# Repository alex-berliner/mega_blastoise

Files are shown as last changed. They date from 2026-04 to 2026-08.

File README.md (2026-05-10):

# mega_blastoise

**[▶ Play live](https://alex-berliner.github.io/mega_blastoise/)** — browser-based Gen 1 random battle simulator

Workspace layout: `mega_blastoise_core` (no_std + battle data), `mega_blastoise_fw` (RP2040), `mega_blastoise_test` (PC).

Architecture overview: see [architecture/README.md](./architecture/README.md).

## Documentation

- [DESIGN.md](./DESIGN.md) — project overview, gameplay, hardware summary, and status
- [ELECTRONICS.md](./ELECTRONICS.md) — GPIO map, wiring, power budget, physical layout
- [TECHNICAL.md](./TECHNICAL.md) — software internals, crate layout, interfaces, data flow
- [specs.md](./specs.md) — full specification and architecture reference
- [architecture/](./architecture/README.md) — deep-dive architecture docs (7 pages)

## Docker / Podman

Run the interactive battle without installing Rust or any native deps:

```bash
# Build once
podman build -t mega-blastoise-test .   # or: docker build ...

# Play
podman run -i --rm mega-blastoise-test
```

`-i` is required — the binary reads moves from stdin.

## Run modes (`mega-blastoise-test`)

The host binary is **interactive only**: stdin battle with the same **typed `BoardEvent` → `BoardEffects`** path as firmware (queue, prompts, combat log).

| Mode | Command | What it does |
|---|---|---|
| **Interactive** (default) | `cargo run -p mega-blastoise-test`<br>`cargo run -p mega-blastoise-test --release` | Full battle over stdin (pick moves / switches when prompted). |
| **Automated tests** | `cargo test -p mega-blastoise-test` | Runs Rust tests (board-event parsing, scripted effect pipeline, demo battle init). Pass/fail exit status. |

Firmware (`mega-blastoise-fw`) has no CLI modes; flash and run as usual (see below).

## Compile

From this directory (`mega_blastoise/mega_blastoise/`, where the workspace `Cargo.toml` lives):

**PC test (host):**

```bash
cargo build -p mega-blastoise-test
cargo run -p mega-blastoise-test
```

Add `--release` to `cargo run` for a faster binary. See **Run modes** for `cargo test`.

**Pico / RP2040 firmware:** install the Rust target once:

```bash
rustup target add thumbv6m-none-eabi
```

Then either pass the target explicitly (recommended when building from the **workspace root** — Cargo does not apply `mega_blastoise_fw/.cargo/config.toml`’s default target for `-p` builds):

```bash
cargo build -p mega-blastoise-fw --target thumbv6m-none-eabi
cargo build -p mega-blastoise-fw --target thumbv6m-none-eabi --release
```

**Firmware size stats** (prints section totals after link — install `rustup component add llvm-tools-preview` for `llvm-size`, or use `arm-none-eabi-size` from the GNU Arm toolchain):

```bash
./scripts/fw-build.sh                    # debug + llvm-size -t / -A
PROFILE=release ./scripts/fw-build.sh    # release build + stats
./scripts/fw-build.sh --release          # same (cargo passes --release)
```

Debug binaries include large `.debug_*` sections, so `llvm-size` totals look huge; prefer **`./scripts/fw-build.sh --release`** when checking flash/RAM against the Pico.

Or `cd` into the firmware crate so its `.cargo/config.toml` sets `thumbv6m-none-eabi` automatically:

```bash
cd mega_blastoise_fw
cargo build
cargo build --release
```

Flash/run with `probe-rs` as configured in `mega_blastoise_fw/.cargo/config.toml`.

**Install `probe-rs`:** download and run the latest installer from the [probe-rs releases page](https://github.com/probe-rs/probe-rs/releases), then reload your shell:

```bash
curl --proto '=https' --tlsv1.2 -LsSf https://github.com/probe-rs/probe-rs/releases/latest/download/probe-rs-tools-installer.sh | sh
source ~/.bashrc   # or ~/.zshrc
```

Then flash with a debug probe connected (e.g. Picoprobe, CMSIS-DAP):

```bash
cd mega_blastoise_fw
cargo run --release
```

### PN532 readers (firmware)

Two **PN532** modules on separate I²C buses (`I2C0` + `I2C1`), default address **0x24** each:

| Bus | SCL (GP) | SDA (GP) |
|-----|---|---|
| I2C0 (reader 0) | GP17 | GP16 |
| I2C1 (reader 1) | GP19 | GP18 |

Startup spawns two embassy tasks that periodically exchange **GetFirmwareVersion** and discard the reply — bring-up traffic only until NFC handling lands.

### Breadboard power (PN532 + Pico)

PN532 boards draw noticeable current when the RF field is active; pulling both from the Pico’s **3V3** pin alone can brown out the Pico regulator or cause flaky I²C.

**Plan for the breadboard stage:**

1. **External brick** — Use a small DC supply (e.g. barrel jack wall wart into a **buck module** or **LM2596-style** board) that exposes stable **5&nbsp;V** and/or **3.3&nbsp;V** rails at enough current for **both** readers plus headroom (hundreds of mA total is a comfortable target for NFC bring-up).

2. **Power the readers from that rail**, not from Pico **3V3**:
   - Many PN532 breakouts accept **5&nbsp;V** on **VIN** and regulate down on-board; follow your module’s silkscreen.
   - If the breakout is **3.3&nbsp;V only**, power it from the external **3.3&nbsp;V** output of the same supply family (not from the Pico pin).

3. **Single ground reference** — Tie **GND** from the barrel/supply module, **Pico GND**, and **both reader GNDs** on one common ground net (breadboard negative rail). I²C only works if grounds are shared.

4. **Pico supply during development** — Easiest: power the Pico over **USB** for flashing/debug while the **external supply feeds only the NFC modules** (still with common GND). Alternatively, feed **5&nbsp;V** into **VSYS** through an appropriate Schottky diode arrangement per Pico docs if you want fully standalone power (more breadboard care).

5. **I²C levels** — RP2040 GPIO is **3.3&nbsp;V** logic. PN532 I²C on common breakouts is 3.3&nbsp;V tolerant; if you ever used a 5&nbsp;V‑only I²C module you would need level shifting (most PN532 boards are 3.3&nbsp;V I²C).

Keep high‑current paths short on the breadboard and avoid routing reader supply current through the Pico pins.

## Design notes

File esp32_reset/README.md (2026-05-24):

# esp32_reset

A tiny hardware recovery line. When an RP2040 in the rig wedges so hard that
nothing software-side can reach it, this ESP32 yanks its `RUN` pin low for
~100 ms to force a clean power-on reset.

Targets: the player **Pico** and the **debug probe** (a Pico running
debugprobe). Triggered by a magic byte over USB.

Standalone crate — **not** in the root workspace (different toolchain +
target). Build it from inside this directory.

## Hardware

DOIT ESP32 DevKit V1 (original ESP32 / WROOM-32, Xtensa). The trigger
arrives over the onboard CP2102 USB↔UART bridge on UART0 — the original
ESP32 has no native USB.

```text
  ESP32 GPIO25 ───────────────► Pico   RUN  (Pico pin 30)
  ESP32 GPIO26 ───────────────► Probe  RUN  (probe Pico pin 30)
  ESP32 GND    ───────────────► common GND   (REQUIRED)
```

- Lines are **open-drain**: ESP32 only ever pulls `RUN` low or floats it
  (Hi-Z). It never drives high. If the ESP32 is unplugged, crashed, or in
  its bootloader, every line is Hi-Z and each RP2040's internal ~50 kΩ
  `RUN` pull-up keeps it running. The fail-safe is structural — no MOSFET,
  no external pull-up, no firmware needed for the safe state.
- A 220 Ω–1 kΩ series resistor per line is an optional nice-to-have for
  protection; not required.
- GPIO25/26 chosen because they're Hi-Z input at power-on, not strapping
  pins, and don't glitch at boot — the ESP32's own power-up can't trip a
  reset.
- **Common ground is mandatory.** Without it, none of this works.

> Bridging instead of separate pins also works (one line to both `RUN`s,
> resets together) — but two pins gives independent reset and avoids one
> powered target weakly back-feeding an unpowered one's `RUN`.

## Protocol

Magic bytes on UART0 @ 115200 (the same port you flash/monitor):

| byte | action |
|---|---|
| `p`  | reset the Pico |
| `d`  | reset the debug probe |
| `b`  | reset both |

Any other byte is ignored, so stray console noise is harmless. Each
accepted command echoes a one-line ack (`RST pico` / `RST probe` /
`RST both`).

## Build & flash

One-time Xtensa toolchain setup (the original ESP32 isn't supported by
upstream Rust):

```sh
cargo install espup espflash
espup install
source ~/export-esp.sh        # add to your shell rc; needed every build shell
```

Then, from this directory:

```sh
cargo run --release           # builds, flashes, opens the monitor
```

`cargo run` uses `espflash flash --monitor` (see `.cargo/config.toml`).
Plain build only: `cargo build --release`.

> esp-hal's API moves fast between releases. Versions are pinned in
> `Cargo.toml` against esp-hal 0.23.x; if a future `espup` toolchain pulls
> incompatible crates, bump the pins together and adjust the few HAL calls
> in `src/main.rs` (init / GPIO / UART).

## Triggering from the host

```sh
./reset.sh pico            # or: probe | both
PORT=/dev/ttyUSB1 ./reset.sh both
```

Or by hand: `printf 'p' > /dev/ttyUSB0` (after `stty -F /dev/ttyUSB0
115200 raw`).

Note: opening the port may toggle DTR/RTS and reset the *ESP32* itself
(not the targets) — harmless, it just re-prints the ready banner.
`reset.sh` uses raw mode to minimize this.

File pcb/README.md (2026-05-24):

# pcb/ — code-defined PCB design

Source-of-truth for the mega_blastoise board wiring as an atopile
project. Mirrors what's described in `../ELECTRONICS.md` but in a form
that a tool can render into a KiCad schematic, BOM, and netlist.

This is the "PCB version" of the design. The current build path is
stripboard + hand wiring (see memory `feedback_stripboard_preference`);
this directory exists so the connectivity is captured as code and so a
fabbed board is a `ato build` away if/when that path makes sense.

## Tool choice

[atopile](https://atopile.io) — purpose-built, code-first DSL for
hardware, designed around the same parametric / source-as-truth
philosophy as `cad/`. Outputs a KiCad 7+ project.

Alternatives considered:

- **SKiDL** (Python library): more mature but writes netlists, not
  full KiCad projects. Pick this if you want to drive layout in
  Python from existing KiCad libraries.
- **KiCad Python API**: scripts existing KiCad — best for layout
  automation, not for from-scratch design.

## Layout

```
pcb/
├── README.md              (this file)
├── ato.yaml               (atopile project config)
└── elec/src/
    └── mega_blastoise.ato (top-level design)
```

## Build

```bash
# one-time
pip install atopile
cd pcb
ato install               # pull standard part library

# every time
ato build                 # emits KiCad project to build/default/
```

Open `build/default/<project>.kicad_pro` in KiCad to inspect the
schematic and lay out the board.

## What's modelled

- Raspberry Pi Pico (treated as a daughterboard, all 26 usable GPIO
  exposed)
- 2x SSD1306 OLED breakouts on independent I2C buses (GP16/17 and
  GP18/19), each with a 100 nF decoupling cap
- 14x tactile buttons arranged as a 4x4 matrix on GP6..GP13
- WS2812B NeoPixel strip header on GP20 with a 330R series resistor on
  data and a 470 uF bulk cap across V5/GND at the strip entry
- Piezo buzzer on GP21
- Power stage: JST-PH LiPo connector + TP4056 charge module + MT3608
  boost (preset to 5 V) + SPDT slide switch -> V5 rail
- Reset button across RUN -> GND (see memory
  `project_reset_button`)
- Error LED stub on GP22 (see memory `project_error_led`) — needs an
  `LED` part imported before `ato build` will succeed

## Known gaps before fabbing

The `.ato` file uses local `component` stubs for the bigger
parts (Pico, OLEDs, TP4056, MT3608, slide switch, JST, headers,
buttons, buzzer). Each one declares only pins and a footprint
hint. Before `ato build` will produce a fabricable board you'll
need to either:

1. swap each stub for a registry-backed `component` (`ato install`
   then `from ... import ...`), or
2. fill in the `footprint` / `mpn` fields and add KiCad symbols
   under `elec/footprints/`.

The connectivity is fully expressed; the work above is part-library
plumbing, not design work.

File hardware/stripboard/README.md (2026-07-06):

# Button matrix - stripboard layout

Permanent stripboard (Veroboard) version of the 4x4 button matrix, replacing the
flaky breadboard build. 14x 6 mm tactile switches, soldered.

Oriented for Alex's board: **strips run vertically, one continuous rail per
letter column (A..X across the top, holes 1..55 down the side).** The layout drops
onto the top of that board, full width (letters A..X), using roughly the first
22 holes.

## Files
- **`mega_blastoise_matrix.diy`** - the matrix layout, for **DIYLC** (DIY Layout
  Creator). Authoritative source for the board: every switch, track cut, jumper.
- **`mega_blastoise_matrix_full.diy`** - the **full system**: the matrix plus
  switch bodies, the Raspberry Pi Pico (40-pin DIL stand-in), both SSD1306 OLEDs,
  both WS2812B strips, the buzzer, all the signal + power wiring, and a parts list.
- **`*_preview.png`** - quick renders of each.
- **`gen_matrix_diy.py`** / **`gen_matrix_full_diy.py`** - regenerate the `.diy`s
  (edit geometry here, not the XML). The full one imports the matrix one.
- **`preview_strip.py`** / **`preview_full.py`** - regenerate the preview PNGs.
- **`verify_matrix.py`** - netlist check of the matrix.

## Opening it
DIYLC is a single jar (needs Java). From the DIYLC folder:
```
java -jar diylc.jar hardware/stripboard/mega_blastoise_matrix.diy
```
(or launch DIYLC and File -> Open). Print at 100 % scale to lay the board on top.

## How the matrix maps to copper
Strips run **vertically** (down the columns), so each vertical letter-strip is one
continuous rail. The matrix uses two kinds of strip:

- **Bus strips** (a whole row net, never cut): one letter each.
  - **GP5** (P1 moves) = strip **V** | **GP7** (P1 party) = strip **P**
  - **GP8** (P2 moves) = strip **J** | **GP9** (P2 party) = strip **D**
- **Node strips** (letters **A, G, M, S**): each carries the column-legs of one
  row net and is **cut between rows** so every column gets an isolated node. The
  four columns are then tied together by **horizontal jumper wires** (the col
  nets **GP10..GP13**), one jumper row per matrix column.

Each switch straddles a bus strip and the node strip 3 letters to its left
(A<->D, G<->J, M<->P, S<->V): both legs of the row terminal land on the bus
strip, both legs of the col terminal on the node strip.

Pico physical-pin numbers below are the RP2040 board's actual header pins (all
on the left column; the Pico puts a GND at every 5th pin, e.g. pins 8 and 13,
which is why the numbering skips).

| Matrix row | Bus strip | | Matrix col | Net | run as |
|---|---|---|---|---|---|
| P1 moves (M1-M4) | **GP5** (pin 7) | | col 0 | **GP10** (pin 14) | jumper row |
| P1 party (S1-S3) | **GP7** (pin 10) | | col 1 | **GP11** (pin 15) | jumper row |
| P2 moves (M1-M4) | **GP8** (pin 11) | | col 2 | **GP12** (pin 16) | jumper row |
| P2 party (S1-S3) | **GP9** (pin 12) | | col 3 | **GP13** (pin 17) | jumper row |

col 3 exists only on the move rows (party rows have 3 buttons).

## Build order
1. **Cut the board** to size (24 wide x ~24 tall is plenty; letters A..X).
2. **Make the track cuts** - every red X in the `.diy`. They sit on the node
   strips (A, G, M, S), between adjacent column groups, isolating each column
   node. Spot cutter or a 3 mm drill twirled by hand; verify each with a meter.
3. **Solder the column jumpers first** (blue horizontals). They run *under* the
   switch bodies, so they go down before the switches. Insulated wire on the
   component side; solder only where they cross a node strip (A/G/M/S), kept
   raised/insulated over the bus strips in between.
4. **Solder the 14 switches.** Solder **all four legs**: the two on the bus-strip
   side become the row terminal, the two on the node-strip side become the col
   terminal (the marked green/blue pair just shows one leg of each). Because both
   legs of a terminal share a strip, this is more robust than the breadboard
   "bend two diagonal legs" trick.
5. **Solder the 8 header wires** (ribbon) to the orange pads -> Pico. Rows exit on
   the bus strips (**GP5/7/8/9**, top of the board); columns exit on the node
   strips at the left (**GP10-GP13**).
6. **Continuity test**: pressing a button connects its row net to its column net
   and *nothing else*.

## Switch footprint
6 mm tactile switches have a ~4.5 x 6.5 mm leg pattern = a **0.2" x 0.3" (3 x 4
hole)** rectangle on the 0.1" grid. This layout matches that: the two legs of one
terminal sit **0.2" (2 holes)** apart along a strip, and the two terminals sit
**0.3" (3 holes / 3 letters)** apart across strips. If your switches measure
differently, edit `VSPAN` / `HSPAN` at the top of `gen_matrix_diy.py` and re-run;
everything else (cuts, jumpers, nets) is footprint-independent.

## Verification
`gen_matrix_diy.py` was checked with a netlist model (strips + cuts + jumpers +
every leg -> union-find nets): all 14 switches connect exactly their row GPIO to
their col GPIO, 8 nets total, no stray shorts.

## Single-board build (whole console on one 24x55 board) - rev 3

> **Building it? Follow [BUILD.md](BUILD.md)** - step-by-step instructions
> (cut list, wire list, solder order, continuity tests) generated from the
> verified model by `gen_build_doc.py`. Regenerate it whenever the layout
> changes.

Column lettering matches the grid **printed on the physical board**: viewed
from the component side (copper down) the printed letters read **X left ->
A right**; they read A..X left-to-right only with the copper side facing you.
All diagrams and docs use the component-side view.
`gen_single_board.py` puts **everything on one stripboard**, arranged for two
players **facing each other** across the board. Outputs
`mega_blastoise_single_board.diy` (+ `_preview.png`). Board top to bottom:

- **P2 module (rotated 180deg)**: party row S3 S2 S1, moves M4 M3, screen
  (header at its bottom edge), moves M2 M1. From P2's seat it reads exactly
  like P1's module. No firmware flip needed: the physical rotation and P2's
  opposite viewing angle cancel out.
- **P1 module**: moves M1 M2, screen (header at its top edge), moves M3 M4,
  party row S1 S2 S3.
- The 4 move buttons of each player sit at the **four corners of their screen**,
  matching where the moves render on the OLED; the 3 party buttons share a row.
- **LED strip connectors on the left edge (col X)**: P2's at the top (rows
  2/5/8), P1's at the bottom (rows 41/44/47), each DIN/5V/GND - out of the
  play area; the WS2812B strips are off-board.
- **holes 47-54**: the **Pico, on the TOP side, USB pointing LEFT** (pin 1 =
  GP0 bottom-left; VBUS n/c), isolation cut lines at holes 46 and 50.
- **hole 53**: **MB102 5V input** - "-" on the left (B), "+" on the right (A).
- **rails**: GND = col W, 3V3 = col B, 5V = col A. MB102 feeds the 5V rail for
  the LED strips; the Pico runs from USB; grounds are shared. (No buzzer.)

All ~41 jumper wires are meant to be routed on the **underside** so the top
stays clean. The `verify()` in the script proves the netlist by union-find
(strips + cuts + jumpers + every pad) and also checks that no hole takes two
wire ends - it must report PASS before the `.diy` is written.

## Firmware
Matches the shipped firmware pin map (`main.rs`): rows GP5/7/8/9, cols GP10-13.
No firmware change needed - drop-in replacement for the breadboard matrix.

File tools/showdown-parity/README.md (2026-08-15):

# Showdown parity

Differential tests: the core engines (`gen1_battle`, `gen3_battle`) against
the real Pokémon Showdown simulator.

    cd tools/showdown-parity && npm install     # arm (one-time, needs network)
    cargo test -p mega-blastoise-test --test showdown_parity

Unarmed checkouts skip the suite loudly and stay green.

Randomness is scripted on both sides, not disabled: each scenario fixes
hit/miss, crit, and the exact damage roll, the harness forces the sim down
that branch (accuracy at the old-gen `randomChance` seam, the roll at
`randomizer`/`random(217,256)`, crits via `willCrit`), and the Rust side takes
the same script through its `*_scripted` seams. Misses spending PP, crit
stage/screen rules, and both roll extremes are all first-class comparisons.

Found on its first runs: two transposed cells in type-chart.json (shipped in
Gen 1 as Bug->Rock x0.5 and Fighting->Dragon x2), Shedinja's 1 HP rule,
the Gen 3 damage roll applying last rather than before STAB, the +2 landing
after burn/screen halving, and one wrong patch added from memory during the
fixing (gen 1 Bug->Ghost is resisted, not super effective).

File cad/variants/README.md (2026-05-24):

# CAD variants

Each `*.scad` here is a complete, standalone enclosure design. Work happens
in these files. **`cad/board.scad` is just a copy of whichever variant is
currently being shown** — the "now showing" / display slot. Don't hand-edit
`board.scad`; edit the variant, then it gets copied up.

Workflow: edit `variants/<name>.scad` → validate via the METHODOLOGY
render+assert loop → `cp variants/<name>.scad ../board.scad` to make it the
active view.

## Variants

| File | Display | Notes |
|---|---|---|
| `dual-oled-128x64.scad` | 2× 128×64 mono SSD1306 (I²C), one per player | Web-mirrored layout: OLED + 4 corner move btns + 3-switch row + 1 HP LED + 3 party LEDs per player; centred buzzer. ~71×133×13.5 mm. The committed baseline. |
| `single-st7789.scad` | 1× ST7789 240×240 colour TFT (SPI), shared central | Per-player button block (4 move + 3 switch) + LEDs flanking the screen; buzzer beside display. Colour → sprites. Shared screen = upright for one player only (suits a Stadium-style shared battle view). ~68×121×13.5 mm. |
| `single-st7789-nfc.scad` | ST7789 (as above) + NFC coin select | Drops the 3 switch buttons; per player an octagonal recess (≈24.8 mm, 0.9 mm floor so NFC reads through) + thumb notch for a flat NFC "Pokémon coin". 4 move btns stay. Assumes a per-player PN532-class reader (ghosted; NFC is electronics-out-of-scope today). ~68×149×13.5 mm. |

| `nintendo-style.scad` | ST7789 + amiibo-style NFC | The Yokoi/Iwata take: NFC antenna behind the screen (no slot, nothing to lose; buttons kept so base game needs no accessory), screws hidden on the bottom (clean play face), rounded chamfered shell, raised molded-key bezels, speaker grille, sized for hand-feel. ~70×123×14 mm. |

Currently active in `../board.scad`: **nintendo-style**.

All variants share the METHODOLOGY render+assert loop and the
`part`/`cut`/`check`/`show_ghosts` selectors. STLs are gitignored
(regenerate from whichever variant).

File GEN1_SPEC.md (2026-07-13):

# Gen 1 Battle Engine Spec (`gen1_battle`)

Cartridge-accurate RBY mechanics. Goal: drop-in replacement for the `battler` crate in `mega_blastoise_core`/`_fw` consumption, with ~800 B of RAM per 6v6 battle and zero per-turn heap churn.

Authoritative sources cited inline:
- **pret/pokered** — RBY disassembly. Definitive. https://github.com/pret/pokered
- **Pokémon Showdown gen1 mod** — `data/mods/gen1/{scripts,moves,conditions,typechart}.ts`;
  the community's cartridge-verified reference implementation. The engine's
  battle semantics are ported from it (2026-07: full glitch pass — sticky
  modified stats, toxic counter, last-damage register, per-action residuals).
- **Bulbapedia** — Gen I damage / status / move mechanics pages
- **Smogon Gen 1 OU / RBY mechanics writeups**

When this doc and pret/pokered disagree, pret wins. Move data (power/type/
accuracy/pp/effect) is generated from pret's `data/moves/moves.asm`
(vendored as `data/rby_moves.json`); species stats and Gen 1 typing from
Showdown's gen1 pokedex (`data/rby_species.json`).

---

## 1. Memory layout targets

### Per-Pokemon runtime state (`Mon`) — target ≤ 64 B

| Field | Size | Notes |
|---|---|---|
| `species: u8` | 1 | 151 species fit in 1 byte (0 = empty slot) |
| `level: u8` | 1 | 1–100 |
| `hp_cur: u16` | 2 | |
| `hp_max: u16` | 2 | |
| `status: u8` | 1 | `0bABCD_EEEE` where E = sleep counter (0–7), A=PSN, B=BRN, C=FRZ, D=PAR; BadPSN = PSN-bit set + bit in `volatile`. See §6. |
| `moves: [MoveSlot; 4]` | 12 | each `(id: u8, pp: u8, max_pp: u8)` = 3 B |
| `stats: [u16; 5]` | 10 | HP/Atk/Def/Spc/Speed (Gen 1 — no Sp.Atk/Sp.Def split) |
| `ivs: [u8; 4]` | 4 | Atk/Def/Spc/Speed IVs (4-bit each, packed); HP IV derived from LSBs |
| `stat_stages: [i8; 4]` | 4 | Atk/Def/Spc/Speed modifier stages (−6..+6). HP not modifiable. |
| `volatile: u32` | 4 | Bitflags: Confused, ConfusedTurns(3b), Flinched, LeechSeeded, Substituted, SubstituteHp(8b), MustRecharge, Biding, BideDmg(16b — overlap ok via separate field), Disabled, DisabledMoveSlot(2b), DisabledTurns(3b), WrappedBy(self-side / locked-into-Wrap), MultiTurnMoveId(8b), MultiTurnTurnsLeft(3b), ReflectActive, LightScreenActive, FocusEnergyActive, MistActive, BadPoisonCounter(4b) |
| `last_move_used: u8` | 1 | move id (0 = none); used by Mirror Move |
| `last_move_targeted_by_normal_or_fighting: u16` | 2 | Counter source damage. 0 if not eligible. |
| Padding/alignment | ~5 | |

→ ~52 B packed, ~64 B with alignment. Two teams × 6 = **768 B** for both rosters. Add `Battle` (active idx, turn counter, RNG, weather=none, choice buffers, narration ring) ≈ 200 B. **Total battle RAM ≤ 1 KB.**

### Static data tables (in flash)

| Table | Entries | Per-entry | Size |
|---|---|---|---|
| `SPECIES: &[SpeciesData; 151]` | 151 | 32 B (id, name_idx, base_stats×5, types×2, catch_rate, base_exp, growth_rate, learnset_ptr) | ~5 KB |
| `MOVES: &[MoveData; 165]` | 165 | 24 B (id, name_idx, type, category, power, accuracy, pp, target, effect_kind, effect_param×2) | ~4 KB |
| `TYPE_CHART: [[u8; 15]; 15]` | 225 | 1 B (0=immune, 5=½, 10=1×, 20=2×) | 225 B |
| `NAME_STRINGS: &[&'static str]` | ~316 | pointer | ~2.5 KB |
| `LEARNSETS: &'static […]` | learn entries | (level, move_id) packed | ~2 KB |

→ **~13 KB of flash**, zero heap.

---

## 2. Damage formula (Gen 1, cartridge-accurate)

Source: pret/pokered `engine/battle/core.asm` (`DamageCalc`), Bulbapedia "Damage" Gen I section.

```
1. If move power == 0:           damage = 0; skip
2. If self-targeted boost-only:  damage = 0; skip
3. atk, def = MODIFIED stats (see §3); use Special for Special category, else Phys.
   - if crit: level *= 2, and atk/def = the UNMODIFIED final stats
     (crits ignore stat stages, par/brn drops, AND screens — the level
     doubling is how Gen 1 implements the crit multiplier)
4. Reflect doubles Def for Physical hits against you; Light Screen doubles Spc
   (non-crit only), BEFORE the ≥256 check below.
5. If atk ≥ 256 or def ≥ 256: atk = max(1, (atk/4) % 256); def = (def/4) % 256.
   The %256 rollover is the cartridge 8-bit truncation (it's why Reflect can
   INCREASE damage taken). def == 0 would crash a real cartridge (division by
   zero freeze); we clamp to 1 like Showdown.
6. Explosion/Self-Destruct: def = max(1, def / 2).
7. damage = ((2*level/5 + 2) * power * atk / def / 50), capped at 997, then +2
8. STAB: damage += damage / 2
9. type_effectiveness per defender type slot, in order (×20/10 or ×5/10)
   - if damage becomes 0 → the move MISSES (Gen 1 "0 damage glitch")
10. if damage > 1: damage = damage * rand(217..=255) / 255
```

### Notable Gen 1 quirks (all implemented)
- **Crits double the level term** (not the final damage) and ignore stat
  stages, sticky par/brn drops, and screens on BOTH sides.
- **Stat ≥ 256 rollover**: both stats /4 with 8-bit truncation. At level 100
  this fires in most matchups and materially changes damage.
- **Random factor**: uniform 217..=255, applied only when damage > 1.
- **Damage 0 = miss**, not min-1 (possible when a 2-3 base result meets a
  4× resist).
- Type immunity is checked BEFORE the accuracy roll; status moves ignore the
  chart entirely (Thunder Wave paralyzes Ground-types), and fixed-damage /
  trapping moves carry an ignore-immunity flag (Sonic Boom hits Gengar,
  Wrap traps Ghosts for 0 damage).

---

## 3. Stat modifier formula

Source: pret `core.asm` (`ApplyBadgeStatBoosts` is irrelevant in link play; `CalculateModifyStats`).

```
Stages: -6..+6
Multiplier table (numerator/denominator):
  -6: 25/100,  -5: 28/100, -4: 33/100, -3: 40/100, -2: 50/100, -1: 66/100,
   0: 100/100,
  +1: 150/100, +2: 200/100, +3: 250/100, +4: 300/100, +5: 350/100, +6: 400/100

effective = (base_stat * num) / den
Clamp: 1..=999 (Gen 1 cap is 999, not 1023)
```

### Gen 1 quirks — "stat modification errors" (all implemented)
Each mon carries **modified stats** alongside its immutable final stats:
- **Status drops apply once, in place**: paralysis quarters the modified
  Speed, burn halves the modified Attack — at infliction, at switch-in, and
  on every re-stack (below). They are NOT recomputed per damage calc.
- **Any stage change recalculates that modified stat from scratch**, ERASING
  the par/brn drop (a paralyzed mon using Agility loses the Speed penalty
  entirely). Curing the status does NOT restore the stat either.
- **Re-stack bug**: whenever a stat-affecting move lands, the non-acting
  side's par/brn drop is applied AGAIN onto its modified stat (compounding
  /4 Speed, /2 Attack) — so the opponent boosting against your paralyzed mon
  keeps shrinking its Speed.
- **Boost at 999 / drop at 1**: the stage rises then drops one, the stat
  stays pinned, and the move counts as failed (no re-stack).
- Boost moves already at ±6 fail outright.

---

## 4. Crit chance and accuracy

### Crit
Source: pret `core.asm` `CriticalHitTest`.

```
crit_chance_byte = base_speed / 2         ; UNMODIFIED base speed
if move is High-Crit (Crabhammer, Karate Chop, Razor Leaf, Slash):
    crit_chance_byte *= 8
    clamp to 255
if Focus Energy active:
    crit_chance_byte = crit_chance_byte / 4   ; BUG: should be *4
    clamp to 255

random_byte = rand
crit if random_byte < crit_chance_byte
```

- Use base species speed, never modified.
- Focus Energy is reversed (REDUCES crit rate). **Implement as-is** for cartridge accuracy.

### Accuracy
Source: pret `core.asm` `MoveHitTest`.

```
1. If move always hits (Swift, Bide-store): hit, skip
2. accuracy = move.accuracy            ; e.g. 100 -> 255 (* 255 / 100, truncated)
3. accuracy = accuracy * acc_stage_mult / 100
4. accuracy = accuracy * (100 / evade_stage_mult) / 100
5. random_byte = rand
   if random_byte >= accuracy: MISS
```

- **1/256 miss bug**: even at "100% accuracy" the truncation `100 * 255 / 100 = 255` means random_byte must be `< 255`, so a roll of `255` misses. → ~1/256 miss probability for any non-Swift move.
- **OHKO moves**: extra rule before the accuracy roll: if user_speed < target_speed, the OHKO move **always misses** ("It doesn't affect [foe]"). Otherwise it uses 30% accuracy. Source: pret `OHKOMoveEffect`.

---

## 5. Turn structure

Source: pret `core.asm` `MainBattleLoop`.

```
Per turn:
1. Get player choice + AI/opponent choice
2. Choice validation (locked moves override; empty PP pool forces Struggle)
3. Selections register (Counter reads the opponent's SELECTED move)
4. Determine order:
   switches first
   else: priority bracket (Quick Attack +1, Counter -1)
   else: higher MODIFIED Speed
   else: random (50/50)
5. For each side in order:
   a. Faint check — if the actor fainted earlier this turn, skip
   b. PreMove status checks (cartridge order):
      - Haze-cured slp/frz this turn: lose the action
      - Frozen: skip. Never consumes the recharge flag (Hyper Beam + Freeze
        leaves the user stuck recharging).
      - Sleeping: decrement; at 0 wake but STILL lose the turn.
        Sleep/freeze clear the mon's last-move (Mirror Move fails).
      - Partially trapped: skip
      - Flinched: skip; clear flinch
      - Recharge: skip; clear recharge
      - Disabled: tick down; if the chosen slot is the disabled one, fail
        (drops a charge lock, keeps invulnerability)
      - Confused (BEFORE paralysis): tick down; 50% self-hit with 40-power
        typeless attack off MODIFIED stats — counterable, misdirected onto
        the FOE's Substitute if the confused mon has one, cancels
        Bide/charge/trap/Thrash locks INCLUDING invulnerability
      - Paralyzed: 63/256 fully paralyzed — cancels the same locks but
        LEAVES Fly/Dig invulnerability stuck (invulnerability glitch)
   c. Use move (PP: locked continuations free; two-turn moves pay on release)
   d. RESIDUALS for the acting side (Gen 1: after each action, NOT at EOT):
      - brn/psn: 1/16 × toxic counter (if one is live; not incremented)
      - tox: counter += 1, then 1/16 × counter
      - Leech Seed: shares AND increments the toxic counter; the seeder's
        heal is not capped by the victim's remaining HP
      All residual damage feeds the last-damage register (Counter can
      counter a poison tick).
   e. If EITHER active fainted, the turn ends — the other action is lost
6. End-of-turn cleanup: flinch clears; a partial-trap victim is freed once
   the trapper's lock is gone
7. Faint resolution: forced switch; switch-in reapplies the par/brn stat
   drop and immediately ticks flat 1/16 psn/brn damage
8. Win check
```

### Gen 1 quirks (all implemented)
- **Last-damage register** (`Field::last_damage`): global, persists across
  turns, reset only by moves outside the cartridge skip-list. Counter deals
  2× it; Bide adds it every Bide turn (stale re-adds included).
- **Quick Attack +1 / Counter -1** priority brackets; ties are 50/50.
- PP underflow glitches: not implemented (see §13).

---

## 6. Status effects

| Status | Encoding | Effect | Cure |
|---|---|---|---|
| PSN | `Status::Poison` | 1/16 max HP after own action (× live toxic counter) | Rest / Haze (foe's) |
| BRN | `Status::Burn` | 1/16 after own action (× counter); halves modified Atk (sticky — see §3) | Rest / Haze |
| FRZ | `Status::Freeze` | Cannot act. **Cannot thaw on own.** Thawed only by a Fire move with a burn chance (Ember/Flamethrower/Fire Blast/Fire Punch — NOT Fire Spin), or Haze | Fire hit / Haze / Rest overwrite |
| SLP | `Status::Sleep(1..=7)` | Counter -- each PreMove; hitting 0 wakes but that turn is LOST | Counter expiration / Haze |
| PAR | `Status::Paralysis` | 63/256 fail to act; quarters modified Speed (sticky) | Rest / Haze |
| BAD_PSN | `Status::BadPoison` + `toxic_counter` volatile | counter += 1 then counter × 1/16 after own action. **The counter is a separate volatile: it survives Rest** (and then multiplies plain psn/brn damage without incrementing), Leech Seed shares AND increments it, and it dies on switch (tox downgrades to psn). | Rest keeps the counter; switch/Haze clear it |

**Mutually exclusive**: only one major status at a time. Sleep moves used on
a RECHARGING target bypass accuracy and overwrite any existing status.
**Volatile** statuses (confusion, leech seed, sub, etc.) stack with major.

### Sleep mechanics
- Counter rolls 1..=7. Each PreMove, decrement; at 0 the mon wakes and still
  loses that turn (total lost turns = the rolled counter).
- Rest sets counter to 2 (two lost turns), overwrites ANY status including
  Freeze, and does NOT restore par/brn stat drops or reset the toxic counter.
- Recovery bug: Recover/Softboiled/Rest FAIL when max−cur HP is exactly 255
  or 511 (unless cur ≡ 0 mod 256).

### Freeze
- 100% lockout; thaw only via burn-chance Fire moves or Haze. A frozen mon
  never consumes a pending Hyper Beam recharge flag (permanent-recharge bug),
  and Haze-thawing a mon that hasn't acted costs it that turn.

---

## 7. `MoveEffectKind` enum (~30 variants)

This is the lookup table for what a move does on hit. Each move has a single `effect_kind`; weird moves get special-cased (§8).

```rust
#[repr(u8)]
pub enum MoveEffectKind {
    /// Plain damaging move with no rider.
    Damage,
    /// Damage + chance to inflict status. param0=status, param1=chance/256.
    DamageAndMaybeStatus,
    /// Damage + chance to flinch. param0=chance/256.
    DamageAndMaybeFlinch,
    /// Damage + stage change on target. param0=stat, param1=delta i8, param2=chance/256.
    DamageAndMaybeBoostTarget,
    /// Damage + stage change on self. (Swords Dance-on-hit kind of moves; n/a in Gen 1 ... but used by Hi Jump Kick etc.)
    DamageAndMaybeBoostSelf,
    /// Stage change on self only. param0=stat, param1=delta.
    BoostSelf,
    /// Stage change on target only. param0=stat, param1=delta.
    BoostTarget,
    /// Inflict status on target (always). param0=status.
    StatusOnly,
    /// Multi-hit damaging (2-5 hits, weighted 3/8 each for 2-3, 1/8 for 4-5).
    MultiHit2to5,
    /// Multi-hit fixed (Double Kick: 2; Twineedle: 2 + poison chance).
    MultiHitFixed,
    /// Drain HP (% of damage dealt heals user). param0=numerator, param1=denominator. (½ for Mega Drain, Giga Drain not in Gen 1.)
    DrainHp,
    /// Recoil 1/4 of damage dealt.
    Recoil1of4,
    /// Take Down recoil = 1/4; Double-Edge = 1/4 in Gen 1 (not 1/3).
    /// Crash damage on miss: Hi Jump Kick / Jump Kick. 1 HP self damage in Gen 1 (NOT 1/8 like later gens).
    CrashOnMiss,
    /// OHKO move (Fissure, Horn Drill, Guillotine).
    Ohko,
    /// Force target to switch (Whirlwind, Roar — Gen 1: ALWAYS FAILS in trainer battles; only works in wild).
    ForceSwitchTarget,
    /// Fixed damage equal to user's level (Night Shade, Seismic Toss).
    LevelDamage,
    /// Fixed damage of param0 HP (Sonic Boom = 20, Dragon Rage = 40).
    FlatDamage,
    /// Variable fixed damage 1..=1.5*level (Psywave). Actually random byte in 0..=1.5*level.
    Psywave,
    /// Set target HP to 50% (Super Fang).
    HalfHp,
    /// Heal self by 1/2 max HP (Recover, Soft-Boiled, Rest also uses).
    HealHalf,
    /// Rest: full heal + sleep counter set 2.
    Rest,
    /// Two-turn (charge then attack): Solar Beam, Sky Attack, Razor Wind, Skull Bash, Fly, Dig.
    /// param0=invulnerable_phase (0/1).
    TwoTurn,
    /// Bide: store damage 2-3 turns, return 2x.
    Bide,
    /// Hyper Beam (recharge required UNLESS KO).
    HyperBeam,
    /// Counter (mirror back 2x last Normal/Fighting damage targeting self).
    Counter,
    /// Mirror Move (use opponent's last move).
    MirrorMove,
    /// Mimic (replace random move slot with target's last move; PP=5).
    Mimic,
    /// Transform (copy target's species/stats/moves/types/stages; HP unchanged).
    Transform,
    /// Substitute (1/4 HP + 1 sub).
    Substitute,
    /// Disable (random target move, 1-6 turns).
    Disable,
    /// Wrap-like (lock target for 2-5 turns; trapped can't switch; small damage per turn).
    Wrap,
    /// Leech Seed (volatile, drains 1/16 EOT).
    LeechSeed,
    /// Light Screen (Spc damage doublers for 5+ turns).
    LightScreen,
    /// Reflect (Phys defense doublers for 5+ turns).
    Reflect,
    /// Mist (immune to stat reductions while active).
    Mist,
    /// Focus Energy (modifies crit rate, BUGGED in Gen 1 to lower).
    FocusEnergy,
    /// Conversion (copy target's type onto self).
    Conversion,
    /// Haze (clears all stat stages on both sides + status of opponent? — Gen 1 hazes status of opponent too).
    Haze,
    /// Metronome (random move 1..=164, excluding Metronome and Struggle).
    Metronome,
    /// Pay Day (deal damage; if it hits, sprinkle coins — implement as no-op narration).
    PayDay,
    /// Splash / Self-status no-op.
    NoOp,
    /// Explosion / Self-Destruct (high-power phys, halves target Def, KOs user; in Gen 1 halves *defense*, not damage).
    SelfDestruct,
}
```

This list is exhaustive for Gen 1; any move maps to exactly one variant, with the `param` slots in `MoveData` filling in chance/stat/delta etc.

---

## 8. Special-case moves

These get hand-written functions because their behavior is too unique for a single enum variant:

| Move | Behavior |
|---|---|
| **Counter** | Stores last hit damage taken from a Normal/Fighting damaging move *this turn*. Deals 2× back. Selects via `effect_kind = Counter`; logic in `apply_counter()`. |
| **Mirror Move** | Looks at target's `last_move_used`. If valid, recurses move execution with that move (no PP cost). If target has no last move, "Mirror Move failed!". |
| **Mimic** | Picks one of target's known moves at random; replaces user's Mimic slot with it (PP=5). Lasts until switch. |
| **Transform** | Copies species byte, types, stats (incl. stages), and moves (each with PP=5) from target. Volatile flag set; cleared on switch. |
| **Substitute** | Costs 1/4 max HP; sub has 1/4 max HP + 1. Fails if user has ≤ 1/4 HP. While active, all damage applies to sub HP; sub breaks when HP would go ≤ 0. **Bug: an attack dealing exact-HP damage breaks the sub** because sub_hp -= dmg goes 0, not -1. Confusion self-hit ignores sub. |
| **Disable** | Picks one of target's moves with PP > 0, disables it for 1..=8 turns. Fails if target has no moves with PP. Cleared on switch. |
| **Bide** | Turn 1: announce "started storing energy". Turn 2: continue. Turn 3 (or random 2/3): unleash 2× stored damage. Stores damage TAKEN, not dealt. Move always succeeds in unleash phase (no accuracy roll). |
| **Hyper Beam** | After dealing damage, if target NOT fainted, user gains `MustRecharge` and next turn is wasted on "must recharge". **If target fainted, no recharge.** |
| **Metronome** | Roll 1..=165, skip Metronome (and Struggle). Execute that move with no PP deduction. |
| **Conversion** | Copy target's primary + secondary type onto user (or just primary if single-typed). |
| **Haze** | Reset all stat stages on both sides to 0; clear opponent's non-volatile status; clear own confusion. (Gen 1 — see Bulbapedia.) |
| **Rest** | Restore full HP, set SLP counter to 2, cure other major statuses. Cannot be used at full HP. |
| **Wrap / Bind / Fire Spin / Clamp** | Lock target for 2..=5 turns; user can attack only with this move; target cannot move. Tiny damage (1/16 max) each turn. If user switches, target frees. |

---

## 9. Random battle teambuilder

Source: this is *not* cartridge — Smogon randbats use their own distributions. We'll do simplest plausible:

```
For each side, 6 species (sample without replacement from SPECIES, exclude legendaries optionally).
For each mon:
    level = 100
    IVs = max (15/15/15/15) for simplicity
    moves = 4 moves chosen from species learnset (level 1..=level)
             filter: prefer damaging, then status, then utility — or simpler: random 4
    HP recalc per Gen 1 formula
```

The `draw_two_randbat_teams(seed, n)` API in `mega_blastoise_core/src/randbat.rs` is the existing entry point. We'll port it to use `gen1_battle`'s tables.

---

## 10. API mimicry surface

The new crate exposes types/methods to satisfy these existing callsites:

### Types
```rust
pub struct Battle<'a> { /* opaque */ }
pub struct CoreBattleOptions { pub seed: Option<u64>, ... }
pub struct CoreBattleEngineOptions { ... }
pub struct PlayerData { pub id: String, pub name: String, ... }
pub struct TeamData { pub members: Vec<MonData>, ... }
pub struct MonData { pub species: ..., pub level: u8, pub moves: Vec<MoveSlot>, ... }
pub struct MonBattleData { pub active: bool, pub summary: MonSummary, pub moves: Vec<MoveSlot>, ... }
pub struct PlayerBattleData { pub mons: Vec<MonBattleData>, ... }
pub enum Request { Turn { ... }, Switch { ... }, TeamPreview { ... } }
pub enum Type { Normal, Fire, Water, ... }  // identical variants to battler::Type
pub enum Stat { Hp, Atk, Def, Spc, Speed }  // Gen 1 — no SpAtk/SpDef
```

### Methods
```rust
impl<'a> Battle<'a> {
    pub fn new(opts: CoreBattleOptions, data: &dyn DataStore, engine: CoreBattleEngineOptions) -> Result<Self>;
    pub fn update_team(&mut self, player_id: &str, team: TeamData) -> Result<()>;
    pub fn start(&mut self) -> Result<()>;
    pub fn active_requests(&self) -> impl Iterator<Item = (&str, &Request)>;
    pub fn set_player_choice(&mut self, player_id: &str, choice: &str) -> Result<()>;
    pub fn new_log_entries(&mut self) -> impl Iterator<Item = &str>;
    pub fn ended(&self) -> bool;
    pub fn player_data(&self, player_id: &str) -> Result<PlayerBattleData>;
    pub fn active_mon_move_pp(&self, player_id: &str) -> Option<Vec<(u8, u8)>>;
    pub fn drain_action_timings(&mut self) -> impl Iterator<Item = (&str, u32)>;
}
```

Choice string format (kept identical to battler so the AI / USB cmd parser doesn't change):
- `"move 1"`, `"move 2"`, ...
- `"switch 3"` (switch to team slot 3)
- `"team 1 2 3 4 5 6"` (team preview — Gen 1 doesn't actually use this in randbats but kept for compat)

---

## 11. RNG

Single `u64` LCG/xorshift state stored in `Battle`. All randomness routed through one `Battle::rand_byte() -> u8` / `Battle::rand_range(n) -> u8`. Seeded from `CoreBattleOptions::seed`.

This is the only place randomness happens; **no `rand` crate, no thread-local**. Same seed → same battle, reproducibly.

---

## 12. Narration / log

A small ring buffer of `Event`s (enum, fixed size each):

```rust
pub enum Event {
    MoveUsed { user: SideMonIdx, move_id: u8 },
    Damage   { target: SideMonIdx, dealt: u16 },
    Miss     { user: SideMonIdx },
    Crit     { user: SideMonIdx },
    SuperEffective,
    NotVeryEffective,
    Immune,
    StatusInflicted { target: SideMonIdx, status: Status },
    StatChanged { target: SideMonIdx, stat: Stat, delta: i8 },
    SwitchIn { side: u8, slot: u8 },
    Faint    { side: u8, slot: u8 },
    Win      { side: u8 },
    // ... ~20 total
}
```

`new_log_entries()` formats these into strings *on demand* at the API boundary (only when called). The strings allocate then, but they're consumed and dropped by the caller (`battle_runner::enrich_and_dispatch`) per turn — no accumulation. Ring buffer size: 128 events (4 KB at most).

---

## 13. Known gaps / TODOs (deliberately not implemented)

- **PP underflow glitches** (0-PP forced moves rolling to 63 PP, Struggle
  bypassing, Transform PP errors): cartridge memory corruption, out of scope.
- **Division-by-zero freeze**: we clamp defense to 1 instead of hanging.
- **Psywave levels 0/1/171 softlock**: range floored at 1 instead.
- **Link-battle desyncs** (Mirror Move / Psywave / Counter desyncs): single
  engine, nothing to desync — Counter uses Showdown's Desync Clause reading.
- **Badge boosts**: link battles don't have them.

### Format rules (Gen 1 randbats ruleset — implemented, always on)
- **Sleep Clause Mod**: an enemy sleep move fails while the target's side
  already has a mon sleeping from an enemy move (`Mon::rest_sleep` marks the
  exempt Rest case). When it blocks the sleep-vs-recharge bug, the recharge
  flag is NOT cleared (matches Showdown).
- **Freeze Clause Mod**: a freeze secondary fizzles while the target's side
  already has a frozen mon.
- **Endless Battle Clause**: hard cap at 1000 turns. Showdown ties; this API
  has no tie, so the side with the higher remaining-HP fraction wins (battle
  RNG coin flip on an exact tie). Deliberate deviation, documented here.
- Species/OHKO/Evasion clauses are TEAM-validation rules — the vendored
  Showdown randbat sets already satisfy them, so the engine doesn't check.
- AI move choice: not the engine's concern; `RandomAi` already exists outside the engine.

Implemented glitch coverage (see `tests/quirks.rs`): 1/256 miss, 0-damage
miss, Focus Energy bug, base-Speed crit with doubled-level crit formula,
stat ≥256 rollover, sticky modified stats + re-stack, toxic counter
(Rest/Leech Seed interactions), recovery-fail 255/511, fire-thaw,
Hyper Beam (KO / sub-break / freeze / sleep-overwrite interactions),
secondary-status shared-type immunity, invulnerability glitch, Swift
through Fly/Dig, Substitute suite (exact-quarter faint, confusion
misdirection, Explosion sub-break survival), Bide stale-register
accumulation, Thrash/Rage locks with the compounding accuracy bug,
partial-trap lock semantics, Counter via the last-damage register,
per-action residuals, faint-ends-turn.

---

## 14. Testing strategy

Three layers:
1. **Unit tests for damage formula**: assert known cartridge results, e.g. "L100 Tauros body slamming L100 Snorlax does X HP per damage roll".
2. **Move-effect fixture tests**: one per `MoveEffectKind` variant covering basic case + edge cases (immune type, crit, low HP, etc.).
3. **End-to-end deterministic battles**: seed + scripted choices → expected final HP / win. Sourced from real Smogon RBY randbat replays if available.

Run on host (`cargo test -p gen1_battle`) — no firmware roundtrip needed for engine tests.

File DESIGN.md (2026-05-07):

# Mega Blastoise — Project Overview

A self-contained two-player Pokémon Generation 1 battle game that runs entirely on a Raspberry Pi Pico. No phone, no PC, no internet. Two players sit across a portable board, pick a team, and battle in 3v3 matches with full Gen 1 mechanics — type effectiveness, status effects, damage rolls, critical hits — all driven by an open-source battle engine.

The first version is designed for **demoing at conventions** (Open Sauce 2026). That shapes most of the design choices: fast setup, no fragile parts, intuitive enough that two strangers can sit down and play their first match within 15 seconds of approaching the board.

---

## Why This Exists

The goal is a physical artifact that feels like a purpose-built game device — not an emulator, not a phone app. The board should be something you can hand to anyone and play without setup. All game logic runs on a $4 microcontroller.

Gen 1 Pokémon is the right scope: well-understood rules, no abilities or items to implement, small enough to fit entirely in flash memory, and nostalgic enough that people immediately get it. The presentation reference is **Pokémon Stadium** — dramatic per-hit feedback, HP bars draining LED-by-LED, attack flashes, victory fanfares.

---

## What Playing It Looks Like

A complete game session, end to end:

**1. Idle.** When no one's playing, the board is in attract mode. The buzzer chimes a quick battle jingle every 30 seconds, all 24 LEDs pulse softly, and the OLED displays alternate between "PLAY" and "ME". Hard to ignore.

**2. Sit down.** Two players sit on opposite sides of the board. The first player to press any button kicks off a **mystery draft**: each player's three Pokémon are revealed one at a time on their personal OLED display, with sprite art, name, and a fanfare beep per reveal. ~15 seconds of theatre.

**3. Battle starts.** "Trainers ready!" — both OLEDs swap to your active Pokémon's portrait, HP bars light up to full green, the buzzer plays a ready-up chord. Move buttons pulse under your fingers.

**4. Pick a move.** Your OLED shows your active Pokémon and a numbered list of its four moves. Press a button to commit. **Hold a button** to inspect the move first — name, type, power, accuracy, secondary effects. Both players pick simultaneously; whoever's faster acts first.

**5. Moves resolve.** The attacker's LED strip flashes the move's type color. The defender's HP bar drains LED-by-LED with a single buzzer hit. Numbers update. Snappy — about 4 seconds per turn.

**6. Status effects** show up as a small sprite tag on the OLED, a colored status LED, and — to teach what each status actually does — a brief tint of the affected player's HP bar in the status's color.

**7. A Pokémon faints.** Their party-slot LED fades to black. A short "down" tone plays. The OLED shows a grayed-out sprite, then prompts you to pick a replacement from your remaining team. Meanwhile your opponent's OLED shows your remaining Pokémon's HP and types — a tactical timeout that gives both players a moment to think.

**8. The battle ends.** When the last Pokémon falls, both OLEDs show a short stat recap (damage dealt, crits landed, turns elapsed) before the winner's side erupts in a victory fanfare and the loser's side dims.

**9. Replay.** "Press any button to play again." Ten seconds of inactivity returns the board to attract mode for the next pair of strangers.

---

## Hardware at a Glance

| What | Why |
|---|-----|
| Raspberry Pi Pico (RP2040) | Runs everything — $4, capable enough, great LED hardware |
| WS2812B NeoPixel strip (×24) | HP bars, party status, attack flashes, faint animations |
| 2× 128×64 monochrome OLED | One per player — sprites, move lists, tooltips, MVP recap |
| Tactile buttons (×14) | 4 move + 3 party buttons per player |
| Piezo buzzer | Audio cues — every action has a sound |
| LiPo battery + boost converter | Untethered, runs all day on a charge |

For physical layout, wiring, and GPIO assignment, see [ELECTRONICS.md](./ELECTRONICS.md).

---

## What's Working / What's Left

| Area | Status |
|---|---|
| Battle engine — full Gen 1 rules | Working |
| Play over USB serial (laptop) | Working |
| Button matrix input | Not started |
| OLED sprite + UI rendering | Not started |
| LED HP bars and animations | Not started |
| Buzzer audio cues | Not started |
| Preset team rosters + mystery draft | Not started |
| Battery + power management | Not started |
| Physical board / enclosure | Not started |

The game is fully playable today over a USB cable: flash the firmware, open a serial terminal, and play a complete battle by typing move choices. Everything physical is still ahead.

---

## Out of Scope (for now)

Earlier design iterations explored larger 6v6 teams, NFC card scanning for team selection, physical Pokémon standees with embedded chips, and per-Pokémon move cards. Those are interesting and may resurface in a v2 home edition, but they're poor fits for a convention demo. Quick games, no loose pieces, zero learning curve — that's the v1 brief.

Also out of scope: AI opponent (the demo is two-player only), full 151-Pokémon roster, sound chip / proper audio, wireless multiplayer.

---

## More Detail

- **Electronics design** — [ELECTRONICS.md](./ELECTRONICS.md)
- **Software internals** — [TECHNICAL.md](./TECHNICAL.md)
- **Full spec** — [specs.md](./specs.md)
- **Architecture deep-dive** — [architecture/](./architecture/README.md)

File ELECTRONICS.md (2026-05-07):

# Mega Blastoise — Electronics Design

For project overview and gameplay, see [DESIGN.md](./DESIGN.md).

Working document for physical board wiring, power, GPIO assignment, and physical layout. Scope is a convention-portable demo: 3v3 battles, preset teams, no removable physical pieces.

---

## Component List

| Part | Qty | Purpose | Interface |
|---|-----|---|---|
| Raspberry Pi Pico (RP2040) | 1 | Main MCU | — |
| WS2812B NeoPixel strip | 24 LEDs | HP bars, party status, status effect, animations | PIO (one wire) |
| 128×64 monochrome OLED (SSD1306) | 2 | Per-player display: sprites, moves, tooltips | I²C |
| 12 mm tactile button | 14 | 4 move + 3 party per player | Button matrix |
| Piezo buzzer | 1 | Audio cues | PWM |
| LiPo battery (2000 mAh) | 1 | Power | — |
| TP4056 charging module | 1 | USB-C charging | — |
| MT3608 boost converter | 1 | LiPo → 5 V | — |
| Slide switch (SPDT) | 1 | Power on/off | — |

Approximate parts cost: **~$40** (excluding enclosure and connectors).

---

## GPIO Map

The RP2040 Pico has 27 usable GPIOs. With NFC and 7-segment displays cut, the new map is comfortable — 7 spare pins after everything is wired.

```
GP0   spare
GP1   spare
GP2   spare
GP3   spare
GP4   spare
GP5   spare
GP6   Button matrix ROW 0  (P1 moves)
GP7   Button matrix ROW 1  (P1 party)
GP8   Button matrix ROW 2  (P2 moves)
GP9   Button matrix ROW 3  (P2 party)
GP10  Button matrix COL 0
GP11  Button matrix COL 1
GP12  Button matrix COL 2
GP13  Button matrix COL 3
GP14  spare
GP15  spare
GP16  I2C0 SDA  →  P1 OLED (SSD1306, addr 0x3C)
GP17  I2C0 SCL  →  P1 OLED
GP18  I2C1 SDA  →  P2 OLED (SSD1306, addr 0x3C)
GP19  I2C1 SCL  →  P2 OLED
GP20  NeoPixels (PIO one-wire)
GP21  Buzzer (PWM)
GP22  spare
GP23  (SMPS mode — avoid)
GP24  (VBUS sense — avoid)
GP25  (onboard LED — usable for boot diagnostics)
GP26  spare / ADC0
GP27  spare / ADC1
GP28  spare / ADC2
GP29  spare / ADC3 / VSYS sense
```

The two OLEDs are on separate I²C buses (each at default address 0x3C) to avoid having to swap one to 0x3D and to let either display update without blocking the other.

---

## Button Matrix

4 rows × 4 columns = 16 positions; 14 used.

| Row | Player | Function | Active cols |
|-----|---|---|---|
| 0 | P1 | Move buttons 1–4 | cols 0–3 |
| 1 | P1 | Party slots 1–3 | cols 0–2 |
| 2 | P2 | Move buttons 1–4 | cols 0–3 |
| 3 | P2 | Party slots 1–3 | cols 0–2 |

Cols 3 in party rows (1 and 3) are unused matrix positions.

### Wiring

- **Row pins (GP6–9):** outputs, one LOW at a time during scan; others HIGH or high-Z.
- **Col pins (GP10–13):** inputs with internal pull-ups.
- Detection: drive row LOW → read columns → LOW column = button pressed at that (row, col).
- Scan all 4 rows in sequence at ~1 ms — fast enough that no press is missed.
- **Hold-to-inspect:** firmware distinguishes short press (~50 ms) from hold (~200 ms+) on move buttons during the move-pick state.

### Physical placement

Each player has a pair of button rows on their side of the board:

```
[ P1 party: 3 buttons ]
[ P1 moves: 4 buttons ]
       [board center]
[ P2 moves: 4 buttons ]
[ P2 party: 3 buttons ]
```

Button labels are silkscreened on the board face — "1 / 2 / 3 / 4" for moves, "1 / 2 / 3" for party slots.

---

## LED Strip

24 WS2812B LEDs total, single chain driven by GP20 via PIO. Daisy-chained continuously across the board — physical layout can split into two visual segments while remaining one logical strip.

```
[ P1: LEDs 0–11 ]    ←——————→    [ P2: LEDs 12–23 ]
```

### Per-player assignment (12 LEDs each)

| LEDs | Count | Function |
|---|---|---|
| 0–7 | 8 | HP bar — active Pokémon's health |
| 8–10 | 3 | Party status — one LED per team slot |
| 11 | 1 | Status effect indicator |

**HP bar:** 8 LEDs = 12.5% per LED. Color shifts green → yellow → red as HP drops. Drains LED-by-LED on damage with a buzzer hit.

**Party slots (3 each):** dim green = alive on bench; bright white = currently active; off = fainted. Pulses white during forced-switch prompts.

**Status effect:** yellow = paralyzed, orange-red = burned, cyan = frozen, purple = poisoned, slow green pulse = asleep. Off = no status. When a status lands, the HP bar briefly tints the same color as the status LED to teach players what the status does.

---

## OLED Displays (per player)

Two 128×64 monochrome SSD1306 OLEDs, one per player station. I²C interface, 4 wires each (VCC, GND, SDA, SCL). Drive at 400 kHz fast mode — fast enough for sprite swaps and tooltip updates.

### What each OLED shows

| State | Display content |
|---|---|
| Attract | Alternates "PLAY" / "ME", chased by the buzzer chime |
| Mystery draft | Each Pokémon revealed one at a time: large sprite + name |
| Battle ready | Active Pokémon portrait centered |
| Move pick | Active Pokémon sprite (small) + numbered move list (4 lines) |
| Hold-to-inspect | Tooltip: move name, type, power, accuracy, secondary effect |
| Status applied | Sprite + small "PAR" / "BRN" / "PSN" / etc. tag in corner |
| Faint | Grayed sprite + "FAINTED" |
| Pick replacement | Two small sprites + HP for remaining Pokémon |
| Tactical timeout (opponent) | Your remaining team's sprites + HP |
| Win / lose | Stat recap (damage, crits, turns) → "WINNER!" / "GG!" |

Sprite assets are pre-rendered 1-bit bitmaps baked into flash. Roster of ~20 Pokémon × 1 sprite each = ~20 KB of sprite data, well within the 2 MB flash budget.

### Why per-player, not center-shared

A single shared display means one player reads it upside-down and team-private info (your moves, your tooltips) is exposed to your opponent. Two cheap OLEDs solve both problems and add convention drama: each player has their own little screen telling them what to do.

---

## Buzzer

Single piezo buzzer driven by PWM on GP21. Polyphonic-feeling melodies achieved via fast frequency switching (no DAC needed). Used for:

- Attract-mode chime (every 30 s when idle)
- Pokémon-reveal beep during draft
- Ready-up chord at battle start
- Move hit sounds
- Super-effective "ding-ding" double-beep
- Critical hit sting
- Status-applied zap
- Faint descending three-note tone
- Win victory jingle (4 notes)

Mounted on the underside or behind a small grille. Volume: tactile-button-loud — clear in a quiet room, audible but not piercing in a convention hall.

---

## Power

### Battery design (untethered)

LiPo + boost converter so the board runs without a tether for a full convention day:

```
LiPo 2000 mAh
  ├─ TP4056 charge controller   (USB-C input on board edge for charging)
  └─ MT3608 boost → 5 V         (regulated up from LiPo voltage)
       └─ slide switch (on/off)
            ├─ Pico VSYS
            └─ NeoPixel VCC

Pico 3V3 out → OLED VCC (×2), button pull-ups (internal)

GND: all components share one common ground rail
```

The boost is non-negotiable — WS2812B minimum VDD is 3.5 V, and a discharging LiPo drops to 3.0 V at empty. Without the boost, the LEDs misbehave well before the battery is actually flat.

### Current budget (approximate)

| Consumer | Peak current |
|---|---|
| Pico (RP2040 + 3V3 reg) | ~100 mA |
| NeoPixels (24 × ~20 mA moderate brightness) | ~480 mA |
| OLEDs (×2) | ~40 mA |
| Buzzer (PWM, brief) | ~30 mA |
| **Total peak** | **~650 mA @ 5 V** |

At average gameplay brightness, draw is closer to ~300 mA. From a 2000 mAh LiPo at ~85% boost efficiency: **~5 hours of active gameplay**, more in attract mode.

### Charging

USB-C port on the board edge wired to the TP4056. Plug in overnight, ready for the next day. The slide switch isolates the load while charging — boost circuits draw quiescent current even when the Pico is "off."

---

## Physical Layout & Dimensions

Portrait orientation, players on opposite short edges facing each other.

```
┌─────────────────────────────────────────┐  ← top edge
│  [ P2 OLED (128×64) ]                   │
│  [ P2 party: 3 buttons ]                │
│  [ P2 moves:  4 buttons ]               │
│                                          │
│  ┌──── P2 LEDs: 8 HP + 3 party + status ─┐│
│  │ █ █ █ █ █ █ █ █  ●  ●  ●   ● status  ││
│  └────────────────────────────────────────┘│
│                                            │
│  ┌──── P1 LEDs: 8 HP + 3 party + status ─┐│
│  │ █ █ █ █ █ █ █ █  ●  ●  ●   ● status  ││
│  └────────────────────────────────────────┘│
│                                            │
│  [ P1 moves:  4 buttons ]                  │
│  [ P1 party: 3 buttons ]                   │
│  [ P1 OLED (128×64) ]                      │
└────────────────────────────────────────────┘  ← bottom edge

(Buzzer mounted under the board, grille on one side. Pico + battery + power circuit
 mounted on underside in a recessed cavity.)
```

### Dimensions

LED strip density: **144 LEDs/m** keeps each player's 12-LED segment to ~85 mm — a compact strip that fits comfortably across the board.

| Dimension | Calculation | Value |
|---|---|---|
| Width | LED strip (~85 mm) + side margins | **~150 mm** |
| Height (top to bottom) | OLED (15 mm) + buttons (~40 mm) + LED row (12 mm) + center gap (10 mm) + LED row (12 mm) + buttons (~40 mm) + OLED (15 mm) + margins (20 mm) | **~165 mm** |

**Final board size: roughly 150 mm × 165 mm.** Smaller than a paperback book — easily portable, fits in a tote bag with room to spare. Light enough to hand-carry around the convention.

Pico, battery, charge module, boost, and switch all mount on the underside in a 5–8 mm recess. Total board thickness: ~12 mm including buttons protruding from the top face.

---

## Open Questions

1. **OLED orientation** — landscape (128 wide, 64 tall) or portrait? Landscape gives more room for the move list (4 lines fit naturally). Confirm sprite proportions.
2. **Enclosure** — single piece of laser-cut acrylic (cheapest, fastest), 3D-printed shell (more rugged), or hand-finished wood (prettiest)? Needs to survive a day of convention handling.
3. **Charging UX** — solid LED while charging, blinking when full? Use the Pico's onboard LED (GP25) for this.
4. **Attract-mode buzzer** — how often is too often? 30 s feels right but might annoy your booth neighbors. Add a volume potentiometer? Or rely on the slide switch.
5. **NeoPixel data resistor** — 330 Ω series resistor on GP20 line, recommended.
6. **Decoupling caps** — 470 µF across NeoPixel 5 V at strip entry, 100 nF on each OLED VCC. Worth designing in from the start.

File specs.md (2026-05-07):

# Mega Blastoise — Project Specification

## Purpose

Mega Blastoise is a self-contained two-player physical board game that runs Pokémon Generation 1 combat. Two players face off across a physical board equipped with NeoPixel LED strips, an e-ink display, and button clusters. No phone, PC, or network is required — the game runs entirely on a Raspberry Pi Pico (RP2040).

The battle rules are fully handled by the `battler` open-source battle engine. The firmware and host test crate wrap that engine with a hardware presentation layer (LEDs, display, input) and a structured event pipeline.

---

## Repository Layout

```
mega_blastoise/
  battler/                  # upstream battler engine (git checkout)
  mega_blastoise/           # Rust workspace
    mega_blastoise_core/    # no_std shared library: engine integration, event bus
    mega_blastoise_fw/      # RP2040 firmware binary
    mega_blastoise_test/    # PC host binary + integration tests
    patches/                # patched once_cell for no_std compatibility
```

---

## Hardware

| Component | Part | Interface | Notes |
|---|---|---|---|
| MCU | Raspberry Pi Pico (RP2040) | — | 264 KB SRAM, 2 MB flash |
| LEDs | WS2812B NeoPixel strip (~30 LEDs) | PIO (GPIO) | Driven by RP2040 PIO state machine |
| Display | Waveshare 2.9" e-ink | SPI | Not yet integrated |
| Move buttons | 4× tactile per player | GPIO (GP6–9, P2 TBD) | Pull-up, active-low, debounced in firmware |
| Switch buttons | 6× tactile per player | GPIO (GP10–15, P2 TBD) | Party slot 1–6 |
| NFC readers | 2× PN532 | I²C | I2C0: GP16/17, I2C1: GP18/19, addr 0x24 |
| Debug probe | Picoprobe / CMSIS-DAP | SWD | probe-rs flashing and RTT logging |
| USB serial | Built-in RP2040 USB | USB CDC-ACM | Development CLI; picocom at /dev/ttyACM1 |

### Power Notes

PN532 modules draw significant current when the RF field is active. Power them from an external 3.3 V or 5 V supply, **not** from the Pico's 3V3 pin. Share a common GND with the Pico. I²C signal levels are 3.3 V on both the RP2040 and most PN532 breakouts — no level shifting needed.

---

## Software Architecture

### Crate Dependency Graph

```
battler  (upstream engine, no_std core)
    ↑
mega_blastoise_core   (no_std, shared by fw and test)
    ↑                ↑
mega_blastoise_fw   mega_blastoise_test
(RP2040 binary)     (PC binary + tests)
```

### `mega_blastoise_core`

Platform-independent library compiled for both `thumbv6m-none-eabi` and the host. Contains:

- **`battle_runner`** — `run_battle()` entry point; drives the `battler` engine to completion
- **`battle_input`** — `InputBus`, `InputSource` trait, choice string helpers
- **`battle_effects`** — `BoardEffects` trait, `BoardEventQueue`, log parsing
- **`board_event`** — typed `BoardEvent` enum, `ParsedBattleLogLine`, `parse_log_line()`
- **`data_store`** — `FlashDataStore` implementing `battler_data::DataStore` from baked-in const tables
- **`demo_teams`** — hardcoded demo rosters for p1 (Red) and p2 (Blue)

### `mega_blastoise_fw`

`no_std` Embassy async binary for RP2040. Modules:

- **`main`** — embassy entry point; instantiates all subsystems and calls `run_battle()`
- **`subsystems/usb`** — USB CDC-ACM init; spawns `usb_device_task`; returns `UsbBattleInput`
- **`subsystems/nfc`** — I²C + PN532 init; spawns `pn532_task_i2c0/1`
- **`usb_input`** — `UsbBattleInput`: USB CDC battle CLI with local echo, backspace, move/switch prompts
- **`pico_battle_input`** — `PicoBattleInput`: physical GPIO button matrix (stub, not yet active)
- **`board_effects`** — `BattleEffects`: forwards `BoardEvent` to RTT log and optionally to `InputBus.log`
- **`pn532`** — PN532 I²C driver (`GetFirmwareVersion` ping loop; NFC card read not yet implemented)
- **`usb_cdc_line`** — CDC line helpers: `write_crlf`, `log_usb_rx_line_str_to_rtt`
- **`mem_profile`** — heap snapshot utility (gated on `mem-profile` feature)

Cargo features:

| Feature | Default | Effect |
|---|---|---|
| `usb` | ✓ | Compile USB subsystem and `UsbBattleInput` |
| `nfc` | ✓ | Compile NFC subsystem and PN532 tasks |
| `mem-profile` | ✓ | Emit `heap_snapshot()` calls at boot and after major allocs |

### `mega_blastoise_test`

Standard Rust binary for PC development and CI. Modules:

- **`harness`** — `run_interactive()`: sets up a battle and runs it over stdin
- **`stdin_input`** — `StdinBattleInput`: synchronous stdin move/switch prompts
- **`board_game_effects`** — `BoardGameEffects`: `println!`-based `BoardEffects` sink for host
- **`main`** — calls `run_interactive()`
- **`tests/`** — integration tests: board event parsing, scripted effect pipeline, demo battle smoke test

---

## Core Interfaces

### `InputBus`

Defined in `mega_blastoise_core::battle_input`. The single shared-memory bus between the battle runner and all input sources.

```
InputBus {
    choices: Channel<NoopRawMutex, String, 4>,   // input → runner
    prompt:  Signal<NoopRawMutex, ActivePrompt>,  // runner → input sources
    log:     Channel<NoopRawMutex, String, 8>,    // effects → USB output sink
}
```

- `prompt` is a `Signal` (last-write-wins): the runner writes the current `ActivePrompt` before blocking on `choices`.
- `choices` is an async MPSC channel: input sources send a choice string (e.g. `"move 0"`, `"switch 2"`); the runner receives one per request.
- `log` carries human-readable battle event descriptions from `BattleEffects` to `UsbBattleInput` for display over the CDC serial line.

### `ActivePrompt`

```rust
pub struct ActivePrompt {
    pub player_id: String,   // "p1" or "p2"
    pub request: Request,    // battler::Request (Turn | Switch | TeamPreview | LearnMove)
}
```

Broadcast by the runner before blocking. Input sources read this to know what to display and what format of choice to submit.

### `InputSource` trait

```rust
pub trait InputSource {
    async fn run(&mut self, bus: &InputBus);
}
```

Implemented by `UsbBattleInput`, `PicoBattleInput`, `StdinBattleInput`, and the no-op `NoInput`. `run_battle()` joins the battle loop with `input.run(bus)` so both progress cooperatively via embassy's cooperative scheduler.

### `BoardEffects` trait

```rust
pub trait BoardEffects {
    fn on_event(&mut self, event: BoardEvent);
}
```

Implemented by `BattleEffects` (firmware) and `BoardGameEffects` (host test). Called synchronously by `BoardEventQueue::dispatch_all()` inside `battle_loop` for each typed event.

### `BoardEvent` enum

Typed events produced by parsing engine log lines and injected prompts. Variants:

| Variant | Trigger | Intended hardware action |
|---|---|---|
| `BattleStart` | Engine `battlestart` log | LED startup animation, full HP display |
| `Turn { n }` | Engine `turn` log | Turn marker blink |
| `Move { name }` | Engine `move`/`animatemove` log | Move flash on attacker's LED strip |
| `Damage { mon, health }` | Engine `damage` log | Hit sound, HP bar update |
| `Heal { mon, health }` | Engine `heal` log | Heal sound, HP bar update |
| `Faint { mon }` | Engine `faint` log | KO animation, extinguish that Pokémon's LEDs |
| `SwitchIn { name, species, player_id }` | Engine `switch`/`drag`/`appear` | Switch animation, light new slot |
| `SwitchOut` | Engine `switchout` | Dim outgoing Pokémon's lights |
| `Split { side }` | Engine `split` | Internal log routing marker (not a gameplay cue) |
| `Win { side }` | Engine `win` | Win animation on winning side |
| `Tie` | Engine `tie` | Neutral end animation |
| `Prompt { player_id, kind }` | Before blocking on input | Light that player's input controls |

### `BoardEventQueue`

FIFO queue for `BoardEvent` values. Handles the battler `split` → private row → public row pattern by skipping the private row after each `split`. Filled by `push_log_lines()` and drained to a `BoardEffects` sink by `dispatch_all()`.

### Choice String Protocol

All choice strings are plain ASCII passed through `InputBus.choices`:

| Situation | String format | Example |
|---|---|---|
| Use move in slot N (0-based) | `move N` | `move 0` |
| Switch to party index N (0-based) | `switch N` | `switch 2` |
| Multiple slots (doubles / multi-switch) | Joined with `;` | `move 0;move 2` |
| Pass (no moves available) | `pass` | `pass` |
| Team preview (random) | `random` | `random` |

Helpers in `mega_blastoise_core::battle_input`: `format_move_choice(slot)`, `format_switch_choice(team_index)`, `join_choice_parts(&[String])`.

### `FlashDataStore`

Implements `battler_data::DataStore` using const tables baked into flash at build time by `build.rs`. The build script reads JSON data files from the `battler` data directory and emits Rust `static` arrays of `(&str, &str)` pairs (id → JSON). Lookup is linear scan; the `battler` Dex layer caches results after first access.

---

## Data Flow

### Battle Turn (firmware)

```
UsbBattleInput::run()
  ├─ select(bus.prompt.wait(), bus.log.receive())
  │   ├─ log line arrives → writeln over USB CDC
  │   └─ prompt arrives → handle()
  │         ├─ display battle state (allies, bench, moves) over USB CDC
  │         ├─ read_line() [local echo, backspace, CRLF]
  │         └─ validate input → format_move_choice() / format_switch_choice()
  └─ bus.choices.send(choice_string)

battle_loop()  [runs concurrently via embassy join]
  ├─ battle.active_requests().next()
  ├─ queue.push_event(board_prompt_event()) → dispatch_all(effects)
  ├─ bus.prompt.signal(ActivePrompt { player_id, request })
  ├─ bus.choices.receive().await   ← blocks here until input sends
  └─ battle.set_player_choice(player_id, choice_string)
       └─ process_new_log_lines() → BoardEventQueue → BattleEffects
             ├─ defmt::info! (RTT)
             └─ bus.log.try_send(description)  ← picked up by UsbBattleInput
```

### Engine Log Processing

```
battle.new_log_entries()  →  process_new_log_lines()
  └─ BoardEventQueue::push_log_lines()
       ├─ ParsedBattleLogLine::parse(line)  [title|key:value|…]
       ├─ split handling: skip private row after split
       └─ parse_log_line() → Some(BoardEvent) or None
  └─ dispatch_all(sink)
       └─ BoardEffects::on_event(event)
```

---

## Concurrency Model

The firmware runs under `embassy-executor` with a single-threaded cooperative async model.

- **`battle_loop`** and **`input.run(bus)`** execute as joined futures — neither is a separate embassy task; they interleave on the single executor thread via `await` yield points.
- **`usb_device_task`** is a true embassy task, spawned separately, and handles USB protocol frames independently.
- **`pn532_task_i2c0/1`** are embassy tasks, one per I²C bus, polling NFC readers in the background.
- All shared state crosses future boundaries only through embassy-sync primitives (`Channel`, `Signal`) with `NoopRawMutex` (safe for single-core).

---

## Build System

### Toolchain

- Rust nightly (`rust-toolchain.toml` in workspace)
- Target `thumbv6m-none-eabi` for firmware
- `probe-rs` for flashing and RTT attach

### Build Commands

```bash
# PC test binary
cargo build -p mega-blastoise-test
cargo run -p mega-blastoise-test
cargo test -p mega-blastoise-test

# Firmware
cargo build -p mega-blastoise-fw --target thumbv6m-none-eabi --release
cd mega_blastoise_fw && cargo run --release   # flash via probe-rs

# Firmware without USB or NFC
cargo build -p mega-blastoise-fw --target thumbv6m-none-eabi \
  --no-default-features
```

### `build.rs` (core)

At compile time, `mega_blastoise_core/build.rs` reads the battler data directory and emits `battle_data.rs` into `$OUT_DIR`, included by `data_store.rs`. This bakes Pokémon species, moves, abilities, conditions, type chart, and aliases into flash as static string pairs.

---

## Game Scope (v1)

### In Scope

- ~20 Gen 1 Pokémon with type-coverage representation
- Standard singles 1v1: select move → resolve turn → repeat
- Status effects: burn, freeze, sleep, paralysis, poison
- Type effectiveness, STAB, critical hits, RNG damage roll
- Two-player local play (both players share one board)
- NeoPixel feedback: HP bars, attack flash, faint animation
- E-ink display: turn state, HP, active Pokémon, move list

### Explicitly Out of Scope (v1)

- AI opponent
- Full 151-Pokémon roster
- Sound hardware
- Wireless multiplayer
- Items (Gen 1 has none in battle)
- Pokémon abilities (Gen 1 has none)

---

## PlayerStation Architecture

Two symmetric `PlayerStation` structs, one per player. Each owns all player-side hardware:

```rust
pub struct PlayerStation<'d> {
    player_id: PlayerId,        // P1 | P2
    nfc: NfcReader<'d>,
    screen: EinkDisplay<'d>,
    buttons: PicoBattleInput<'d>,
    leds: LedStrip<'d>,
}
```

`BattleController` owns both stations and routes prompts/choices between them and the engine.

### Presentation Pipeline

Battle engine events are dispatched asynchronously; the main loop paces them via a per-event `delay` field:

1. Main loop receives event from engine
2. Sends event into each `PlayerStation`'s channel (non-blocking)
3. Sleeps `event.delay` before pulling the next event
4. Each station has one long-running async task draining its channel

```rust
pub struct BoardEvent {
    pub kind: BoardEventKind,
    pub delay: Duration,   // floor: main loop waits this long before next event
}
```

Properties:
- **P1 and P2 animate in parallel** — independent tasks, no cross-player coordination
- **Per-player hardware is serialized** — single consumer task per station prevents display/LED conflicts
- **Overlap is a per-event knob** — `delay=0` max overlap, `delay≥animation_duration` sequential
- **Channel backpressure** (capacity ~4–8) — if presentation falls behind, non-blocking sends drop low-priority events or the main loop stalls naturally
- Events affecting both players (turn start, weather) are sent to both channels and animate in parallel

---

## Open Work

| Area | Status |
|---|---|
| USB battle CLI (picocom) | Working |
| Physical button input (`PicoBattleInput`) | Stub — awaiting wiring |
| NFC card read (PN532) | Bring-up only (firmware version ping loop) |
| NeoPixel HP bars | Not started |
| E-ink display | Not started |
| Pokémon switching mid-battle | Deferred to v2 |
| Per-Pokémon move limits / PP enforcement | Engine handles PP; UI validation in USB input |

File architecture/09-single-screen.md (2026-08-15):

# Single-Screen Redesign

Target design for the next generation of the device: one shared color screen
split between two seats, cursor-driven controls, and open information.

This page is the reference every migration session reads first. It records
decisions, not aspirations — where a number appears here it was measured, and
where something is undecided it says so.

Visual spec: [`mega_blastoise_web/www/ui_flow.html`](../mega_blastoise_web/www/ui_flow.html)
(published at `/mega_blastoise/ui_flow.html`). Click any mockup to toggle a
true 240x320 pixel preview.

---

## 1. What changes and what does not

**Changes:** the display stack (one color panel instead of two mono OLEDs), the
input model (cursor and confirm instead of corner-button-equals-corner-move),
the information model (open, with a permanent foe HUD), and the physical
control layout (D-pad plus three buttons per seat).

**Does not change:** the battle engine integration, `BoardEvent` /
`BoardEffects`, `battle_runner`, `data_store`, `randbat`, and the choice-string
protocol. The engine sees the same interface it sees today.

**The rule that governs all of it** stays exactly as it is: all display logic
lives in core (`oled_ctl` + the renderer), all input semantics live in core
(`choice_collect`), and platforms do raw IO only. The web build and the
firmware must render identically from the same state. This is the property that
makes the migration tractable at all, so it takes priority over convenience in
every case.

---

## 2. Hardware target

| Item | Decision | Notes |
|---|---|---|
| Panel | 2.8" **IPS** ST7789, 240x320, SPI | IPS is mandatory: a TN panel shows inverted contrast to whichever seat views it from the far side |
| MCU | RP2350 (Pico 2) | Keeps embassy-rp, probe-rs, and defmt. See §7 for why not ESP32-S3 |
| Framebuffer | full RGB565, 240x320 = 153.6 KB | RP2350 has 520 KB. Trim the heap from its current 64 KB (measured peak is ~3 KB) |
| Sprites | 4-bit indexed + per-species 16-color palette, deflate | ~485 KB for all 386 species, front and back. See §5 |
| Buttons | 4x4 matrix, **one diode per switch** | 14 switches: D-pad (4) + A + B + ? per seat. Diodes give full NKRO and permanently kill the ghosting bug |
| D-pad | rocker part, not four discrete tacts | One hole, correct feel |
| LEDs | 1-2 status LEDs per seat | The 8-LED HP strips are dropped; HP lives on screen |
| Buzzer | **add to the board** | The current PCB has no buzzer footprint at all, so today's audio code plays to nothing |
| Power | spin both a AA and a LiPo variant | |

A 16 MB board (Pico Plus 2 W) is only worth it for WiFi — OTA sprite packs, or
the device serving its own web build. It is not needed for space.

---

## 3. Screen model

The panel lies flat between the seats and there is exactly one orientation:
**split portrait**, from attract mode through the recap. Two 240x160 halves,
and the far half is rendered rotated 180 degrees so both players read upright.

The players sit across from each other and the console is never picked up or
turned, so no screen may assume one reader. The Gen picker draws the same
content into both halves, each upright to the seat reading it, and either
player can drive it. The options are per seat instead: `?` opens them on the
half of the player who pressed it, over settings both players share.

The battle itself is one view, not two. The two mons stand **side by side at
the same height**, in a band across the middle of the panel: one seat's mon to
the left, the other's to the right, each upright to its owner and mirrored so
the pair faces each other. That band is drawn by the compositor
(`device_view::draw_scene_mons`), not by either half, because a half can only
touch its own 160 rows — anything drawn per half is pushed to one side of the
seam and the pair comes out staggered. The halves own the chrome around it:
each seat's HP plate sits directly under its own mon, and the narration is
drawn in both so it lands at the bottom of the screen from either seat.

Nothing at all is drawn across the middle during that shared scene: any line
there cuts the one field back into two boxes. The divider returns the moment
either half shows a private view again (move choice, party list, battle log,
one seat's options), which is what tells the players the halves are no longer
the same picture.

Every private half is framed in **its own seat's colour** — White's half is
edged white, Red's red — with a black hairline inside it and the beige field
within. The two frames meet at the seam, so the divider only has to add the
band and the button and the whole device reads as one pokeball: red half,
white half, black equator. It doubles as seat identity, which is what the old
colour stripe down the edge used to do. The frame reaches 8 px in from each
edge and the button 11 px into each half, so no private screen draws above
`display_color::TOP`.

The move-choice half copies the Gen 3 battle screen directly: the rival's
status plate at the top left with their mon opposite it on the far platform,
your own mon from behind on the near platform with your plate — the one
carrying the HP numbers, as in the games — at the bottom right, and the bottom
third given to a 2x2 move menu with the cursor triangle beside the highlighted
row and a second box holding that move's PP and type. Both menus are the same
teal as the narration box behind a blue double border with gold corner pins;
the narration box keeps the red border. There is no button legend on this
screen, for the same reason the games have none.

There is no orientation setting and no runtime flip: nothing about the console
turns, so there is nothing to switch. The web build keeps one cosmetic "rotate
view" button, which walks the viewer around the table without changing a pixel
the device draws.

### Screens

Shared, drawn identically into both halves: attract demo, Gen picker
(Gen 1 / Gen 3).

Private, per half: lobby ready-up, options menu, team reveal, move choice,
party list, locked-in, turn playback, forced switch with rival scouting,
battle log, recap.

The `Screen` enum in `oled_ctl.rs` is the seam for all of this and survives the
migration. Variants tied to concealed mode (`ActionSelect`, `ConcealedMoves`,
`SwitchList`, `OpponentMon`, `ControlsSelect`) are deleted; new variants are
added for the options menu, the Gen picker, and the battle log.

---

## 4. Input model

Seven inputs per seat, placed with **rotational** symmetry so both seats get an
identical hand position — not mirrored, which is what the current PCB does.

- **D-pad** moves the cursor. Auto-repeat on hold.
- **A** confirms.
- **B** backs out. Every state has an explicit back path.
- **?** explains whatever the cursor is on: full description and secondary
  effects for a move, full stats for a party member, known information for the
  foe on the HUD.

This replaces the current position-encoded scheme, where a physical corner
button meant the move drawn at that corner, and where a stray tap committed a
choice with no way back.

`?` does not interrupt turn playback. Instead, pressing `?` on a UI element
opens the **battle log**: the whole battle, D-pad scrollable, capped at roughly
the last 50 lines, showing damage numbers and crit and effectiveness reasoning
rather than only the narration text. The log pauses only the reader — the other
player keeps playing, so nobody can stall the game by reading.

Debounce is required and does not currently exist anywhere in the firmware.

---

## 5. Sprite pipeline

Measured, not estimated. Sample: 31 real `pret/pokeemerald` 64x64 sprite
sources, plus 12 PokeAPI Emerald sprites for the color survey.

Gen 3 sprites are at most 64x64 and use at most 16 colors (median 15), so
4-bit indexed with a per-species palette is **lossless**.

Per 64x64 frame:

| Scheme | Size | vs raw |
|---|---|---|
| raw 4bpp | 2048 B | 100% |
| GBA LZ77 — what the Emerald ROM actually stores | 1019 B | 50% |
| deflate, GBA 8x8 tile order | 702 B | 34% |
| **deflate, linear scanline order** | **627 B** | **31%** |

Projected to 386 species, front and back plus palette: ROM parity would be
~780 KB; our scheme lands at **~485 KB**, about 38% under what the real
cartridge spends on the identical pixels.

Two findings that drive the implementation:

1. **Store linear scanline order, not GBA tile order.** Tiling costs 12%
   because it interleaves pixels eight rows apart and destroys horizontal runs.
   The GBA tiled only because its PPU required it; we blit in software.
2. **Use a 512-byte window (deflate `windowBits = 9`).** Measured *smaller*
   than a 32 KB window on this data, because sprites are under 4 KB so a large
   window finds no additional matches while costing more bits to encode. So the
   decompressor needs 512 bytes of RAM, not 32 KB.

Deflate beats the GBA's LZ77 because LZ77 has no entropy coding, and 16-color
sprite data has extremely skewed symbol frequencies, so Huffman pays heavily.
The GBA chose LZ77 because it was free in BIOS, decompressed in place with zero
auxiliary RAM, was roughly ten times faster to decode on a 16.78 MHz ARM7TDMI,
and because saving 295 KB on a 16 MB cart they had already bought bought them
nothing. Every one of those constraints is inverted for us.

**Art direction:** Gen 3 style everywhere, for every species, pegged to the
sprite sets Showdown maintains. A Gen 1 battle uses the same art as a Gen 3
battle. Gen 1's 146-species randbat pool is a subset of the 386, so this is one
sprite set, not two.

Animation is deferred but partly free: Emerald ships multi-frame front sprites
for some species already (2 of 33 sampled were 64x256, i.e. four frames).
Showdown's animation sets are the eventual target.

---

## 6. Game rules and flow

- **Open information.** Concealed mode is deleted. The move a player has locked
  in stays hidden until playback, but nothing else does.
- **Gen picker before the lobby.** Gen 1 or Gen 3, its own screen — it is the
  biggest choice and deserves the framing.
- **Gen 3 is stubbed initially**: the menu entry and all UI plumbing exist, but
  it routes to Gen 1 combat. It must be labeled "preview" until the engine
  lands, and the Gen 3 info fields (abilities, held items, natures, the
  Sp.Atk / Sp.Def split) must sit behind the same ruleset flag as the engine so
  the UI never advertises data the engine cannot fill.
- **Options menu**, lobby only, and per seat: `?` opens it on the half of the
  player who pressed it and leaves the other player in the lobby. Both may have
  it open at once. The settings themselves — team size (3v3 / 6v6), text speed,
  sound, tutorial, turn timer — are shared, so a change by either player
  applies to the match and shows on the other's screen if they are looking.
  The Gen picker is the exception: it chooses the game both players are about
  to be in, so it owns the whole panel and is drawn into both halves.
- **Teams are a fresh random draft** every battle, including rematches.
- **Turn timer**, optional, default 60 s, with a visible countdown over the
  final 10 s. Today a stalled player can freeze the game permanently.
- **Hold to fight the AI** in the lobby stays — it is how a lone visitor tries
  the device.
- **Attract demo** stays; it is the only thing aimed at bystanders, and like
  everything else it plays head-to-head across the two halves.
- Animation scope: sprite bob, HP bar drain, damage flash, faint fade. Per-move
  attack animations are out of scope for now.

---

## 7. Engine

The live engine is `gen1_battle/` — 3,615 lines of hand-written `no_std` Rust,
with 238 mon entries and 167 moves. Upstream `battler` is vendored and remains
a dependency, but core has **zero** `battler::` call sites today against 49
`gen1_battle::` ones. It stays for Gen 3 reference.

Gen 3 is not a data swap. It needs the Special stat split into Sp.Atk and
Sp.Def (which touches all of `combat.rs` and `state.rs`), 77 abilities as
behavioral hooks, roughly 60 held items, natures, the Gen 3 IV system, four
weathers, a 17-type chart, and 354 moves instead of 167. Realistically 2-3x the
current engine.

Upstream `battler` already implements this, with executable fxlang effect
scripts — `battle-data/data/abilities/gen3.json` carries all 76 Gen 3 abilities
with real callbacks (Intimidate iterates adjacent foes and applies `atk:-1`;
Levitate overrides `is_grounded`), plus `mons/gen3.json` and `moves/gen3.json`
as delta layers over gen1 and gen2.

**Before writing any Gen 3 engine code**, build core against upstream `battler`
targeting RP2350 and measure flash and RAM. It was presumably dropped because
it would not fit RP2040; on RP2350 with 4 MB that assumption may be stale. If
it fits, gens 1 through 9 come free and a large maintenance burden disappears.
That measurement decides the shape of the whole Gen 3 phase, and it is about a
day of work.

ESP32-S3 was considered and declined: it is Xtensa, so it needs the `espup`
toolchain fork rather than a plain target add, and the entire firmware IO layer
is embassy-rp (I2C, PIO, PWM, USB, Flex GPIO), so the port would be a full
rewrite of that crate plus the loss of a working probe-rs, defmt, and RTT
workflow. RP2350 delivers the RAM and flash without any of that risk.

---

## 8. Migration plan

Each stage lands as its own commit and is verifiable in the web build or the
host CLI **before** any firmware work. Iterating in a browser takes seconds;
iterating on flashed firmware does not.

Before starting: **tag the last commit that carries the mono renderer**, since
this branch deletes it.

Status as of 2026-08-06: stages 1 and 2 are done, stage 3 is done for the
foe HUD, stage 4 is done as an additive `cursor_nav` module (the old
collector is untouched), and stage 6 has a working client at
`mega_blastoise_web/www/device.html`. Stages 7 through 9 are untouched, and
the firmware still runs the mono path.

1. **New renderer beside the old one.** `render_half()` consuming the same
   `Screen` enum, drawing to a 240x160 `Rgb565` target, matching
   `ui_flow.html`. Plus a compose step that writes two halves into one 240x320
   buffer with the far half rotated 180. Old `display.rs` untouched; the two
   paths are selected by a cargo feature so they can be compared side by side
   in a browser.
2. **Sprite pipeline.** `build.rs` currently fetches color PNGs and throws the
   color away at a `luma > 100` threshold. Change the quantizer to emit 4-bit
   indexed plus palette, deflate each with a 512-byte window, and add the
   `no_std` inflate on the read side.
3. **Foe data plumbing.** The HUD needs the opposing active mon's name, level,
   HP percentage, and status inside `ChoiceCollector`. Small, but every choice
   screen depends on it.
4. **Input model.** New event set, cursor state, auto-repeat, and the deletion
   of concealed mode. The riskiest core change: the existing `choice_collect`
   test suite is the safety net, and every test it breaks must be deliberately
   rewritten rather than deleted.
5. **Options menu, Gen picker, battle log, turn timer.**
6. **Web build to full fidelity.** 240x320 canvas, on-screen D-pad and buttons
   per seat rotated to their player, direct tap on UI elements as a shortcut,
   and WebAudio driven by the same note tables the buzzer uses.
7. **Firmware: ST7789 over SPI with DMA**, replacing `subsystems/oled.rs` and
   `sh1106.rs`. One display task now, so the two-panel skew disappears.
8. **Firmware: buttons**, matrix with diodes, real debounce, D-pad repeat.
9. **Delete** the mono renderer, the SH1106 driver, the two-panel path, and the
   LED strip code. Fix the pacing findings from the ergonomics audit at the
   same time: a minimum dwell per narration event, the tutorial shown once per
   power-on rather than every battle, and the rematch dead time.

Gen 3 is a **separate phase after all of this ships**. A working single-screen
Gen 1 device is the milestone that de-risks everything else.

---

## 9. Open questions

- Font: whether to keep embedded-graphics `FONT_6X10` / `FONT_5X8` or bake an
  authentic Game Boy bitmap font. Expected to need iteration either way.
- Whether upstream `battler` fits on RP2350 (§7).
- Doubles are out of scope but are a plausible future direction for Gen 3.

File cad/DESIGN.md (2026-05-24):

# Mega Blastoise — Enclosure CAD Subproject

3D-print-ready case design for the physical Mega Blastoise board.

See also: [DESIGN.md](../DESIGN.md) (gameplay), [ELECTRONICS.md](../ELECTRONICS.md) (wiring/BOM).

---

## Goal of this subproject

Produce a **3D-printable, two-part clamshell enclosure** that houses every
component in the Mega Blastoise electronics design and is **as small as a phone
or smaller**, while staying playable by two strangers sitting across it at a
convention.

Concretely, "done" means:

1. A parametric **OpenSCAD** model in this directory (`board.scad`) that exports
   two STLs — `bottom-tub.stl` and `top-faceplate.stl` — that slice and print
   on a consumer FDM printer (≤180 mm bed) with **no supports**.
2. Every component from [ELECTRONICS.md](../ELECTRONICS.md) has a defined home:
   a pocket, standoff, cutout, or window — with print-tolerance clearances.
3. Footprint ≤ a large phone (target **≤ 70 × 160 mm**), thickness ≤ ~16 mm.
4. Serviceable: opens with screws, components are removable, USB-C charge port
   reachable without opening.
5. The chosen toolchain needs **no CAD skill from the user** — the model is
   text I edit; the user only installs OpenSCAD and presses F6 to export.

Non-goals (v1): final aesthetic fit-and-finish, snap-fit lids, gasketing,
in-mold lettering beyond simple embossed button labels, designing the PCB
itself (this is an enclosure, components are hand-wired / module-based).

---

## Design decisions (confirmed)

| Decision | Choice | Rationale |
|---|---|---|
| Modeling tool | **OpenSCAD** (code-based, parametric) | Lives in the repo, version-controlled, editable by Claude, zero CAD learning curve. |
| Part substitutions | **Allowed**, documented as deviations | Stock Pico + 2000 mAh LiPo are too large for "phone-sized". |
| Construction | **Two-part clamshell** (bottom tub + top faceplate, screwed) | Prints flat, no supports, serviceable, convention-robust. |

---

## Proposed BOM deviations from ELECTRONICS.md

These shrink the board substantially. They are **proposals** — not yet folded
into ELECTRONICS.md. Once confirmed, they should be added there as resolved
open questions.

| ELECTRONICS.md part | Footprint | Proposed substitute | Footprint | Why |
|---|---|---|---|-----|
| Raspberry Pi Pico | 51 × 21 mm | **RP2040-Zero** (Waveshare) | 23.5 × 18 mm | Same RP2040, same GPIO needs, ~28 mm shorter. USB-C onboard for flashing. |
| LiPo 2000 mAh | ~60 × 50 × 7 mm | **~1200 mAh slim cell** (e.g. 553450) | ~50 × 34 × 6 mm | Halves the largest footprint. Trade: ~2.5–3 h gameplay vs ~5 h (still a full demo session, recharge between). |
| WS2812B strip @ 144 LED/m | 12 LEDs ≈ 83 mm | **WS2812B-2020** at ~4 mm pitch | 12 LEDs ≈ 48 mm | The HP-bar width was setting board width. Denser/smaller LEDs shrink it ~35 mm. |
| TP4056 / MT3608 / slide switch | discrete | keep discrete, **bare mini modules** | TP4056 ~26×17, MT3608 ~17×17 | No functional change; just spec the smallest module variants. |

GPIO map in ELECTRONICS.md is unaffected — RP2040-Zero exposes all the GP pins
the firmware uses (button matrix, 2× I²C, PIO LED, PWM buzzer).

---

## What the board looks like

Portrait slab. The two players sit on the **opposite short edges**, board flat
on the table between them. Each player's controls are mirrored 180° so the
layout reads right-side-up from their own seat. A center divider strip splits
the two halves.

```
            ┌─────────────────────────────┐  ← P2's edge (top)
            │   (1) [  P2 OLED  ] (2)      │   move btns at OLED corners
            │   (3) [  0.96"    ] (4)      │
            │      [ S1 ][ S2 ][ S3 ]      │   P2 switch row (under OLED)
            │        ◉  ● ● ●              │   P2: HP LED + 3 party
            │ ─ ─ ─ ─  ▓ buzzer ▓ ─ ─ ─    │   centre divider + shared grille
            │        ◉  ● ● ●              │   P1: HP LED + 3 party
            │      [ S1 ][ S2 ][ S3 ]      │   P1 switch row
            │   (1) [  P1 OLED  ] (2)      │
            │   (3) [  0.96"    ] (4)      │   move btns at OLED corners
            └─────────────────────────────┘  ← P1's edge (bottom)
                  ↑ USB-C charge port on one long side edge,
                    slide power switch adjacent (web-mirrored layout)
```

### Top faceplate (the face players see and touch)

- **2× OLED windows** — rectangular cut-throughs sized to the SSD1306 glass
  active area, with a recessed ledge inside so each module sits flush from
  behind and the bezel hides the PCB edge.
- **14 button holes** — round clearance holes for 12 mm tactile-button
  actuators (or printed keycaps on 6 mm switches — chosen via parameter).
  Embossed labels beside each: `1 2 3 4` for moves, `1 2 3` for party.
- **2× LED diffuser slots** — long thin windows over each player's LED bar,
  backed by a thin print-in-place light diffuser wall (or a slot for a strip
  of frosted acrylic / translucent print).
- **Center divider** — slightly raised rib so the two play areas read as
  separate; doubles as a finger-stop and hides the LED strip seam.
- **Buzzer grille** — a small array of holes on one edge over the piezo.
- **Screw bosses** — countersunk holes at the four corners + mid-sides.

### Bottom tub (holds the electronics, hidden underneath)

- **MCU pocket** — recessed seat + nub locators for the RP2040-Zero, oriented
  so its USB-C aligns with the edge cutout.
- **Battery bay** — a walled pocket sized to the slim LiPo with a retention
  lip / foam-tape floor; routed away from button posts.
- **Power-circuit shelf** — flat areas with low standoffs / tape pads for the
  TP4056 and MT3608 mini modules.
- **Edge cutouts** — USB-C pass-through (TP4056 charge port) on one long
  edge; SPDT slide-switch slot adjacent so it's flick-able from outside.
- **Cable channels** — shallow troughs guiding the LED strip across the
  center, I²C runs to each OLED, and the button-matrix harness.
- **Standoffs / screw posts** — mate with the faceplate's countersinks;
  heat-set insert bosses (M2 or M2.5) or self-tapping post option (parameter).

### Estimated dimensions (parametric — these are the starting defaults)

| Axis | Driver | Default |
|---|---|---|
| Width (short, across player) | OLED 27.3 + flanking move btns + side margins | **71.3 mm** |
| Length (long, player-to-player) | 2× (OLED + switch row + small LED row + gaps) + centre | **132.6 mm** |
| Thickness | LiPo 6 mm + wiring + faceplate + button protrusion | **13.5 mm** |

Result: **71.3 × 132.6 × 13.5 mm** — smaller than a phone (shortened once
the wide 8-LED HP bar collapsed to a single RGB HP LED). See
[PARTS.md](./PARTS.md) for the derivation from pinned part dimensions.

Every number above will be a named variable at the top of `board.scad`
(`oled_w`, `btn_pitch`, `wall_t`, `led_pitch`, `clearance`, …) so the whole
case re-derives when one part changes.

---

## Ergonomic note / tension to flag

"As small as possible" fights "two adults comfortably press 7 buttons each
facing each other." At 66 mm wide a 4-button move row at ~12 mm pitch fits,
but it is tight. Mitigations baked into the plan: tactile buttons over the
narrowest practical pitch, a raised center divider as a hand-stop, and the
button-pitch / switch-size left as parameters so we can loosen it after a
test print without redesigning. Calling this out now so it's a conscious
trade, not a surprise at print time.

---

## Open questions before modeling

1. ~~Exact module dimensions~~ — **resolved**: canonical parts + dims pinned
   in [PARTS.md](./PARTS.md). Four "high-verify" modules still need
   caliper-check once bought; MT3608 thickness conflict flagged there.
2. **Button choice** — 12 mm tactile (robust, bigger) vs 6 mm + printed
   keycaps (smaller, more print work). Default: 12 mm.
2b. ~~Button mounting~~ — **resolved: stripboard** on tub standoffs.
   Copper strips double as matrix row lines; jumpers for columns.
   `btn_pitch` now grid-locked to a 2.54 mm multiple — default 15.24 mm
   (6 holes) for pressability. Raises board width to ~72 mm. See PARTS.md.
3. ~~LED diffusion~~ — **resolved: option 1, integral & simple.** Faceplate
   has a thin recessed floor (~1 mm, `led_diffuser_t`) spanning each LED
   slot — part of the faceplate, no rebate, no separate insert, no mode
   parameter. Switching to acrylic/open later = faceplate reprint (accepted;
   it's cheap and test-printed first). Print faceplate in translucent/natural
   filament for even glow (material choice, not a CAD change).
4. **Fastener** — heat-set inserts (clean, reusable) vs self-tapping into
   printed posts (zero extra parts). Default: heat-set M2.5.
5. **Printer bed size** — 158 mm length must fit the user's printer; confirm
   bed ≥ ~165 mm, else split parts or shrink further.

---

## Status

- ✅ `cad/board.scad` written — parametric `bottom_tub()` + `top_faceplate()`
  + `assembly()`, with `echo`/`assert` self-checks and `cut=`/`check=` modes.
- ✅ Rev 2 — **web-mirrored layout**: 4 move buttons at OLED corners, 3-switch
  row under the OLED, single RGB HP LED + 3 party LEDs, centred shared buzzer.
- ✅ Validated via the METHODOLOGY render+assert loop: asserts pass, both
  parts single watertight solids (admesh: 1 part each), dims confirmed
  **71.3 × 132.6 × 13.5 mm**.
- ✅ STLs: `cad/bottom-tub.stl`, `cad/top-faceplate.stl`.
- ✅ Renders: `cad/renders/contact-sheet.png`, `cad/renders/assembly-hero.png`.
- ⚠️ **Cross-crate debt:** single-HP-LED diverges from ELECTRONICS.md /
  firmware / web (was 8-LED HP bar). Per the web-fidelity rule those must be
  updated to match (8→1, lose LED-by-LED drain). Not yet propagated.

## Next steps

1. **Propagate the single-HP-LED decision** to ELECTRONICS.md, firmware, web.
2. Caliper the four high-verify parts once bought; update PARTS.md → params.
3. Confirm printer bed (param `bed`, default 220×220) and the B-list defaults.
4. Optional polish: embossed move/switch labels, edge fillets.
5. Test-print the faceplate first (cheap; validates layout + OLED fit).

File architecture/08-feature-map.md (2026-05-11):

# Feature Map: Core vs. Target-Specific

This document lists every significant feature in the workspace and which crate or
runtime owns it.  Use it when deciding where new code belongs.

---

## mega_blastoise_core  (`no_std`, shared by all targets)

### battle_runner

| Feature | Symbol |
|---|---|
| Battle loop | `run_battle` |
| Battle options setup | `battle_options_with_seed`, `demo_battle_options`, `demo_engine_opts` |
| Player setup | `make_player` |
| Log → `BoardEvent` parsing + dispatch | `enrich_and_dispatch` (private) |
| PP refresh from battle RAM (no full CBOR decode) | `MoveSlotCache` (private) |
| Move slot full query on SwitchIn | `query_active_moves` (private) |
| Team slot lookup by name | `query_team_slot_by_name` (private) |
| `team_slot` enrichment on Faint/SwitchIn | inside `enrich_and_dispatch` |
| Idle-to-demo delay shared constant | `LOBBY_DEMO_DELAY_MS` |

### battle_effects

| Feature | Symbol |
|---|---|
| Hardware output trait | `BoardEffects` (async `on_event`) |
| No-op sink | `NoopBoardEffects` |
| Typed event queue with split-dedup | `BoardEventQueue` |
| Convenience log-line processor | `process_new_log_lines` |
| Shared animation delay constants | `anim::{MOVE_MS, DAMAGE_MS, SWITCH_IN_MS, FAINT_MS, WIN_MS, EFFECT_MS, BRIEF_MS}` |
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

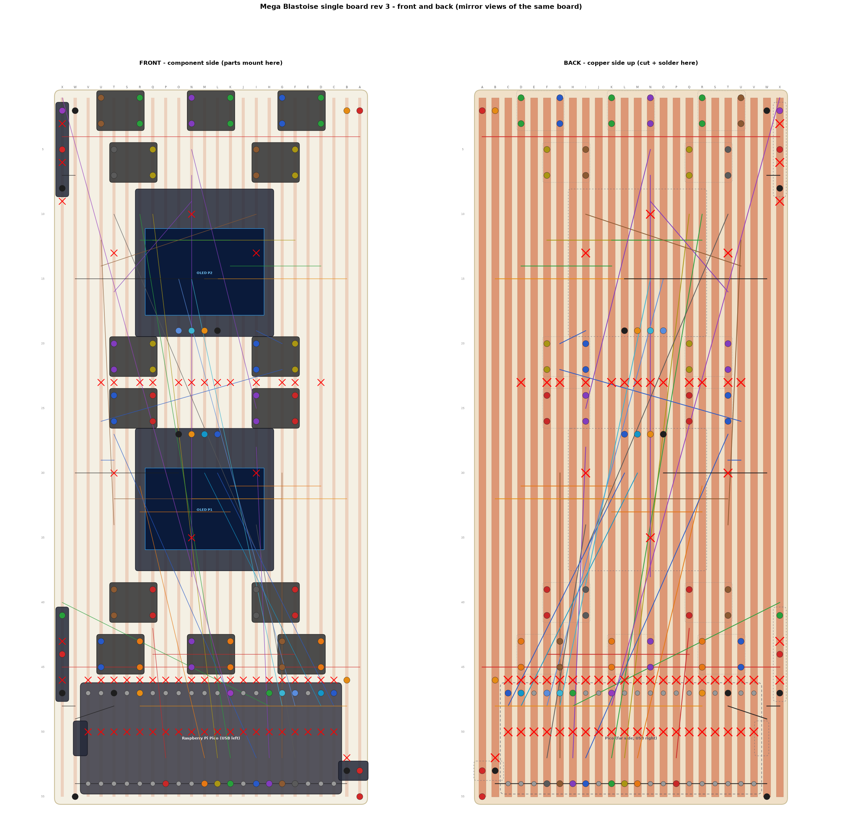
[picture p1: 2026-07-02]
hardware/stripboard/mega_blastoise_single_board_both.png

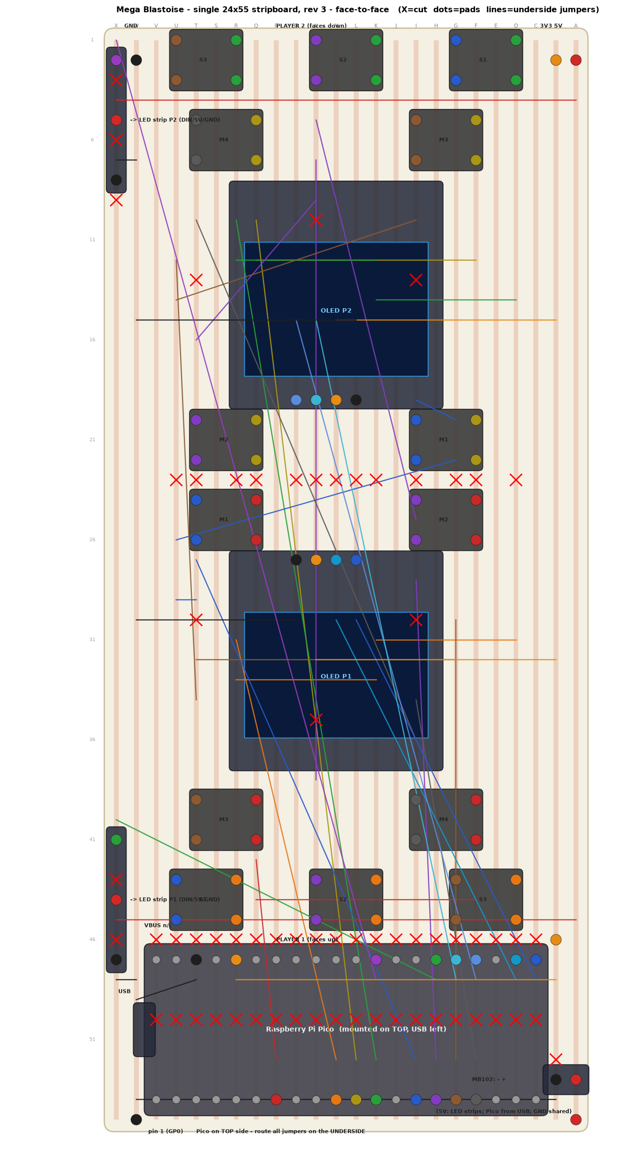
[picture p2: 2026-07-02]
hardware/stripboard/mega_blastoise_single_board_preview.png

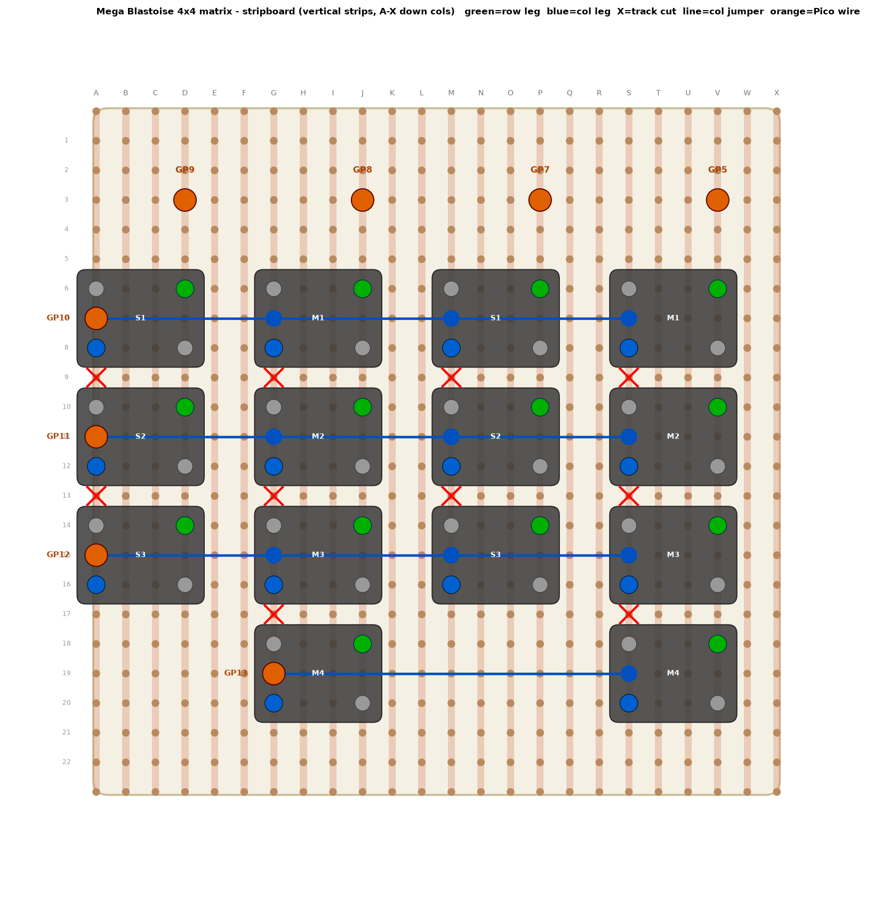
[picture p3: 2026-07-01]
hardware/stripboard/mega_blastoise_matrix_preview.png

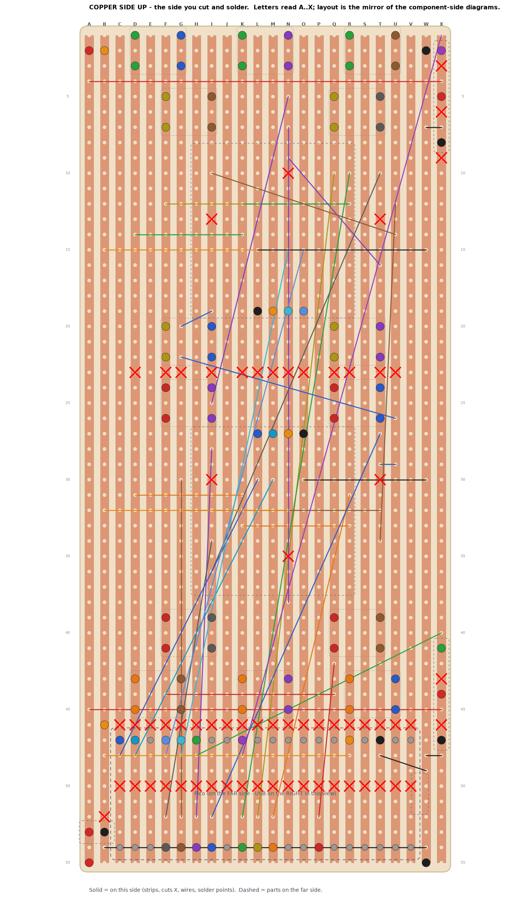
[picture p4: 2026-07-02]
hardware/stripboard/mega_blastoise_single_board_copper.png

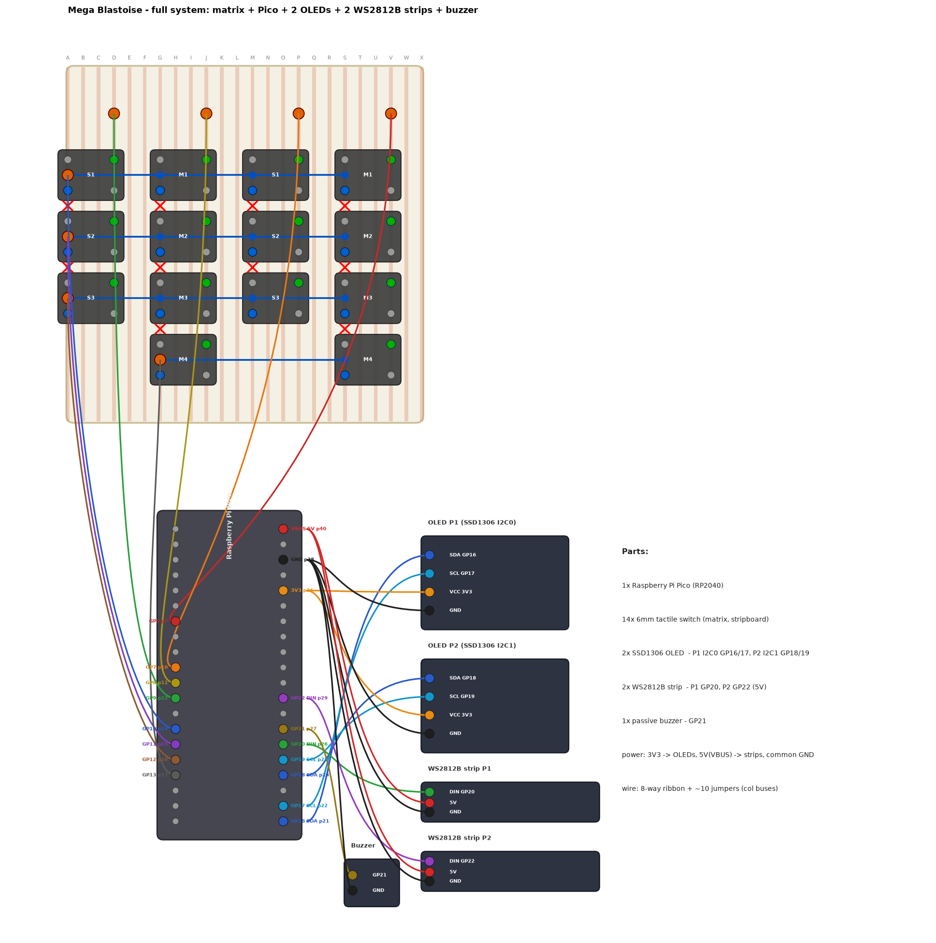
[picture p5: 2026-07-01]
hardware/stripboard/mega_blastoise_matrix_full_preview.png

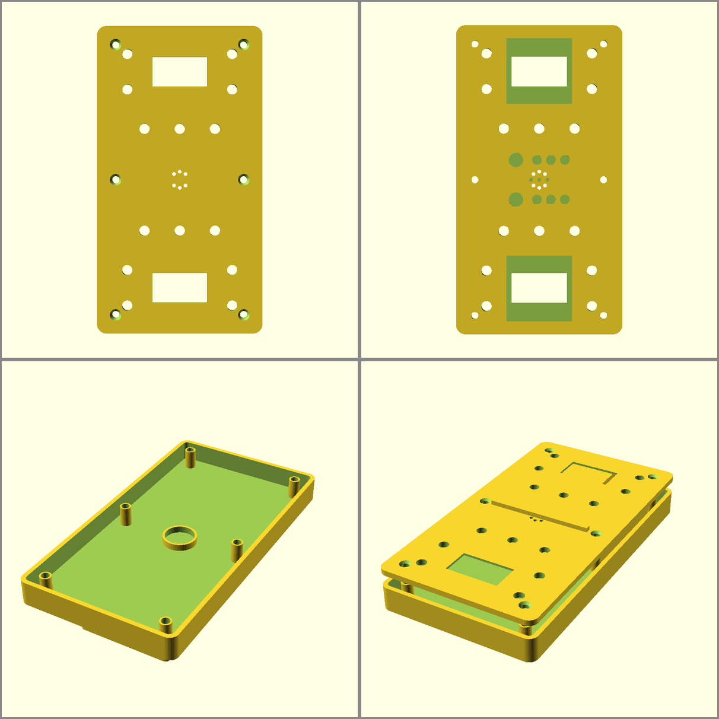
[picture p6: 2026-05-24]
cad/renders/contact-sheet.png

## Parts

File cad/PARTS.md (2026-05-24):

# Pinned Parts — dimensions for the CAD model

Canonical parts + datasheet/nominal dimensions feeding `cad/board.scad`.
Resolves open question #1 in [DESIGN.md](./DESIGN.md).

**Clone reality:** these modules are made by many vendors with ±1–3 mm
variation. Strategy: model nominal dims + the listed clearance, leave each as
a named parameter, and **caliper-verify the parts you actually buy** before
the final print. The "Verify" column flags which ones bite hardest if wrong.

All mm. L = long axis of part, W = short, H = tallest point above its seat.

| # | Part | Canonical pick | L | W | H | Clearance to add | Verify | Notes |
|---|---|---|---|---|---|---|---|---|
| 1 | MCU | Waveshare **RP2040-Zero** | 23.5 | 18.0 | ~4.5 | +0.4 mm/side pocket | med | USB-C overhangs one short edge ~1.5 mm → align to edge cutout. Castellated + 2 through-hole rows. |
| 2 | Display ×2 | **0.96" SSD1306 I²C** OLED (4-pin) | 27.3 | 27.3 | ~4.1 | +0.5 mm/side; window = active +1 mm | **high** | Active glass 21.74 × 10.86 mm. Some clones 26×26 — measure. Glass-out, seat on internal ledge, header to inside. |
| 3 | Power module | **MH-CD42** (IP5306): USB-C charge + 5 V/2 A boost + protection, all-in-one | 34.0 | 22.0 | ~7.0 | +0.4 mm/side | **high** | Replaces separate TP4056+MT3608. ~7 mm lies flat in the 9 mm cavity → **no bump-out**. USB-C to edge cutout. Clones vary — caliper. |
| 5 | Battery | **LiPo 553450** ~1200 mAh | 50.0 | 34.0 | 5.5 | +1 mm L/W, +0.8 mm H (swell) | **high** | Single biggest footprint. Pocket ~51 × 35 × 6.3. Pad floor with foam tape. |
| 6 | Power switch | **SS-12D00** SPDT slide | 8.7 | 3.6 | 3.5 | slot + actuator slot | med | Tiny. Actuator protrudes through a side-edge slot, flick from outside. |
| 7 | Buzzer | 12 mm passive piezo | Ø12 | — | 9.0 | +0.5 mm radial | low | Round pocket; grille holes in faceplate above it. |
| 8 | Buttons ×14 | 12 mm 4-leg tactile (THT) | 12.0 | 12.0 | ~7.3 | actuator hole Ø4.0 | med | Soldered to stripboard (#12). `btn_pitch` grid-locked: default 15.24 mm (6 × 2.54). |
| 12 | Button substrate | Stripboard ~1.6 mm, 2.54 mm grid | cut to fit | cut to fit | 1.6 | standoff posts in tub | low | One piece per player's 7-button cluster. Strips = matrix rows; jumper columns. |
| 13 | LED diffuser | Integral faceplate skin (~1 mm) | per-window | — | 1.0 | part of faceplate, no separate part | low | Blind round windows, translucent front skin. Print faceplate in translucent filament. |
| 9 | LEDs ×8 | **5 mm through-hole WS2812B** (1 HP + 3 party per player) | Ø5 | — | ~8 | blind window pocket | low | **HP = single RGB LED**, colour = health. Stripboard-friendly (matches #12). ~$5/5-pack; prototype + final. ⚠ cross-crate change — see note. |
| 10 | Passives | 330 Ω R, 470 µF + 100 nF caps | — | — | ≤12 | lump in wiring budget | low | 470 µF electrolytic ~Ø8 × 12 mm — lay sideways in a cable channel. |
| 11 | Fasteners | M2.5 heat-set inserts + screws | — | — | — | boss OD 5, bore Ø3.6 | — | Inserts in tub posts; countersinks in faceplate. |

---

## ✅ Resolved: integrated power module (was MT3608 thickness conflict)

The original TP4056 + MT3608 split put a 14 mm-tall boost module in a 9 mm
cavity, forcing an ugly underside bump-out. **Resolved** by swapping both
for a single **MH-CD42 (IP5306)** all-in-one: USB-C charge + 5 V boost +
protection in one ~34 × 22 × **7 mm** board. 7 mm < the 9 mm cavity, so it
lies flat — **bump-out eliminated**, tub is now a clean simple clamshell.

The `boost_bumpout` parameter and blister code remain in `board.scad`
(default `false`, auto-disabled since the module now fits) as a fallback if
a taller module is ever substituted.

> ⚠ **BOM deviation, logged not propagated:** ELECTRONICS.md still specs
> TP4056 + MT3608 separately. Per the exploratory-mode rule, this is *not*
> back-propagated to ELECTRONICS.md / firmware until the design is finalized.
> Functionally equivalent (charge + 5 V boost + protection); the IP5306's
> auto-boost / double-tap-enable behaviour differs from a plain slide switch
> — revisit power-on UX when propagating.

---

## Recomputed board envelope (from pinned dims)

| Axis | Drivers | Result |
|---|---|---|
| Width | OLED 27.3 + 2× flanking move btn + 2×7 margin | **71.3 mm** |
| Length | 2 × (margin 6 + OLED 27.3 + switch row 12 + small LED row + gaps) + centre 12 | **132.6 mm** |
| Thickness | LiPo 6.3 + wiring + faceplate 2.5 + button travel ≈ **13.5 mm** |

Updated envelope: **71.3 × 132.6 × 13.5 mm** — smaller than a phone;
shortened after the wide LED bar collapsed to a single HP LED, and now a
clean flat clamshell (no bump-out) thanks to the integrated power module.

> ⚠ **Cross-crate change:** single-HP-LED + web-style button layout deviates
> from ELECTRONICS.md (was 24 WS2812B, 8-LED HP bar). Per the web-fidelity
> rule, ELECTRONICS.md / firmware / web must be updated to match (8→1 HP
> LED, lose LED-by-LED drain). Tracked as a project decision, not yet
> propagated to those crates.

---

## Parameter name map (→ `board.scad`)

Each part drives named variables so the case re-derives on any change:

```
rp2040    = [23.5, 18.0, 4.5];     oled       = [27.3, 27.3, 4.1];
oled_active = [21.74, 10.86];      pmod       = [34.0, 22.0, 7.0];
lipo      = [50.0, 34.0, 5.5];     // pmod = MH-CD42 (charge+boost+protect)
slide_sw  = [8.7, 3.6, 3.5];       buzzer_d   = 12.0;  buzzer_h = 9.0;
btn       = 12.0;  btn_pitch = 15.24;  move_gap = 3.0;  // switch row + flank
hp_led_d  = 5.0;   party_led_d = 3.0;  party_led_n = 3;  party_led_pitch = 6.0;
strip_grid = 2.54;                      // stripboard, btn_pitch = N*grid
led_diffuser_t = 1.0;  // translucent front skin over each blind LED window
clearance = 0.4;   wall_t = 2.0;   faceplate_t = 2.5;
boost_bumpout = true;              insert_boss_od = 5.0;
bed = [220, 220];   // user's printer bed — assert board fits
```

---

## Still needs the user

- **Confirm / order the exact SKUs** for the "high"-verify rows (OLED #2,
  power module #3, LiPo #5) and caliper the received parts → update table.
- **Printer bed size** — set `bed` so the fit assertion is real (132.6 mm
  length must clear the bed; default 220×220).
- **Power-on UX** — IP5306 auto-boosts / double-tap-enables; decide whether
  the SPDT slide switch stays (in series on 5 V out) when propagating.

Sources: [Waveshare RP2040-Zero](https://www.waveshare.com/rp2040-zero.htm),
[RP2040-Zero datasheet PDF](https://files.waveshare.com/upload/4/4c/RP2040_Zero.pdf),
[MH-CD42 / IP5306 (done.land)](https://done.land/components/power/powersupplies/battery/chargers/charge-discharge/ip5306/mh-cd42/),
[IP5306 module (done.land)](https://done.land/components/power/powersupplies/battery/chargers/charge-discharge/ip5306/),
[0.96" SSD1306 OLED (displaymodule)](https://www.displaymodule.com/products/0-96-inch-oled-graphic-display-128x64-with-i2c),
[SSD1306 OLED datasheet (Mouser)](https://www.mouser.com/datasheet/2/1398/Soldered_333099-3395096.pdf).

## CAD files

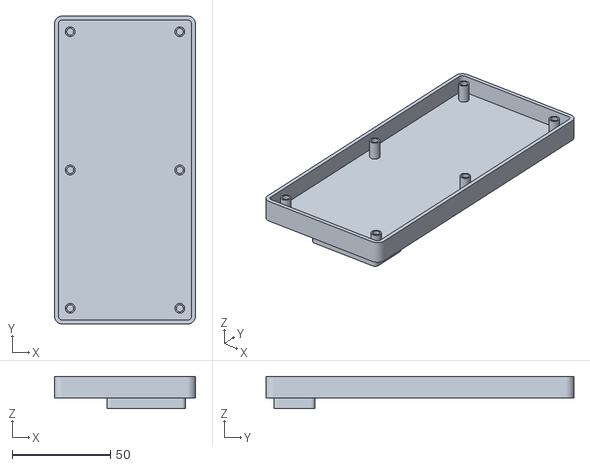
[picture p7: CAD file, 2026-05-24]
cad/bottom-tub.stl
71.7 x 156.6 x 16.4

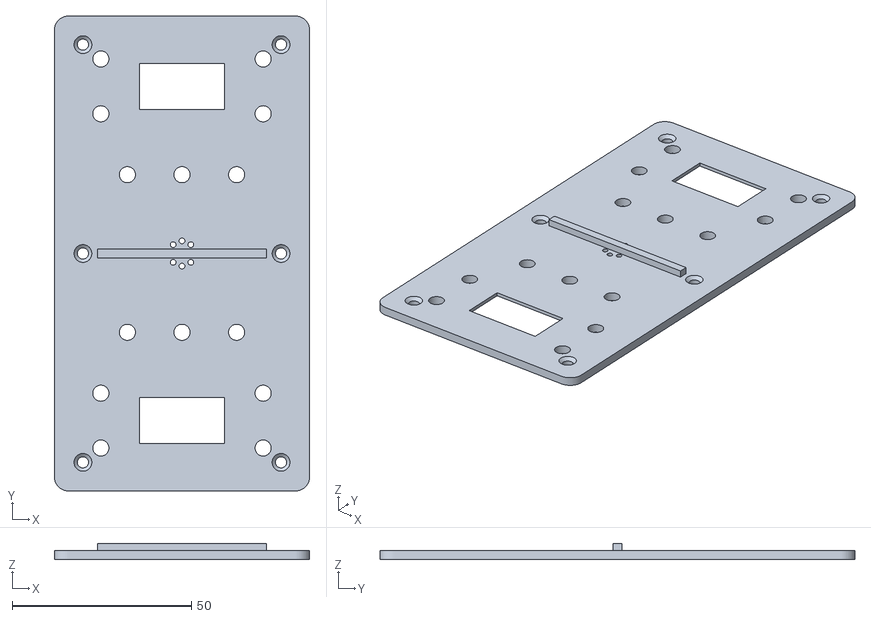
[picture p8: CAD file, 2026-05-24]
cad/stl/dual-oled-128x64-faceplate.stl
71.3 x 132.6 x 4.50

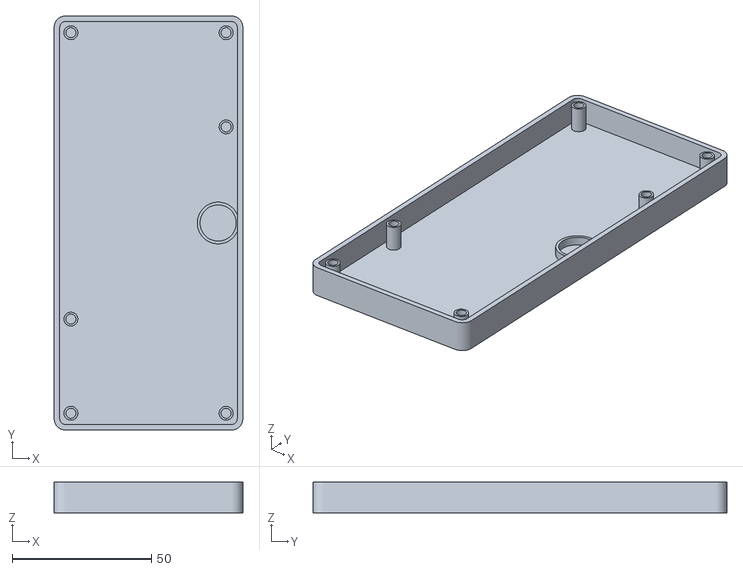
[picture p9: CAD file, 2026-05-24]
cad/stl/single-st7789-nfc-tub.stl
67.7 x 148.6 x 11.0

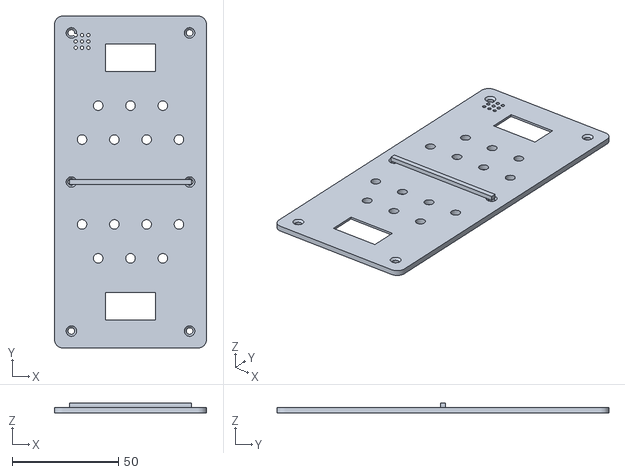
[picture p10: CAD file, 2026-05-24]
cad/top-faceplate.stl
71.7 x 156.6 x 4.50

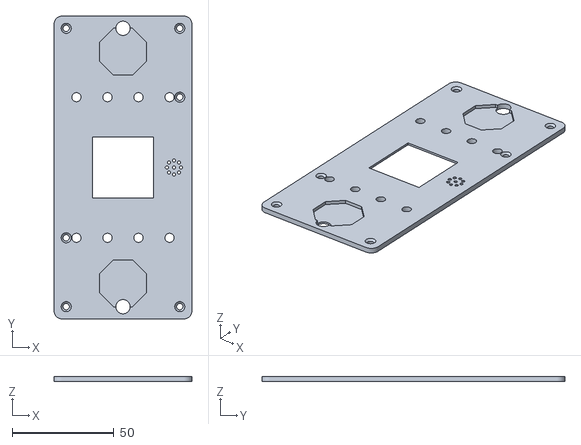
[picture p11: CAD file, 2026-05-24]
cad/stl/single-st7789-nfc-faceplate.stl
67.7 x 148.6 x 2.50

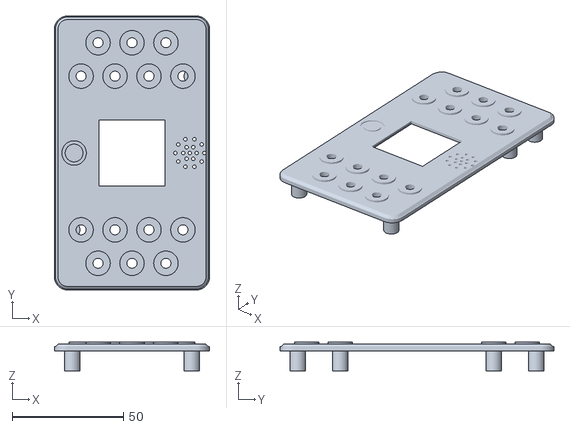
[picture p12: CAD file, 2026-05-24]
cad/stl/nintendo-style-faceplate.stl
69.7 x 123.0 x 12.9

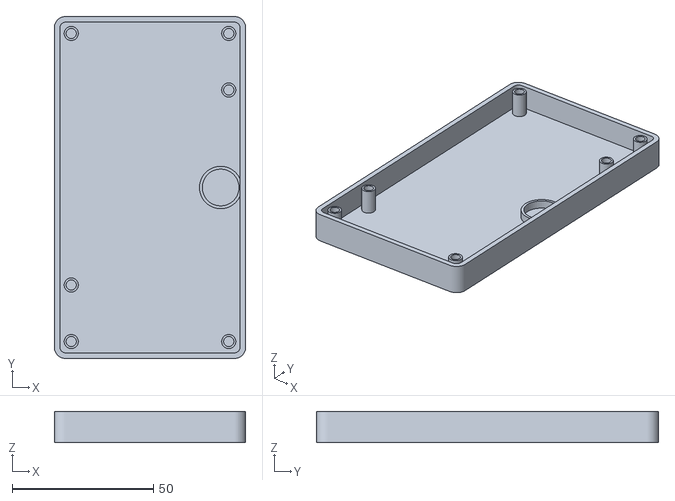
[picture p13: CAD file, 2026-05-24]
cad/stl/single-st7789-tub.stl
67.7 x 121.0 x 11.0

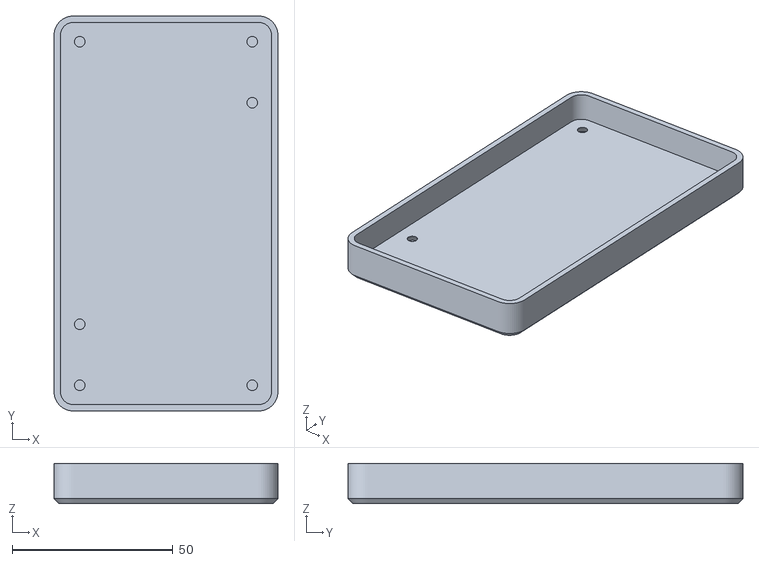
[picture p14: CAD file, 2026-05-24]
cad/stl/nintendo-style-tub.stl
69.7 x 123.0 x 12.6

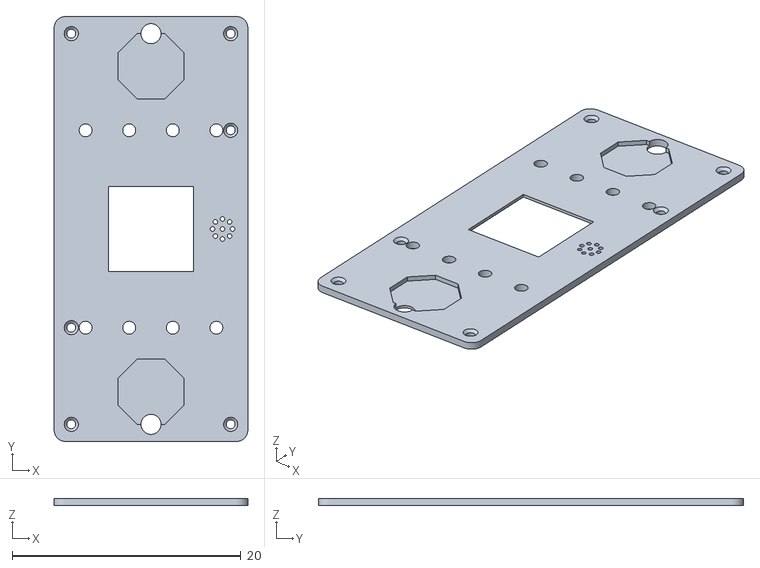
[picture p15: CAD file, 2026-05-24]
cad/stl/single-st7789-nfc-faceplate-q4.stl
16.9 x 37.1 x 0.625

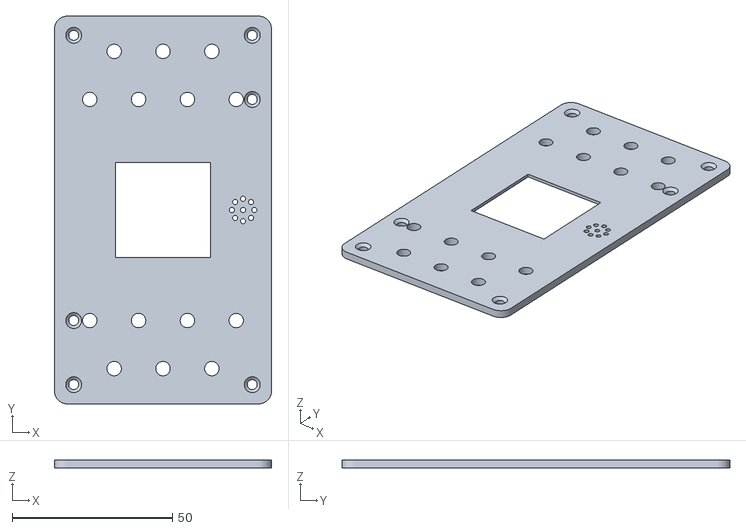
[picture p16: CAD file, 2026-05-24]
cad/stl/single-st7789-faceplate.stl
67.7 x 121.0 x 2.50

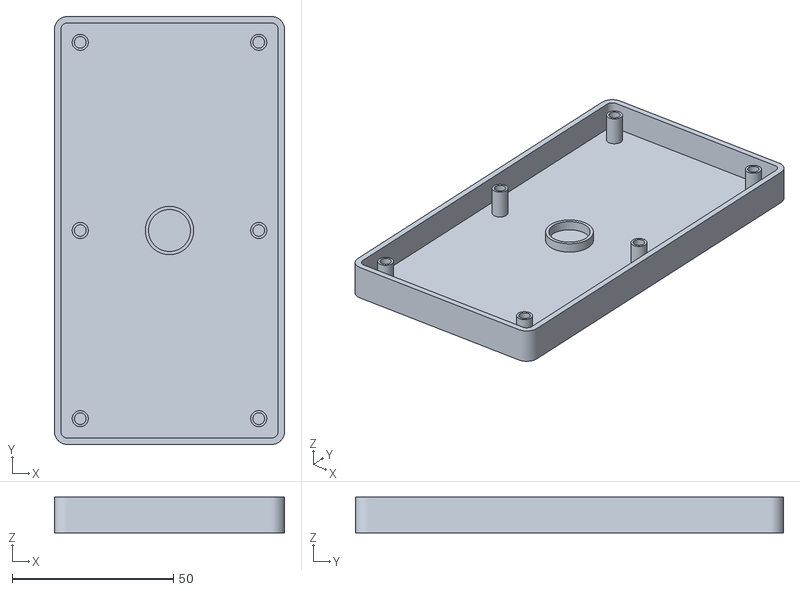
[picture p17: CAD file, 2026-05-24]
cad/stl/dual-oled-128x64-tub.stl
71.3 x 132.6 x 11.0

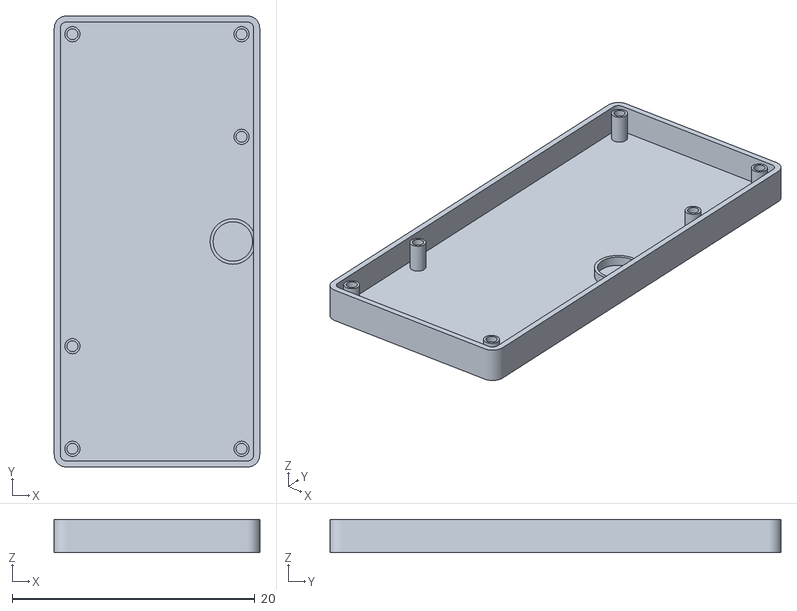
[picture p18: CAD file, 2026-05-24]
cad/stl/single-st7789-nfc-tub-q4.stl
16.9 x 37.1 x 2.75

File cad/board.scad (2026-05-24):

// Mega Blastoise — enclosure  ::  VARIANT: nintendo-style
// Based on single-st7789, redesigned the way Nintendo (Yokoi/Iwata) would:
//  - NFC the amiibo way: antenna BEHIND the screen, no slot, nothing to
//    lose; coins are optional sugar — base game still works on buttons.
//  - Screwless play face: fasteners hidden on the BOTTOM.
//  - Rounded, friendly shell: big radius + chamfered top edge.
//  - Molded-key feel: raised bezel ring around every button.
//  - Speaker (sampled cries), not a bare piezo.
//  - Sized for hand-feel, not minimum dimensions.
//
// Render selectors:  part assembly|internals|tub|faceplate  cut|check|show_ghosts

part  = "assembly";
cut   = "none";
check = false;
show_ghosts = true;

/* ───────────────────────── pinned parts ─────────────────────────────────── */
rp2040  = [23.5, 18.0, 4.5];
disp    = [32.0, 33.0, 4.5];                // ST7789 1.54" 240x240 SPI
disp_active = [27.7, 27.7];
disp_lip_t  = 1.0;
disp_conn   = 5.0;
pmod    = [34.0, 22.0, 7.0];
lipo    = [50.0, 34.0, 5.5];
slide_sw   = [8.7, 3.6, 3.5];
spk_d   = 14.0;  spk_h = 5.0;               // small speaker, not a piezo
btn        = 12.0;  btn_pitch = 15.24;
btn_hole_d = 4.5;   key_bezel_d = 11.0;  key_bezel_h = 0.9;
hp_led_d     = 5.0;
party_led_d  = 3.0;  party_led_n = 3;  party_led_pitch = 6.0;
led_group_gap = 5.0;
led_win_clear = 0.6;
nfc_coil_d = 26.0;                          // antenna behind the display
strip_grid = 2.54;
clearance  = 0.4;
wall_t     = 2.0;
floor_t    = 2.0;
faceplate_t   = 3.0;                        // a touch thicker → solid feel
led_diffuser_t = 1.0;
interior_depth = 9.0;
boost_bumpout  = false;
// M2.5 heat-set inserts — chosen for an iteration-heavy prototype that gets
// opened/closed constantly (metal threads survive ~unlimited cycles; plastic
// self-tap threads strip in ~10). Boss wall ≈1.7 mm so the hot insert
// doesn't split it. insert_bore_d: tune to the actual insert on hand.
insert_boss_od = 7.0;  insert_bore_d = 3.6;
screw_d        = 2.7;  screw_head_d  = 5.2;
bed = [220, 220];
corner_r = 6;  shell_cham = 1.6;  $fn = 56; // rounder, chamfered top edge
eps = 0.02;

/* ───────────────────────── derived geometry ─────────────────────────────── */
side_margin = 6;        // more generous than the size-minimised variants
end_margin  = 6;
g_disp = 4;  g_led = 3;  g_move = 3;

led_row_h  = max(hp_led_d, party_led_d);
move_row_w = 3*btn_pitch + btn;
content_w  = max(move_row_w, disp[0]);
board_w    = content_w + 2*side_margin;

y_led  = disp[1]/2 + g_disp + led_row_h/2;
y_move = y_led + led_row_h/2 + g_led + btn/2;
y_sw   = y_move + btn/2 + g_move + btn/2;
half_l = y_sw + btn/2 + end_margin;
board_l = 2*half_l;
tub_h   = floor_t + interior_depth;
total_h = tub_h + faceplate_t;

function yc(p, o) = p * o;

inset = side_margin + 2;
screw_pts = concat(
  [ for (sx=[-1,1], sy=[-1,1]) [sx*(board_w/2-inset), sy*(board_l/2-inset)] ],
  [ [board_w/2-inset, y_move], [-(board_w/2-inset), -y_move] ]);
post_h = interior_depth;                    // faceplate posts span the cavity

spk_x = disp[0]/2 + spk_d/2 + 3;
led_row_w = hp_led_d + led_group_gap + (party_led_n-1)*party_led_pitch + party_led_d;
led0_x = -led_row_w/2 + hp_led_d/2;
function party_x(i) = -led_row_w/2 + hp_led_d + led_group_gap
                      + i*party_led_pitch + party_led_d/2;

/* ───────────────────────── self-checks ──────────────────────────────────── */
assert(board_w <= bed[0] && board_l <= bed[1],
       str("Board ", board_w, "x", board_l, " exceeds bed ", bed));
assert(abs(btn_pitch/strip_grid - round(btn_pitch/strip_grid)) < 1e-3,
       "btn_pitch must be a multiple of stripboard grid 2.54");
assert(spk_x - spk_d/2 - 1.5 > disp[0]/2, "speaker overlaps display");
assert(faceplate_t > led_diffuser_t && faceplate_t > disp_lip_t,
       "faceplate too thin");
assert(shell_cham < faceplate_t && shell_cham < corner_r,
       "shell_cham too large");
assert(boost_bumpout || interior_depth >= pmod[2] + clearance,
       "power module won't fit");

echo(VARIANT="nintendo-style", board_w=board_w, board_l=board_l,
     total_h=total_h, half_l=half_l, faceplate_t=faceplate_t);

/* ───────────────────────── helpers ──────────────────────────────────────── */
module rrect(w, l, r) hull() for (sx=[-1,1], sy=[-1,1])
  translate([sx*(w/2-r), sy*(l/2-r)]) circle(r);
module slab(w, l, h, r) linear_extrude(h) rrect(w, l, r);

// slab with the TOP outer edge chamfered (friendly, hand-soft)
module cham_slab(w, l, h, r, ch) {
  union() {
    slab(w, l, h-ch+0.5, r);                 // base overlaps the cap by 0.5
    translate([0,0,h-ch]) hull() {           // (no coincident face → 1 part)
      linear_extrude(eps) rrect(w, l, r);
      translate([0,0,ch]) linear_extrude(eps)
        rrect(w-2*ch, l-2*ch, max(1, r-ch));
    }
  }
}
module led_window(d)
  translate([0,0,-eps])
    cylinder(d=d+2*led_win_clear, h=faceplate_t - led_diffuser_t + eps);

module button_centres() {
  for (p=[-1,1]) {
    for (i=[0:3])  translate([(i-1.5)*btn_pitch, yc(p,y_move)]) children();
    for (i=[-1:1]) translate([i*btn_pitch,       yc(p,y_sw)])  children();
  }
}

/* ───────────────────────── bottom tub ───────────────────────────────────── */
boost_drop = pmod[2] + clearance - interior_depth;
boost_c = [ board_w/2 - pmod[0]/2 - side_margin,
           -board_l/2 + pmod[1]/2 + end_margin ];

module bottom_tub() {
  difference() {
    union() {
      slab(board_w, board_l, tub_h, corner_r);     // bottom chamfer
      // soften the very bottom edge too
      mirror([0,0,1]) translate([0,0,-eps]) hull() {
        linear_extrude(eps) rrect(board_w, board_l, corner_r);
        translate([0,0,shell_cham]) linear_extrude(eps)
          rrect(board_w-2*shell_cham, board_l-2*shell_cham,
                max(1,corner_r-shell_cham));
      }
    }
    translate([0,0,floor_t])
      slab(board_w-2*wall_t, board_l-2*wall_t, tub_h, max(1,corner_r-wall_t));
    translate([board_w/2-wall_t-1, -board_l/2+end_margin+pmod[1]/2, floor_t+2])
      cube([wall_t+3, 9, 4], center=true);
    translate([board_w/2-wall_t-1, -board_l/2+end_margin+pmod[1]+8,
               floor_t+slide_sw[2]/2+1])
      cube([wall_t+3, slide_sw[0]+1, slide_sw[2]+1], center=true);
    // hidden bottom fasteners: clearance bore + countersink on the underside
    for (pt = screw_pts) translate([pt[0], pt[1], 0]) {
      translate([0,0,-eps]) cylinder(d=screw_d+0.6, h=tub_h+2*eps);
      translate([0,0,-eps]) cylinder(d1=screw_head_d, d2=screw_d, h=2.2);
    }
  }
}

/* ───────────────────────── top faceplate ────────────────────────────────── */
module top_faceplate() {
  difference() {
    union() {
      cham_slab(board_w, board_l, faceplate_t, corner_r, shell_cham);
      // molded-key bezel ring around every button (raised, friendly)
      button_centres() translate([0,0,faceplate_t-0.6])
        cylinder(d=key_bezel_d, h=key_bezel_h+0.6);   // sink 0.6 into plate
      // hidden screw posts hanging from the underside
      for (pt = screw_pts) translate([pt[0], pt[1], -post_h])
        cylinder(d=insert_boss_od, h=post_h+1.2);      // overlap plate solidly
    }
    // central display
    translate([0,0,-eps])
      linear_extrude(faceplate_t - disp_lip_t + eps)
        square([disp[0]+2*clearance, disp[1]+2*clearance], center=true);
    translate([0,0,-eps])
      linear_extrude(faceplate_t + key_bezel_h + 2*eps)
        square([disp_active[0]+2, disp_active[1]+2], center=true);
    translate([0, -(disp[1]/2), -eps])
      linear_extrude(faceplate_t - disp_lip_t + eps)
        square([disp[0]+2*clearance, disp_conn], center=true);
    // button actuator holes (through bezels too)
    button_centres()
      translate([0,0,-eps]) cylinder(d=btn_hole_d,
                                     h=faceplate_t+key_bezel_h+2*eps);
    // LED windows
    for (p=[-1,1]) translate([0, yc(p,y_led), 0]) {
      translate([led0_x,0,0]) led_window(hp_led_d);
      for (i=[0:party_led_n-1])
        translate([party_x(i),0,0]) led_window(party_led_d);
    }
    // embossed amiibo-style tap glyph beside the screen (cosmetic, shallow)
    translate([-spk_x, 0, faceplate_t-0.5]) difference() {
      cylinder(d=11, h=0.5+eps);
      translate([0,0,-eps]) cylinder(d=8, h=0.5+3*eps);
    }
    // speaker grille beside the display (sparse: holes never merge into a
    // ring that would isolate the centre)
    translate([spk_x,0,0]) {
      translate([0,0,-eps]) cylinder(d=1.6, h=faceplate_t+2*eps);
      for (a=[0:60:359]) translate([cos(a)*3, sin(a)*3, -eps])
        cylinder(d=1.6, h=faceplate_t+2*eps);
      for (a=[0:36:359]) translate([cos(a)*6.5, sin(a)*6.5, -eps])
        cylinder(d=1.6, h=faceplate_t+2*eps);
    }
    // insert bores up into the hidden posts (no front-face holes)
    for (pt = screw_pts) translate([pt[0], pt[1], -post_h-eps])
      cylinder(d=insert_bore_d, h=post_h+1);
  }
}
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

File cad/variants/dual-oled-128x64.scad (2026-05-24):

// Mega Blastoise — enclosure  ::  VARIANT: dual-oled-128x64
// Two per-player 128x64 mono SSD1306 OLEDs (web-mirrored layout).
// Parametric two-part clamshell. See cad/DESIGN.md, cad/PARTS.md, cad/METHODOLOGY.md.
//
// Layout mirrors the web client per player: OLED centred, 4 move buttons at
// the OLED corners, a 3-button switch row directly under it, then a small
// LED row (1 RGB HP LED + 3 party LEDs). Buzzer is centred (fair for 2P).
//
// Render selectors (override with -D):
//   part : "assembly" | "internals" | "tub" | "faceplate"
//          ("internals" = tub + component ghosts, no faceplate covering them)
//   cut  : "none" | "width" | "length"
//   check: false | true     (skip geometry, run asserts+echo only)

part  = "faceplate";
cut   = "none";
check = false;
show_ghosts = true;     // assembly view: draw placeholder components

/* ───────────────────────── pinned parts (cad/PARTS.md) ───────────────────── */
rp2040  = [23.5, 18.0, 4.5];
oled    = [27.3, 27.3, 4.1];
oled_active = [21.74, 10.86];
// Integrated charge+boost+protection (MH-CD42 / IP5306): replaces the
// separate TP4056 + MT3608. Lies flat (≈7 mm < cavity) → no bump-out.
pmod    = [34.0, 22.0, 7.0];
lipo    = [50.0, 34.0, 5.5];
slide_sw   = [8.7, 3.6, 3.5];
buzzer_d   = 12.0;  buzzer_h = 9.0;
btn        = 12.0;  btn_pitch = 15.24;     // switch row, grid-locked 6 * 2.54
btn_hole_d = 4.5;                          // actuator clearance through faceplate
move_gap   = 3.0;                          // gap between OLED edge and move btn
hp_led_d     = 5.0;                        // single RGB HP-LED window
party_led_d  = 3.0;  party_led_n = 3;  party_led_pitch = 6.0;
led_group_gap = 5.0;                       // HP-LED → party group
led_win_clear = 0.6;
strip_grid = 2.54;
clearance  = 0.4;
wall_t     = 2.0;
floor_t    = 2.0;
faceplate_t   = 2.5;
led_diffuser_t = 1.0;                      // translucent front skin over LEDs
oled_lip_t     = 1.0;                      // bezel lip that hides OLED PCB edge
interior_depth = 9.0;                      // tub cavity for battery/power stack
boost_bumpout  = false;     // not needed with the flat integrated pmod
insert_boss_od = 5.0;  insert_bore_d = 3.6;
screw_d        = 2.7;  screw_head_d  = 5.0;
bed = [220, 220];
corner_r = 4;  $fn = 48;
eps = 0.02;                                // overshoot so no cut face is coplanar
rib_w = 2.5;  rib_h = 2;  cs_depth = 1.2;

/* ───────────────────────── derived geometry ─────────────────────────────── */
side_margin = 7;
end_margin  = 6;
g_oled   = 5;       // OLED block → switch row
g_switch = 5;       // switch row → LED row
center_gap = 12;    // central band (divider + shared buzzer)

move_dx = oled[0]/2 + move_gap + btn/2;        // move-btn column offset from centre
move_dy = oled[1]/2 - btn/2;                   // move-btn rows = OLED top/bottom
switch_row_w = (btn_pitch)*(2) + btn;          // 3 switch buttons
content_w = max(2*move_dx + btn, switch_row_w);
board_w   = content_w + 2*side_margin;

led_row_w = hp_led_d + led_group_gap + (party_led_n-1)*party_led_pitch + party_led_d;
led_row_h = max(hp_led_d, party_led_d);

// per-player feature offsets from the player's outer edge
o_oled   = end_margin + oled[1]/2;
o_switch = end_margin + oled[1] + g_oled + btn/2;
o_led    = o_switch + btn/2 + g_switch + led_row_h/2;
half_l   = o_led + led_row_h/2 + center_gap/2;
board_l  = 2*half_l;
tub_h    = floor_t + interior_depth;
total_h  = tub_h + faceplate_t;

function yc(p, o) = p * (half_l - o);           // p=-1 P1 (bottom), p=+1 P2 (top)

inset = side_margin + 1;
screw_pts = concat(
  [ for (sx=[-1,1], sy=[-1,1]) [sx*(board_w/2-inset), sy*(board_l/2-inset)] ],
  [ [board_w/2-inset, 0], [-(board_w/2-inset), 0] ]);
rib_half = board_w/2 - inset - 4;               // stops short of mid-side screws

// LED-row X positions (group centred): HP led then 3 party leds
led0_x = -led_row_w/2 + hp_led_d/2;
function party_x(i) = -led_row_w/2 + hp_led_d + led_group_gap
                      + i*party_led_pitch + party_led_d/2;

/* ───────────────────────── self-checks ──────────────────────────────────── */
assert(board_w <= bed[0] && board_l <= bed[1],
       str("Board ", board_w, "x", board_l, " exceeds bed ", bed));
assert(abs(btn_pitch/strip_grid - round(btn_pitch/strip_grid)) < 1e-3,
       "btn_pitch must be an integer multiple of stripboard grid 2.54");
assert(move_dx - btn/2 >= oled[0]/2,
       "move buttons overlap the OLED — increase move_gap");
assert(interior_depth >= lipo[2] + clearance + 1,
       "interior_depth too shallow for the LiPo");
assert(faceplate_t > led_diffuser_t && faceplate_t > oled_lip_t,
       "faceplate too thin for diffuser skin / OLED lip");
assert(content_w + 2*side_margin <= board_w + 1e-6, "content overflows width");
assert(boost_bumpout || interior_depth >= pmod[2] + clearance,
       "power module won't fit: deepen interior_depth or enable boost_bumpout");

echo(board_w = board_w, board_l = board_l, total_h = total_h, tub_h = tub_h,
     half_l = half_l, content_w = content_w, led_row_w = led_row_w,
     o_oled = o_oled, o_switch = o_switch, o_led = o_led);

/* ───────────────────────── helpers ──────────────────────────────────────── */
module rrect(w, l, r) hull() for (sx=[-1,1], sy=[-1,1])
  translate([sx*(w/2-r), sy*(l/2-r)]) circle(r);
module slab(w, l, h, r) linear_extrude(h) rrect(w, l, r);

// blind LED window: pocket from the underside, led_diffuser_t translucent
// front skin remains (lit through it). Centred at origin.
module led_window(d)
  translate([0,0,-eps])
    cylinder(d=d+2*led_win_clear, h=faceplate_t - led_diffuser_t + eps);

module button_centres() {
  for (p=[-1,1]) {
    // 4 move buttons at the OLED corners
    for (sx=[-1,1], sy=[-1,1])
      translate([sx*move_dx, yc(p,o_oled) + sy*move_dy]) children();
    // 3 switch buttons in a row under the OLED
    for (i=[-1:1]) translate([i*btn_pitch, yc(p,o_switch)]) children();
  }
}

/* ───────────────────────── bottom tub ───────────────────────────────────── */
// blister geometry — only engages if the power module is taller than the
// cavity. With the flat integrated pmod this is negative, so no bump-out.
boost_drop = pmod[2] + clearance - interior_depth;       // depth below floor
boost_c = [ board_w/2 - pmod[0]/2 - side_margin,
           -board_l/2 + pmod[1]/2 + end_margin ];

module bottom_tub() {
  difference() {
    union() {
      slab(board_w, board_l, tub_h, corner_r);
      if (boost_bumpout && boost_drop > 0)
        translate([boost_c[0], boost_c[1], -boost_drop])
          slab(pmod[0]+2*(wall_t+clearance),
               pmod[1]+2*(wall_t+clearance),
               boost_drop + floor_t, 2);
    }
    translate([0,0,floor_t])
      slab(board_w-2*wall_t, board_l-2*wall_t, tub_h, max(1,corner_r-wall_t));
    // hollow the blister so the tall boost module actually drops in,
    // leaving floor_t of plastic at its base
    if (boost_bumpout && boost_drop > 0)
      translate([boost_c[0], boost_c[1], -boost_drop+floor_t])
        linear_extrude(boost_drop + eps)
          square([pmod[0]+2*clearance, pmod[1]+2*clearance], center=true);
    // USB-C charge pass-through (pmod) + slide-switch slot, +X edge, one end
    translate([board_w/2-wall_t-1, -board_l/2+end_margin+pmod[1]/2, floor_t+2])
      cube([wall_t+3, 9, 4], center=true);
    translate([board_w/2-wall_t-1, -board_l/2+end_margin+pmod[1]+8,
               floor_t+slide_sw[2]/2+1])
      cube([wall_t+3, slide_sw[0]+1, slide_sw[2]+1], center=true);
    for (pt = screw_pts) translate([pt[0], pt[1], floor_t])
      cylinder(d=insert_bore_d, h=tub_h);
  }
  // insert bosses
  for (pt = screw_pts) translate([pt[0], pt[1], floor_t])
    difference() {
      cylinder(d=insert_boss_od, h=interior_depth);
      cylinder(d=insert_bore_d, h=interior_depth+1);
    }
  // centred buzzer locating collar on the floor
  translate([0,0,floor_t]) difference() {
    cylinder(d=buzzer_d+3, h=3);
    translate([0,0,-eps]) cylinder(d=buzzer_d+1, h=3+2*eps);
  }
}
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

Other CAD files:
cad/variants/single-st7789-nfc.scad
cad/variants/single-st7789.scad

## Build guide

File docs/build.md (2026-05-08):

# Build & Run

## PC test (host)

```bash
cargo run -p mega-blastoise-test          # interactive stdin battle
cargo run -p mega-blastoise-test --release
cargo test -p mega-blastoise-test         # automated tests
```

| Mode | Command | What it does |
|---|---|---|
| Interactive (default) | `cargo run -p mega-blastoise-test` | Full battle over stdin — pick moves/switches when prompted |
| Automated tests | `cargo test -p mega-blastoise-test` | Board-event parsing, scripted effect pipeline, demo battle init |

## RP2040 firmware

Install the target once:

```bash
rustup target add thumbv6m-none-eabi
```

Build from the workspace root (pass target explicitly — `.cargo/config.toml` inside `mega_blastoise_fw/` is not applied for `-p` builds):

```bash
cargo build -p mega-blastoise-fw --target thumbv6m-none-eabi
cargo build -p mega-blastoise-fw --target thumbv6m-none-eabi --release
```

Or `cd` into the crate so its `.cargo/config.toml` sets the target automatically:

```bash
cd mega_blastoise_fw
cargo build --release
```

### Firmware size stats

Requires `llvm-size` (`rustup component add llvm-tools-preview`) or `arm-none-eabi-size`:

```bash
./scripts/fw-build.sh            # debug build + section totals
./scripts/fw-build.sh --release  # release build + stats (use this for flash/RAM checks)
```

Debug binaries include large `.debug_*` sections; use `--release` when checking against Pico flash/RAM limits.

## Flashing

Install probe-rs:

```bash
curl --proto '=https' --tlsv1.2 -LsSf https://github.com/probe-rs/probe-rs/releases/latest/download/probe-rs-tools-installer.sh | sh
source ~/.bashrc
```

Flash with a debug probe connected (Picoprobe, CMSIS-DAP, etc.):

```bash
cd mega_blastoise_fw
cargo run --release
```

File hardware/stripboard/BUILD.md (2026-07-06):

# Build instructions - Mega Blastoise single board (rev 3)

Generated from `gen_single_board.py` (netlist-verified: 118 pads, 65 cuts, 41 jumpers, 17 nets, no opens/shorts). Open `mega_blastoise_single_board.diy` in DIYLC alongside this - same layout.

**Coordinates** are `<column letter><hole number>` using the grid printed
on the board itself. All diagrams and coordinates view the **component
(top) side**, copper strips underneath - in this view the printed columns
read **X on the left through A on the right** (they read A..X only when
the copper side faces you). Holes are 1..55 top to bottom; P2 sits at the
top edge, P1 at the bottom.

Each section below is self-contained: solder its jumper wires (thin
insulated wire on the UNDERSIDE, soldered only at the two end holes), then
its components, then move to the next section.

## 0. Parts and tools

- 1x stripboard, 24 strips x 55 holes (A..X)
- 1x Raspberry Pi Pico + 2x20 male headers
- 14x 6 mm tactile switch (legs on a 0.2" x 0.3" footprint)
- 2x SSD1306 0.96" OLED (4-pin header: GND VCC SCL SDA)
- 2x WS2812B LED strip (off-board; 3 wires each)
- MB102 breadboard supply (5 V out) + 2 wires to the board
- ~41 insulated jumper wires, thin (30 AWG wire-wrap wire is ideal)
- spot face cutter (or 3 mm drill bit), soldering iron, multimeter

## 1. Mark and cut the tracks (65 cuts)

Do ALL cuts first - several strips are shared between sections, so cutting
later risks slicing under an already-soldered part.

Cuts are ON a hole (the hole is destroyed). These coordinates are the
board's own printed grid, so you can work directly on the copper side and
read the letters off the print - no mirroring in your head. Verify every
cut afterwards with a continuity meter (probe the two holes either side).

- **Pico line 1** - hole 46 across cols C..V (20 cuts)
- **Pico line 2** - hole 50 across cols C..V (20 cuts)
- **P1/P2 border** - hole 23 on cols D, F, G, I, K, L, M, N, O, Q, R, T, U (13 cuts)
- **Singles** - X3, X6, X9, N10, T13, I13, T30, I30, N35, X43, X46, B52

## 2. Pico and power rails

Wires first (they feed the rails from the Pico):

| net | wire (underside) |
|---|---|
| **3V3** | R48 -> B48 |
| **GND** | T48 -> W49 |

Then the Pico, on the TOP side, pin rows at holes 47 and 54, cols C..V:

- Orientation: **USB connector points LEFT** (toward col X).
- Pin 1 (GP0) is the **bottom-left** pin at V54.
- Top pin row = hole 47 (pins 40..21 left to right); bottom row = hole 54 (pins 1..20).
- VBUS (top-left pin, V47) is intentionally not connected.
- Solder headers to the Pico first, drop it in, check it sits between the
  two cut lines (holes 46 and 50 isolate its pin rows), then solder.

Rails after this section: **W = GND**, **B = 3V3**, **A = 5V**
(A stays dead until the MB102 section).

## 3. Button matrix (24 wires, 14 switches)

All the matrix nets - row nets GP5/7/8/9 and column nets GP10-13:

| net | wire (underside) |
|---|---|
| **GP5** | P52 -> Q42  ,  Q44 -> F44 |
| **GP7** | M52 -> R31  ,  R33 -> K33  ,  K31 -> D31 |
| **GP8** | L52 -> Q10  ,  Q12 -> F12 |
| **GP9** | K52 -> R10  ,  R12 -> K12  ,  K14 -> D14 |
| **GP10** | I52 -> T27  ,  T29 -> U29  ,  U26 -> G22  ,  G20 -> I19 |
| **GP11** | H52 -> I28  ,  I25 -> N5  ,  N7 -> N38  ,  N9 -> T16 |
| **GP12** | G52 -> G30  ,  G32 -> T32  ,  T34 -> U12  ,  U14 -> I10 |
| **GP13** | F52 -> I34  ,  I36 -> T10 |

Then the switches. Each spans two strips 3 columns apart; all four legs
get soldered:

| player | button | left legs (col, holes) | right legs (col, holes) |
|---|---|---|---|
| P2 | **S3** | U1 + U3 | R1 + R3 |
| P2 | **S2** | N1 + N3 | K1 + K3 |
| P2 | **S1** | G1 + G3 | D1 + D3 |
| P2 | **M4** | T5 + T7 | Q5 + Q7 |
| P2 | **M3** | I5 + I7 | F5 + F7 |
| P2 | **M2** | T20 + T22 | Q20 + Q22 |
| P2 | **M1** | I20 + I22 | F20 + F22 |
| P1 | **M1** | T24 + T26 | Q24 + Q26 |
| P1 | **M2** | I24 + I26 | F24 + F26 |
| P1 | **M3** | T39 + T41 | Q39 + Q41 |
| P1 | **M4** | I39 + I41 | F39 + F41 |
| P1 | **S1** | U43 + U45 | R43 + R45 |
| P1 | **S2** | N43 + N45 | K43 + K45 |
| P1 | **S3** | G43 + G45 | D43 + D45 |

P2's buttons are labeled from P2's seat: their M1 is at the board's
bottom-right of their screen (rows 20-22), their party row S1 S2 S3 reads
right-to-left in board coordinates. Follow the table and it comes out right.

## 4. OLED screens (8 wires, 2 modules)

I2C signals plus each screen's 3V3/GND taps to the rails:

| net | wire (underside) |
|---|---|
| **GP16** | C48 -> L30 |
| **GP17** | D48 -> M30 |
| **GP18** | F48 -> O15 |
| **GP19** | G48 -> N15 |
| **3V3** | M15 -> B15  ,  N32 -> B32 |
| **GND** | L15 -> W15  ,  O30 -> W30 |

Then the headers:

- **P1 OLED**: header at hole 27, screen hangs DOWN (rows 27-37). Pin order
  left to right: GND=O27, VCC=N27, SCL=M27, SDA=L27.
- **P2 OLED**: rotated 180 deg - header at hole 19, screen hangs UP (rows
  9-19). Pin order left to right: SDA=O19, SCL=N19, VCC=M19, GND=L19.
- Double-check your module silkscreen: if its pin order is not GND-VCC-SCL-SDA,
  tell the generator, do not improvise.

## 5. LED strip connectors (6 wires, left edge)

DIN feeds from the Pico plus the 5V/GND taps for each connector:

| net | wire (underside) |
|---|---|
| **GP20** | H48 -> X40 |
| **GP22** | K48 -> X1 |
| **5V** | X4 -> A4  ,  X45 -> A45 |
| **GND** | X7 -> W7  ,  X48 -> W48 |

The strips are off-board; their 3 wires each solder into column X:

- **LED strip P2** (top left edge): DIN=X2, 5V=X5, GND=X8.
- **LED strip P1** (bottom left edge): DIN=X41, 5V=X44, GND=X47.

## 6. MB102 supply input (1 wire)

| net | wire (underside) |
|---|---|
| **GND** | B54 -> W54 |

- **MB102 supply** (bottom right): "-" to B53, "+" to A53.
- Power plan: MB102 5V drives the LED strips via the A rail; the Pico
  runs from its own USB; grounds are shared through the W rail.

## 7. Test before power

With the meter on continuity, no power applied:

1. **Rails**: W2-W55 beeps (GND), B2-B46 beeps (3V3),
   A2-A55 beeps (5V). B53 must NOT beep to B2 (cut at
   B52), but B53-W2 must beep (shared GND).
2. **No rail shorts**: W-B, W-A, B-A all silent.
3. **Every button**: hold it pressed, meter from its row net Pico pin to its
   column net Pico pin - beeps pressed, silent released:

| net | Pico pin (physical) | net | Pico pin (physical) |
|---|---|---|---|
| GP5 (P1 moves) | 7 | GP10 (col 1) | 14 |
| GP7 (P1 party) | 10 | GP11 (col 2) | 15 |
| GP8 (P2 moves) | 11 | GP12 (col 3) | 16 |
| GP9 (P2 party) | 12 | GP13 (col 4) | 17 |

4. **OLEDs**: SDA/SCL of each header to Pico pins - P1: L27-pin21(GP16),
   M27-pin22(GP17); P2: O19-pin24(GP18), N19-pin25(GP19).
5. Plug in USB only (no MB102): OLEDs must come up. Then add the MB102 and
   the strips.

## 8. Firmware note

- No display flip needed: P2's OLED is physically rotated 180 deg AND P2
  views the board from the opposite side - the two rotations cancel, so the
  firmware renders both displays identically.
- Pin map is unchanged from the breadboard build (rows GP5/7/8/9, cols
  GP10-13, OLEDs GP16/17 + GP18/19, strips GP20/GP22).

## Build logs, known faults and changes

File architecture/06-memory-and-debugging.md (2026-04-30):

# Memory and Debugging

This page describes runtime diagnostics and troubleshooting flow.

## Heap Profiling

[`mem_profile.rs`](../mega_blastoise_fw/src/mem_profile.rs) provides:

- global heap allocator
- snapshot logging: `used`, `free`, `peak`, `total`

[`main.rs`](../mega_blastoise_fw/src/main.rs) and [`usb_input.rs`](../mega_blastoise_fw/src/usb_input.rs) emit snapshots at key points:

- boot/init checkpoints
- battle setup checkpoints
- prompt entry/exit checkpoints
- per-turn checkpoints (if enabled)

## Runtime Tracing

Current firmware logs include:

- typed event traces in [`board_effects.rs`](../mega_blastoise_fw/src/board_effects.rs)
- request and accepted-choice traces in [`usb_input.rs`](../mega_blastoise_fw/src/usb_input.rs)

This makes it easier to correlate:

1. what the battle engine requested,
2. what user input was accepted,
3. which events were emitted, and
4. where heap spikes happened.

## Recommended Debug Workflow

1. Reproduce quickly on host when possible.
2. On firmware, read heap snapshots near crash point.
3. Use input/event traces to identify exact stage of failure.
4. Reduce peak allocations in the implicated stage.

Continue with [Design Principles and Extension Guide](./07-design-principles.md).

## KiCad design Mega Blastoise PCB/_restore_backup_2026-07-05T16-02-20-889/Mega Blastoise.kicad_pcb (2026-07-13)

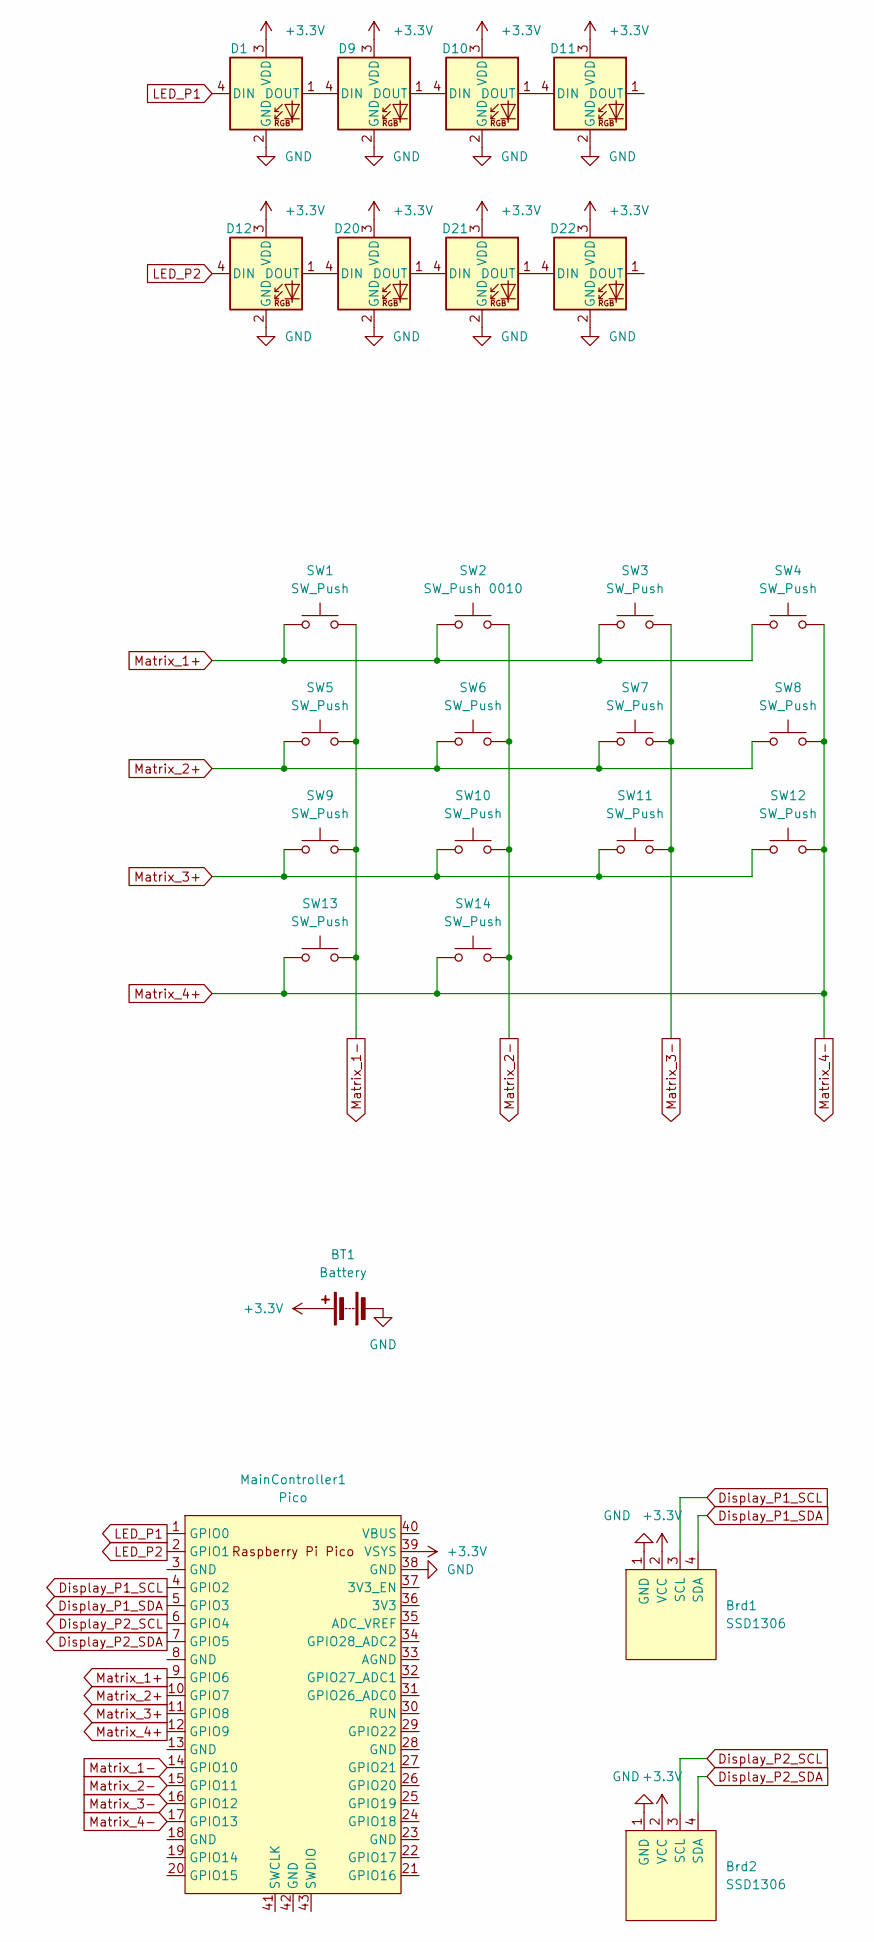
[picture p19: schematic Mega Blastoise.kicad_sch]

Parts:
BT1: Battery; PinHeader_1x02_P2.54mm_Vertical
Brd1, Brd2: SSD1306; PinHeader_1x04_P2.54mm_Vertical
D1, D12: NeoPixel_THT; neopixel 8 stick
D9, D10, D11, D20, D21, D22: NeoPixel_THT; Neopixel Breadboard
MainController1: Pico; RPi_Pico_SMD_TH
SW1, SW3, SW4, SW5, SW6, SW7, SW8, SW9, SW10, SW11, SW12, SW13, SW14: SW_Push; SW_PUSH-12mm
SW2: SW_Push 0010; SW_PUSH-12mm

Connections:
+3.3V: BT1.1 (+), Brd1.2 (VCC), Brd2.2 (VCC), D1.3 (VDD), D9.3 (VDD), D10.3 (VDD), D11.3 (VDD), D12.3 (VDD), D20.3 (VDD), D21.3 (VDD), D22.3 (VDD), MainController1.39 (VSYS)
Display_P1_SCL: Brd1.3 (SCL), MainController1.4 (GPIO2)
Display_P1_SDA: Brd1.4 (SDA), MainController1.5 (GPIO3)
Display_P2_SCL: Brd2.3 (SCL), MainController1.6 (GPIO4)
Display_P2_SDA: Brd2.4 (SDA), MainController1.7 (GPIO5)
GND: BT1.2 (-), Brd1.1 (GND), Brd2.1 (GND), D1.2 (GND), D9.2 (GND), D10.2 (GND), D11.2 (GND), D12.2 (GND), D20.2 (GND), D21.2 (GND), D22.2 (GND), MainController1.38 (GND)
LED_P1: D1.4 (DIN), MainController1.1 (GPIO0)
LED_P2: D12.4 (DIN), MainController1.2 (GPIO1)
Matrix_1+: MainController1.9 (GPIO6), SW1.1, SW2.1, SW3.1, SW4.1
Matrix_1-: MainController1.14 (GPIO10), SW1.2, SW5.2, SW9.2, SW13.2
Matrix_2+: MainController1.10 (GPIO7), SW5.1, SW6.1, SW7.1, SW8.1
Matrix_2-: MainController1.15 (GPIO11), SW2.2, SW6.2, SW10.2, SW14.2
Matrix_3+: MainController1.11 (GPIO8), SW9.1, SW10.1, SW11.1, SW12.1
Matrix_3-: MainController1.16 (GPIO12), SW3.2, SW7.2, SW11.2
Matrix_4+: MainController1.12 (GPIO9), MainController1.17 (GPIO13), SW4.2, SW8.2, SW12.2, SW13.1, SW14.1
unnamed: D1.1 (DOUT), D9.4 (DIN)
unnamed: D9.1 (DOUT), D10.4 (DIN)
unnamed: D10.1 (DOUT), D11.4 (DIN)
unnamed: D12.1 (DOUT), D20.4 (DIN)
unnamed: D20.1 (DOUT), D21.4 (DIN)
unnamed: D21.1 (DOUT), D22.4 (DIN)

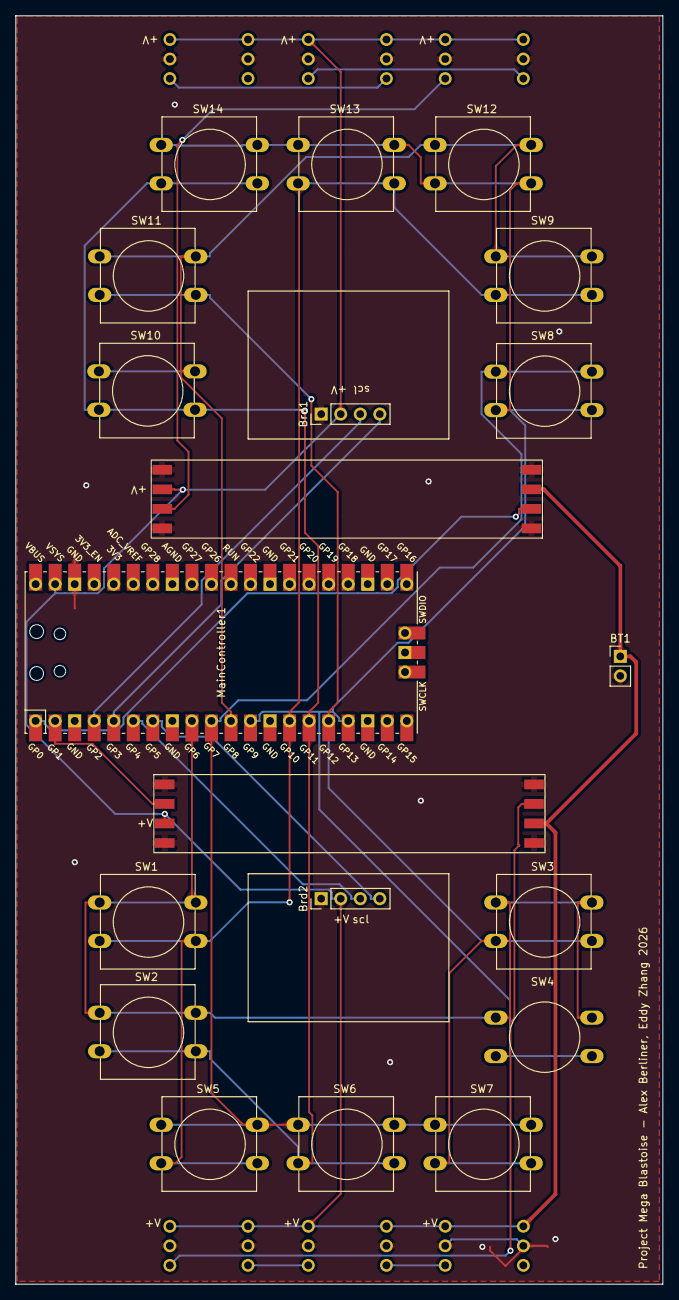
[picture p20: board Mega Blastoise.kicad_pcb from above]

Board: 2 copper layers, 84.1 x 164.9 mm, 26 parts (0 on the bottom side), 21 nets.

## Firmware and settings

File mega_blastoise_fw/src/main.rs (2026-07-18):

#![no_std]
#![no_main]

extern crate alloc;

mod battle_controller;
mod battle_effects;
mod lobby;
mod pico_battle_input;
mod subsystems;
mod usb_input;

use gen1_battle::TeamData;
use defmt::debug;
use embassy_executor::Spawner;
use embassy_rp::gpio::{Flex};
use embassy_time::{Instant, Timer};
use mega_blastoise_core::{
    battle_options_with_seed, demo_engine_opts, draw_two_randbat_teams, format_active_state, run_battle,
    BoardEventQueue, FlashDataStore, InputBus, InputSource,
};
use mega_blastoise_fw::mem_profile::init_heap;
#[cfg(feature = "mem-profile")]
use mega_blastoise_fw::mem_profile::heap_snapshot;
use mega_blastoise_fw as _;
use rtt_target::{rtt_init, set_defmt_channel};

use battle_controller::BattleController;
use battle_effects::BattleEffects;
use lobby::{run_lobby, LobbyResult};
use pico_battle_input::PicoBattleInput;

#[embassy_executor::main]
async fn main(spawner: Spawner) {
    let p = embassy_rp::init(Default::default());

    init_heap();
    #[cfg(feature = "mem-profile")]
    heap_snapshot("boot");

    // RTT up-buffer sized to capture a whole AI battle's OLED-framebuffer dump
    // (`oledfb|pN|<2 KB hex>` per frame change). gen1_battle's real heap peak is
    // ~3 KB (measured) so the 64 KB heap is far oversized; RAM is 256 KB, so we
    // spend the abundant free RAM on a large RTT buffer instead. Default
    // NoBlockSkip mode is kept deliberately: BlockIfFull throttles the firmware
    // to a crawl (battle can't finish in real time over RTT). A 96 KB buffer
    // absorbs the OLED burst between probe-rs drains so few/no frames drop.
    let channels = rtt_init! {
        up: { 0: { size: 96 * 1024, name: "defmt" } }
    };
    set_defmt_channel(channels.up.0);

    // ── USB CDC battle CLI ────────────────────────────────────────────────────
    #[cfg(feature = "usb")]
    let mut usb_input = {
        let input = subsystems::usb::init(p.USB, &spawner);
        debug!("USB ready. Connect with: picocom --echo -b 115200 /dev/ttyACM1");
        #[cfg(feature = "mem-profile")]
        heap_snapshot("after_usb_init");
        input
    };

    // ── Button matrix (see pico_battle_input's board tables) ─────────────────
    // Default: partner PCB — drives GP6/7/8/9, senses GP10-12 + GP9
    // (GP9/GP13 are one net on that board; GP13 stays unused).
    // `breadboard` feature: the hand-wired board — drives GP5/7/8/9,
    // senses GP10-13.
    #[cfg(feature = "breadboard")]
    let mut buttons = PicoBattleInput::new([
        Flex::new(p.PIN_5),
        Flex::new(p.PIN_7),
        Flex::new(p.PIN_8),
        Flex::new(p.PIN_9),
        Flex::new(p.PIN_10),
        Flex::new(p.PIN_11),
        Flex::new(p.PIN_12),
        Flex::new(p.PIN_13),
    ]);
    #[cfg(not(feature = "breadboard"))]
    let mut buttons = PicoBattleInput::new([
        Flex::new(p.PIN_6),
        Flex::new(p.PIN_7),
        Flex::new(p.PIN_8),
        Flex::new(p.PIN_9),
        Flex::new(p.PIN_10),
        Flex::new(p.PIN_11),
        Flex::new(p.PIN_12),
    ]);
    debug!("Button matrix ready");

    // ── Piezo buzzer (GP21 = PWM slice 2 channel B) ──────────────────────────
    #[cfg(feature = "buzzer")]
    {
        spawner.spawn(subsystems::buzzer::task(p.PWM_SLICE2, p.PIN_21))
            .expect("buzzer task spawn");
        debug!("Buzzer ready: GP21 / PWM2B");
    }

    // ── NeoPixel LED strips (WS2812B: P1 GP20/SM0/DMA0, P2 GP22/SM1/DMA1) ────
    #[cfg(feature = "leds")]
    {
        #[cfg(feature = "breadboard")]
        spawner.spawn(subsystems::led::task(
            p.PIO0, p.PIN_20, p.PIN_22, p.DMA_CH0, p.DMA_CH1,
        ))
        .expect("led task spawn");
        #[cfg(not(feature = "breadboard"))]
        spawner.spawn(subsystems::led::task(
            p.PIO0, p.PIN_1, p.PIN_0, p.DMA_CH0, p.DMA_CH1,
        ))
        .expect("led task spawn");
        #[cfg(feature = "breadboard")]
        debug!("LEDs ready: P1 GP20, P2 GP22 / PIO0 SM0+SM1 / DMA0+DMA1");
        #[cfg(not(feature = "breadboard"))]
        debug!("LEDs ready: P1 GP1, P2 GP0 / PIO0 SM0+SM1 / DMA0+DMA1");
    }

    // ── OLED displays (SSD1306 on I2C0 + I2C1) ───────────────────────────────
    #[cfg(feature = "oled")]
    {
        #[cfg(feature = "breadboard")]
        spawner.spawn(subsystems::oled::task(
            p.I2C0, p.PIN_17, p.PIN_16,  // P1: I2C0, SCL=GP17, SDA=GP16
            p.I2C1, p.PIN_19, p.PIN_18,  // P2: I2C1, SCL=GP19, SDA=GP18
        ))
        .expect("oled task spawn");
        #[cfg(not(feature = "breadboard"))]
        spawner.spawn(subsystems::oled::task(
            p.I2C1, p.PIN_3, p.PIN_2,    // P1: I2C1, SCL=GP3, SDA=GP2
            p.I2C0, p.PIN_5, p.PIN_4,    // P2: I2C0, SCL=GP5, SDA=GP4
        ))
        .expect("oled task spawn");
        debug!("OLEDs ready");
        #[cfg(feature = "mem-profile")]
        heap_snapshot("after_oled_init");
    }

    // ── Shared battle infrastructure ──────────────────────────────────────────
    let bus = InputBus::new();
    let mut queue = BoardEventQueue::new();

    debug!("Initialising data store...");
    let data = FlashDataStore::new();
    #[cfg(feature = "mem-profile")]
    heap_snapshot("after_datastore");

    // ── Game loop: lobby → battle → lobby → … ────────────────────────────────
    loop {
        // Lobby: demo AI battle plays until a player presses ready, then the
        // controls picker (part of the ready sequence) and the countdown.
        #[cfg(feature = "usb")]
        let LobbyResult { ai_players, modes, six_v_six, team_p1: up_p1, team_p2: up_p2 } =
            run_lobby(&mut buttons, &mut usb_input, &data, &mut queue).await;
        #[cfg(not(feature = "usb"))]
        let LobbyResult { ai_players, modes, six_v_six, team_p1: up_p1, team_p2: up_p2 } =
            run_lobby(&mut buttons, &data, &mut queue).await;

        queue.drain_pending(); // discard any demo events still queued

        #[cfg(feature = "usb")]
        {
            let seed = Instant::now().as_ticks();
            usb_input.set_ai_players(ai_players, seed);
            usb_input.set_modes(modes);
        }
        #[cfg(not(feature = "usb"))]
        {
            buttons.modes = modes;
        }

        let _ = ai_players; // used above under #[cfg(feature = "usb")]

        // Tell the shared display controller each player's control scheme
        // (concealed battle screens hide the move list).
        #[cfg(feature = "oled")]
        {
            use mega_blastoise_core::{ControlMode, OledCmd};
            for player in [1u8, 2] {
                subsystems::oled::send(OledCmd::SetControlMode {
                    player,
                    concealed: modes[(player - 1) as usize] == ControlMode::Concealed,
                });
            }
        }

        // Battle-start tutorial, 3 pages, 2.25 s each, not skippable.
        // Real games with a human only — never before demo / AI-vs-AI games.
        #[cfg(feature = "oled")]
        if !(ai_players[0] && ai_players[1]) {
            use mega_blastoise_core::display::TUTORIAL_PAGES;
            for page in 0..TUTORIAL_PAGES {
                subsystems::oled::send(mega_blastoise_core::OledCmd::ShowTutorial { page });
                Timer::after_millis(2250).await;
            }
        }

        // Draw teams from timing jitter (fresh entropy each round).
        let seed = Instant::now().as_ticks();

        let mut effects = BattleEffects::new(
            #[cfg(feature = "usb")] Some(&bus),
            #[cfg(not(feature = "usb"))] None,
            true,
        );

        let mut battle =
            gen1_battle::PublicCoreBattle::new(battle_options_with_seed(seed), &data, demo_engine_opts())
                .expect("battle init");
        #[cfg(feature = "mem-profile")]
        heap_snapshot("after_battle_new");

        // Use uploaded test teams when provided, else draw random ones.
        let (rand_p1, rand_p2) =
            draw_two_randbat_teams(seed, if six_v_six { 6 } else { 3 });
        let team_p1 = up_p1.unwrap_or(rand_p1);
        let team_p2 = up_p2.unwrap_or(rand_p2);
        #[cfg(feature = "leds")]
        let (p1_team_size, p2_team_size) = (team_p1.len() as u8, team_p2.len() as u8);
        battle.update_team("p1", TeamData { members: team_p1, ..Default::default() }).expect("p1");
        #[cfg(feature = "mem-profile")]
        heap_snapshot("after_team_p1");

        battle.update_team("p2", TeamData { members: team_p2, ..Default::default() }).expect("p2");
        #[cfg(feature = "mem-profile")]
        heap_snapshot("after_team_p2");

        battle.start().expect("battle start");
        #[cfg(feature = "mem-profile")]
        heap_snapshot("after_battle_start");

        debug!("Battle started.");

        // Light each player's full team green for the new battle (resets any
        // stale per-member state from the previous round).
        #[cfg(feature = "leds")]
        {
            use subsystems::led::{send as led_send, LedCmd};
            led_send(LedCmd::TeamInit { player: 1, size: p1_team_size });
            led_send(LedCmd::TeamInit { player: 2, size: p2_team_size });
        }

        #[cfg(feature = "usb")]
        {
            let mut controller = BattleController::new(usb_input, buttons);
            run_battle(&mut battle, &data, &bus, controller.run(&bus), &mut queue, &mut effects, |b| {
                for line in format_active_state(b).lines() {
                    let _ = bus.log.try_send(alloc::string::String::from(line));
                }
                #[cfg(feature = "mem-profile")]
                heap_snapshot("after_turn");
                for (action_type, ms) in b.drain_action_timings() {
                    defmt::info!("  action[{}]: {}ms", action_type, ms);
                }
            })
            .await;
            // Recover ownership of usb_input and buttons from the controller.
            let (u, b) = controller.into_parts();
            usb_input = u;
            buttons = b;
            usb_input.set_ai_players([false, false], 0);
        }

        #[cfg(not(feature = "usb"))]
        run_battle(&mut battle, &data, &bus, buttons.run(&bus), &mut queue, &mut effects, |b| {
            #[cfg(feature = "mem-profile")]
            heap_snapshot("after_turn");
            for (action_type, ms) in b.drain_action_timings() {
                defmt::info!("  action[{}]: {}ms", action_type, ms);
            }
        })
        .await;

        debug!("=== Battle over ===");
        // Brief pause so the win screen lingers after its 7.5 s hold.
        Timer::after_secs(4).await;

        // Post-game feedback QR on both displays: stays up until any button
        // press or 30 seconds, whichever comes first.
        #[cfg(feature = "oled")]
        {
            use pico_battle_input::PadScan;
            subsystems::oled::send(mega_blastoise_core::OledCmd::ShowQr);
            let mut qr_scan = PadScan::default();
            let _ = embassy_futures::select::select(
                buttons.next_pad_event(&mut qr_scan),
                Timer::after_secs(30),
            )
            .await;
        }
    }
}

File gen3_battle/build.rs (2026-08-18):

//! Emits the Gen 3 tables into `OUT_DIR/gen3_tables.rs`.
//!
//! Two sources, both already vendored in this repo:
//!
//!   * `../gen1_battle/data/type-chart.json` — the modern chart, read from the
//!     sibling crate rather than copied so the two generations cannot drift
//!     apart on the shared entries.
//!   * `vendor/showdown_gen3_{species,moves}.json` — the era-accurate Gen 3
//!     dex, dumped from Pokémon Showdown's gen3 mod (the parity harness's
//!     `dump` kind regenerates them). Species and moves come from here.
//!   * `../battler/battle-data/data/mons/gen{1,2,3}.json` — still merged, but
//!     ONLY for level-up learnsets, which the dumps do not carry.
//!
//! The species/move tables used to be built by stacking the battler files
//! forward (gen1 then gen2 then gen3). The fuzzer proved that direction wrong:
//! those files are overrides relative to the NEXT gen, so stacking them
//! forward leaked modern PP counts, Gen 6 base-stat buffs, and later forms
//! into a "Gen 3" dex. The Showdown dump is the same source the parity tests
//! validate against, which closes that loop.
//!
//! Gen 3 differs from the modern type chart in exactly two ways, both applied
//! below: Fairy does not exist yet (simply absent from `TYPE_NAMES`), and
//! Steel still resists Ghost and Dark, which both became neutral in Gen 6.
//!
//! Emits:
//!   pub const TYPE_COUNT: usize;
//!   pub static TYPE_CHART: [[TypeEffectiveness; TYPE_COUNT]; TYPE_COUNT];
//!   * `vendor/gen3randombattle.json` — Showdown's Gen 3 random battle sets,
//!     from pkmn.github.io, cached beside this crate so builds are offline.
//!     This is what a random battle actually draws from, and it is the same
//!     source `mega_blastoise_core` uses for Gen 1. Its sets are curated
//!     movesets per role, which is a different thing from "everything the
//!     species can learn by that level".
//!
//! Emits:
//!   pub const TYPE_COUNT: usize;
//!   pub static TYPE_CHART: [[TypeEffectiveness; TYPE_COUNT]; TYPE_COUNT];
//!   pub static SPECIES: &[SpeciesEntry];   // sorted by id
//!   pub static MOVES: &[MoveEntry];        // sorted by id
//!   pub static RANDBAT: &[RandbatSet];     // one per species/role pair

use std::{collections::BTreeMap, env, fs, path::PathBuf};

use serde_json::{Map, Value};

/// Attack/defence order for the chart. Must match `types::Type`'s discriminants.
const TYPE_NAMES: &[&str] = &[
    "Normal", "Fire", "Water", "Electric", "Grass", "Ice", "Fighting", "Poison", "Ground",
    "Flying", "Psychic", "Bug", "Rock", "Ghost", "Dragon", "Dark", "Steel",
];

/// (attacker, defender, x10 multiplier) where Gen 3 disagrees with the modern
/// chart the JSON describes.
const GEN3_PATCHES: &[(&str, &str, u8)] = &[("Ghost", "Steel", 5), ("Dark", "Steel", 5)];

/// The generations that make up Gen 3's tables, in merge order.
const LAYERS: &[&str] = &["gen1", "gen2", "gen3"];

/// Sentinel in a randbat slot meaning "use the move's own type".
const NO_TYPE_OVERRIDE: u8 = 17;

fn main() {
    let manifest = PathBuf::from(env::var("CARGO_MANIFEST_DIR").unwrap());
    let chart_path = manifest.join("../gen1_battle/data/type-chart.json");
    let data_dir = manifest.join("../battler/battle-data/data");
    println!("cargo:rerun-if-changed=../gen1_battle/data/type-chart.json");
    for layer in LAYERS {
        println!("cargo:rerun-if-changed=../battler/battle-data/data/mons/{layer}.json");
        println!("cargo:rerun-if-changed=../battler/battle-data/data/moves/{layer}.json");
    }

    let mut out = String::from("// @generated by gen3_battle/build.rs — do not edit.\n\n");
    emit_type_chart(&read_json(&chart_path), &mut out);
    println!("cargo:rerun-if-changed=vendor/showdown_gen3_species.json");
    println!("cargo:rerun-if-changed=vendor/showdown_gen3_moves.json");
    let dump_species = read_json(&manifest.join("vendor/showdown_gen3_species.json"));
    let dump_moves = read_json(&manifest.join("vendor/showdown_gen3_moves.json"));
    let learnsets = merge_layers(&data_dir.join("mons"));
    let move_ids = emit_moves(&dump_moves, &mut out);
    emit_species(&dump_species, &learnsets, &move_ids, &mut out);
    emit_randbat(&fetch_randbats(&manifest), &move_ids, &mut out);

    let dest = PathBuf::from(env::var("OUT_DIR").unwrap()).join("gen3_tables.rs");
    fs::write(&dest, out).unwrap_or_else(|e| panic!("write {}: {e}", dest.display()));
}

/// Showdown's Gen 3 random battle sets, cached so a build never needs the
/// network twice. Mirrors what `mega_blastoise_core` does for Gen 1.
fn fetch_randbats(manifest: &PathBuf) -> Value {
    let vendor = manifest.join("vendor");
    fs::create_dir_all(&vendor).unwrap();
    let cached = vendor.join("gen3randombattle.json");
    println!("cargo:rerun-if-changed=vendor/gen3randombattle.json");
    if !cached.exists() {
        let text = ureq::get("https://pkmn.github.io/randbats/data/gen3randombattle.json")
            .call()
            .unwrap_or_else(|e| panic!("fetch gen3 randbats: {e}"))
            .into_string()
            .unwrap_or_else(|e| panic!("read gen3 randbats: {e}"));
        fs::write(&cached, text).unwrap();
    }
    read_json(&cached)
}

/// Showdown keys its sets by display name ("Mr. Mime"); the dex is keyed by
/// id ("mrmime").
fn species_id(display: &str) -> String {
    display
        .chars()
        .filter(|c| c.is_ascii_alphanumeric())
        .flat_map(|c| c.to_lowercase())
        .collect()
}

fn read_json(path: &PathBuf) -> Value {
    let raw = fs::read_to_string(path).unwrap_or_else(|e| panic!("read {}: {e}", path.display()));
    serde_json::from_str(&raw).unwrap_or_else(|e| panic!("parse {}: {e}", path.display()))
}

/// Merge `gen1`, `gen2` and `gen3` from `dir`, later layers overriding earlier
/// ones field by field.
fn merge_layers(dir: &PathBuf) -> BTreeMap<String, Map<String, Value>> {
    let mut merged: BTreeMap<String, Map<String, Value>> = BTreeMap::new();
    for layer in LAYERS {
        let path = dir.join(format!("{layer}.json"));
        let obj = read_json(&path);
        let obj = obj
            .as_object()
            .unwrap_or_else(|| panic!("{} is not an object", path.display()));
        for (id, entry) in obj {
            let entry = match entry.as_object() {
                Some(e) => e,
                None => continue,
            };
            let slot = merged.entry(id.clone()).or_default();
            for (k, v) in entry {
                slot.insert(k.clone(), v.clone());
            }
        }
    }
    merged
}
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

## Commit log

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2026-04-28 add build.rs: codegen gen1 battle data from battler into flash tables
    Reads battler/battle-data/data at compile time, strips fields unused during
    battle (learnsets, fxlang blobs, forme cross-refs), and emits battle_data.rs
    into OUT_DIR with five static tables baked into flash:
    TYPE_CHART, ALIASES, CONDITIONS, SPECIES, MOVES
    Each is &[(&'static str, &'static str)] — ID to compact JSON. The firmware
    looks up by ID and deserializes on demand; battler's Dex layer caches the
    result so repeated lookups are free. Avoids maintaining any mirrored data.
    [build.rs]
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2026-04-28 mega-blastoise-core: embed gen1 abilities; fix type chart decode
    Parse type effectiveness from the embedded "types" table (build.rs emits
    per-key fragments). Include abilities/gen1.json so Dex can resolve abilities.
    Remove obsolete single-crate root sources replaced by workspace members.
    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
    [build.rs, main.rs]
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2026-04-28 Add BattleEffects hooks for board LEDs/SFX and simplify test narration
    Introduce BattleEffects and ParsedBattleLogLine in mega-blastoise-core so
    new_log_entries can drive hardware or a host stand-in. Firmware drains logs
    through DefmtBattleEffects (RTT + stubs for damage/move/faint). Interactive
    test uses BoardGameEffects with short plain-English lines instead of raw logs.
    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
    [main.rs]
2026-04-29 Refactor to typed BoardEvent flow and test harness
    - Add board_event: BoardEvent, PromptKind, parse_log_line, board_prompt_event,
    ParsedBattleLogLine, shared descriptions
    - Replace string-based BattleEffects with BoardEffects + BoardEventQueue +
    process_new_log_lines; add NoopBoardEffects
    - Host: BoardGameEffects calls on_event; harness with interactive battle and
    --self-test scripted events
    - Firmware: DefmtBattleEffects + queue; prompt events before read_choice
    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
    [main.rs]
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2026-04-29 Switch firmware to defmt 1.0 / rp-pico bringup for RTT verification
    Upgrades defmt/defmt-rtt/panic-probe to 1.0 to fix the missing .defmt
    section error with probe-rs 0.31. Embassy deps commented out temporarily
    while confirming RTT output works end-to-end with the rp-pico HAL hello world.
    [main.rs]
2026-04-29 Restore full embassy firmware with defmt 1.0 logger
    Replaces rp-pico bringup stub with the full embassy-rp battle firmware.
    lib.rs now owns defmt-rtt + panic-probe setup; main.rs pulls it in via
    `use mega_blastoise_fw as _`. defmt/defmt-rtt/panic-probe stay on 1.0.
    [main.rs]
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2026-04-30 Add USB CDC battle CLI and async BattleInput trait
    - BattleInput::read_choice is now async (nightly AFIT); run_battle is async with an on_turn callback
    - Firmware battle CLI uses embassy-usb CDC ACM (ttyACM1) instead of RTT down-channel, which probe-rs doesn't forward
    - UsbBattleInput handles \r and \n as line terminators so picocom Enter works
    - Upgraded embassy-rp 0.3→0.8, embassy-executor 0.6→0.9, embassy-time 0.4→0.5; switched to rtt-target 0.6 for defmt logger
    - PN532 I2C errors downgraded to trace! to suppress NAK spam at info log level
    - Test crate drives async run_battle via pollster::block_on
    [main.rs]
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2026-04-30 Add detailed runtime battle tracing and split architecture docs.
    Expand firmware logging for events, requests, and accepted choices to improve on-device debugging, and replace the single architecture doc with linked topic-focused pages.
    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
    [main.rs]
2026-05-01 Replace BattleInput trait with InputBus channel for multi-source input
    Removes the pull-based BattleInput async trait and replaces it with a
    push-based InputBus (embassy-sync Channel + Signal) so multiple input
    sources (USB serial, physical buttons, NFC) can run concurrently via
    embassy_futures::join without requiring 'static lifetimes.
    [main.rs]
2026-05-01 fw: UsbBattleEffects, USB input plumbing, and CDC loopback RTT
    - Add UsbBattleEffects to forward BoardEvent text over InputBus and RTT
    - Refactor usb_input and core battle runner/input hooks for USB logging path
    - usb_loopback: init heap, echo CRLF per line, flush on CR with LF skip for CRLF,
    human-readable defmt lines on SWD
    - main: wire UsbBattleEffects and fix mem_profile import path
    [main.rs]
2026-05-04 Modularize firmware: feature-gated subsystems, unified input/effects
    - Add Cargo features: usb, nfc, mem-profile (all default on)
    - Extract USB CDC-ACM init into subsystems/usb.rs
    - Extract I2C + PN532 init into subsystems/nfc.rs
    - Add InputSource trait to core; run_battle now takes &mut impl InputSource
    and owns the join internally — callers no longer manage concurrency
    - Add NoInput (pends forever) for the no-USB build path
    - Collapse UsbBattleEffects + DefmtBattleEffects into a single BattleEffects
    with Option<&InputBus> checked at runtime (one branch per event)
    - main.rs reduced to thin orchestrator with cfg only at input binding sites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
    [main.rs]
2026-05-05 Fix USB battle loop, add player-facing output, and closed-loop hw test
    - Replace Signal with Channel<1> for bus.prompt so prompt/choice cycles
    are consume-once; fixes the sticky-signal bug that caused USB to
    re-enter the same prompt without waiting for the engine.
    - run_battle now takes F: Future<Output=()> instead of I: InputSource,
    letting callers compose any number of input sources with join().
    - board_event descriptions rewritten as player-facing battle narrative
    ("Charizard used Flamethrower!") instead of hardware-cue strings.
    - board_effects.rs renamed to battle_effects.rs; RTT game-text logging
    removed — game events flow only through bus.log → USB.
    - USB CLI gains [OK]/[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
    [main.rs]
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2026-05-05 Wire up physical button input; fix USB echo feedback loop
    - Remove firmware local echo and add 5ms drain_rx() to break the
    TTY echo feedback loop that was causing event strings to be
    re-processed as user input
    - Rewrite PicoBattleInput to fully async using embassy select/select3/select4
    with array destructuring for simultaneous GPIO pin borrows
    - Add BattleController to race USB and physical buttons per prompt;
    first input source to answer wins
    - Remove bind_interrupts! for GPIO (embassy-rp 0.8 handles this internally)
    - Fix mb_usb_send/mb_usb_init to disable HUPCL so termios isn't reset
    [main.rs]
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2026-05-07 Add button matrix, buzzer, and OLED subsystems with host parity
    Button matrix (GP6-9 row outputs, GP10-13 col inputs): replaces the
    individual-pin approach with the 4×4 matrix from ELECTRONICS.md. P1
    uses rows 0/1, P2 uses rows 2/3; player routing threaded through usb_input.
    Buzzer (GP21/PWM2B): async embassy task plays tones for hit, faint, and
    win via a CriticalSection channel so on_event stays synchronous.
    OLED (SSD1306 on I2C0/I2C1): blocking-I2C task renders player label, active
    mon name, and HP bar on each player's 128×64 display. Receives commands via
    a static channel from BattleEffects::on_event.
    Host test parity: HostBuzzer and HostOled stubs mirror the same event
    surface (hi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
    [buzzer.rs, main.rs, oled.rs]
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2026-05-07 Wire up gameplay events: supereffective, miss, crit, status, cant, fail, etc.
    Add BoardEvent variants for SuperEffective, Resisted, Immune, Miss,
    CriticalHit, SetStatus, CureStatus, Cant, Fail with human-readable
    descriptions and parse_log_line arms for each.
    SuperEffective and CriticalHit trigger buzzer cues in both fw
    (BuzzerCmd::SuperEffective / Crit) and host stubs. Crit uses a
    double-pulse at 1760 Hz.
    Pure engine bookkeeping lines (residual, continue, info, side, player,
    teamsize) are suppressed in parse_log_line rather than emitted as Raw noise.
    [buzzer.rs]
2026-05-07 Fix win/tie OLED: pass winning side so correct display shows WINNER!
    OledCmd::Win and HostOled::win now take winner: u8 (1=p1, 2=p2, 0=tie).
    Both on_event handlers extract the winning side from BoardEvent::Win { side }
    and route the message correctly. Tie shows TIE! on both displays.
    [oled.rs]
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2026-05-08 Fix fw build: wire run_battle data arg, ButtonSource wait_action
    run_battle gained a DataStore parameter; both call sites in main.rs
    were missing &data. CombinedButtonSource and UsbButtonInput still
    implemented the old wait_move (dropped from the trait) instead of the
    new wait_action → PlayerAction interface; updated both.
    [main.rs]
2026-05-08 Fix 6: USB path uses ButtonBattleController, not legacy BattleController
    subsystems/usb::init now returns UsbButtonInput; main.rs constructs
    ButtonBattleController so the USB + GPIO path runs through the shared
    ButtonController protocol logic (disabled-move filtering, voluntary
    switch handling) — the same path the test client uses.
    [main.rs]
2026-05-08 Fix 3+4: randbat teams on firmware; timing-based battle seed
    Firmware now draws random Gen 1 teams via draw_randbat_team instead
    of the fixed demo teams, so each convention match is a unique matchup.
    The seed comes from embassy_time::Instant::now().as_ticks() — USB
    enumeration jitter makes it different every boot, giving non-repeating
    damage rolls and team composition without a hardware RNG.
    Added battle_options_with_seed(u64) to core; demo_battle_options()
    is unchanged so host tests keep their deterministic seed.
    [main.rs]
2026-05-08 Fix 2: unify OLED rendering — single render_player_screen for host and fw
    render_player_screen now takes hp_pct and draws the HP bar, so host
    and firmware share one layout. Firmware oled.rs drops its local
    render() in favour of the core function; OledCmd gains MovesUpdate so
    move names appear at screen corners just like the test client.
    host_oled.rs tracks hp_pct per player and calls update_hp() on
    Damage/Heal events. battle_effects.rs forwards enriched SwitchIn
    moves to the OLED task at switch time.
    [oled.rs]
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2026-05-08 Restore USB battle terminal; fix fw-build linker path; add hw-shell script
    - fw: revert USB path from UsbButtonInput back to UsbBattleInput/BattleController
    so the USB CDC port shows the full interactive terminal (game state, move
    prompts, [EVT] events) instead of being input-only
    - fw-build.sh: run cargo from mega_blastoise_fw/ so .cargo/config.toml linker
    flags (-Tlink.x, -Tdefmt.x, --nmagic) are picked up; building from workspace
    root silently dropped them, producing ELF with wrong flash addresses
    - test: move [RTT] eprintln! to println! so both USB and RTT streams go to stdout
    - test: add default-run to Cargo.toml so cargo run -p works without --bin
    - scripts/hw-shell.sh: new int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
    [main.rs]
2026-05-08 Log try_send drops in LED, buzzer, and OLED subsystems
    Replace silent .ok() with defmt::warn! so channel saturation is
    visible in RTT rather than causing silent missed updates.
    [buzzer.rs, led.rs, oled.rs]
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2026-05-09 Replace JSON DataStore encoding with CBOR; add binary search
    build.rs now encodes each battle data entry (species, moves, conditions,
    abilities, type chart, aliases) as CBOR bytes using ciborium instead of
    JSON strings. data_store.rs decodes with ciborium::de::from_reader and
    uses binary_search_by on the pre-sorted tables instead of a linear scan.
    CBOR is self-describing (supports serde_json::Value fields and
    serde(flatten) in the battler types), ~13% smaller than the JSON
    representation in flash (143KB vs 165KB), and significantly faster to
    decode on Cortex-M0+ since it avoids text tokenisation and
    number-string conversion.
    TYPE_CHART integers are normalized to f64 before encoding because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
    [build.rs]
2026-05-09 Guard OLED send() behind READY flag to prevent channel stall on init failure
    If the display task exits early (I2C init error), the static channel was
    left unread — filling up and dropping commands that stalled the game loop.
    READY is set only after both displays initialize successfully.
    [oled.rs]
2026-05-09 Consolidate prompt display into shared prompt_fmt module in core
    USB device and test client previously had parallel, diverging display
    logic. Prompt formatting (move list, bench, types, ability, boosts) and
    the post-turn active-state dump now live in mega_blastoise_core::prompt_fmt
    and are called by both sides. USB prompt gains types, ability, and a
    post-turn state dump (via bus.log) that it was missing.
    [main.rs]
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2026-05-09 Add lobby: AI demo battle + ready-up + countdown before each match
    Boot flow: Demo (AI vs AI, interruptible) → Waiting (per-player ready
    toggle) → 3-2-1 countdown → real battle → back to demo.
    - lobby.rs: DemoAi (splitmix64 random moves), run_demo_battle (races
    run_battle against any button press via select), ReadyState, run_lobby
    (USB + button variants)
    - led.rs: LobbyIdle (breathing animation), LobbyWaiting (per-player
    ready color), LobbyCountdown (flash); pending-command pattern for
    animated states
    - buzzer.rs: CountdownBeep (660 Hz, 80 ms)
    - pico_battle_input.rs: LobbyPress enum, wait_any_lobby_press,
    wait_lobby_press
    - usb_input.rs: LobbyUsbCmd, read_lobby_cmd, write_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
    [buzzer.rs, led.rs, main.rs]
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2026-05-09 Fix web UI issues 7,1,2,3,6 + mobile layout
    alive_count by slot (#7): both firmware and web now track party members by
    name ([Option<([u8;12],u8)>; 3] in firmware, [Option<String>; 3] in web).
    SwitchIn registers the name; Faint looks up and clears the matching slot.
    Also fixes LED hp_pct not resetting on SwitchIn in the web target.
    P2 LED DOM order (#1): reversed led-12..led-23 in HTML so status/party LEDs
    nearest the center match the Rust data layout (status at index 23, HP at
    12-19). CSS size classes now match the correct indices.
    Lobby LED animation (#2): get_led_state() returns an animated blue-purple
    breathing frame while LOBBY_MODE is active, matching the firmware LobbyIdle
    animation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
    [led.rs]
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2026-05-10 Add render_pokemon_stats to core; wire to all targets
    - PartySlotData + party_slot_from_mon in core/display.rs: lightweight
    snapshot of a MonBattleData for display use (avoids caching the full
    struct on embedded hardware)
    - render_pokemon_stats: draws name/level, HP+status, Atk/Def/Spe/Spc,
    types onto any 128×64 DrawTarget — same rendering path for OLED,
    WASM, and any future target
    - Firmware: on_prompt sends OledCmd::PartyUpdate at each prompt;
    long-press switch button sends ShowPokemonStats; same 500ms timing
    as move long-press; works in both wait_action and wait_switch phases
    - Web: update_party caches PartySlotData at each prompt; wasm_show_pokemon_stats
    direct WASM expo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
    [oled.rs]
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2026-05-10 Parallel prompts, unready screen, LED/OLED polish
    - Both players are now prompted simultaneously: battle_loop collects all
    active requests and sends all prompts to bus.prompt before collecting
    any choices; ButtonController drains all queued prompts and fires
    on_prompt for every player before waiting on anyone — fixes P2 party
    LEDs being blank during P1's turn on the first round
    - After pressing a move, OLED shows active mon name + "Waiting... / tap
    to unready"; any button press within 1 s cancels and re-prompts
    - Selecting a fainted Pokémon flashes "Already fainted!" for 600 ms
    instead of the waiting screen, then restores the pick screen
    - AI opponent skips both the waiting sc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
    [oled.rs]
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2026-05-10 Refactor: abstract lobby input, deduplicate RNG/AI, gate OLED, remove dead code
    - Lobby logic extracted to run_lobby_inner with zero #[cfg] — it only
    sees LobbyEvent values from a LobbyInput trait; USB and buttons are
    completely invisible to the game logic
    - UsbButtonLobbyInput and ButtonOnlyLobbyInput implement LobbyInput;
    both lobby variants return [bool; 2] AI flags
    - Duplicate countdown functions merged into single do_countdown(input)
    - run_demo_battle no longer takes buttons; interrupt is handled by the
    outer select in run_lobby_inner
    - SimpleRng and RandomAi extracted to core; DemoAi wraps RandomAi;
    UsbBattleInput.make_ai_choice replaced by ai.make_choice
    - Dead code remove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
    [main.rs]
2026-05-10 fw: async OLED I²C flush; fix stale party data in Switch prompt
    - oled.rs: switch from blocking to async I²C (Ssd1306Async / I2c::new_async
    with bind_interrupts!). The ~20 ms framebuffer flush now yields to the
    executor in small chunks instead of stalling the task solid.
    - Cargo.toml: add ssd1306 async feature; Cargo.lock updated accordingly.
    - usb_input.rs: in the Switch request branch, prefer the fresh player_data
    that arrives with the prompt (reflects the faint that triggered the switch)
    over last_player_data from the previous Turn. Fixes the party listing
    showing a just-fainted Pokémon at its pre-faint HP instead of 0.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
    [oled.rs]
2026-05-10 Add lobby AI selection via long-press on any button
    Short press marks a player human-ready; long press (≥500 ms) marks that
    player as human-ready and sets their opponent as AI, starting the battle
    without requiring the other player to press.
    Firmware: LobbyPress gains P1Long/P2Long via timed hold detection in
    wait_lobby_press; P1Long → VsAi (P2 is AI), P2Long → P1Ai (P1 is AI).
    OledCmd::LobbyState drives per-player lobby screens: idle shows
    "PRESS READY / HOLD FOR AI", ready shows "READY!" or "AI".
    Unready events clear AI flags so the selection can be changed.
    Web: draw_lobby_screen mirrors firmware states on the OLED canvases.
    is_lobby_mode() and wasm_lobby_long_press(player) WASM e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
    [oled.rs]
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2026-05-11 Extract CLI parsing to core; add team_slot to BoardEvent
    Move USB serial input parsing (turn/switch/lobby commands) into
    mega_blastoise_core::cli_parse so firmware and test code share one
    canonical parser. LobbyCmd replaces the local LobbyUsbCmd enum in
    usb_input.rs (re-exported as LobbyUsbCmd for compat).
    BoardEvent::Faint and SwitchIn gain an optional team_slot field
    (populated by the battle runner from query_active_moves); parse_log_line
    initialises it to None.
    usb_input.rs is simplified significantly now that parse_turn_line /
    parse_switch_line / parse_lobby_cmd handle the parsing logic.
    set_ai_players clears last_typed_line so stale input doesn't replay.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
    [buzzer.rs, led.rs]
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2026-05-11 Fix all compile warnings in firmware
    - battle_effects: rename team_slot → _team_slot in Faint/SwitchIn;
    rename mon/_status in SetStatus/CureStatus and move cfg(leds) guard
    outward so bindings are always underscore-prefixed when unused
    - oled: remove unused embedded-graphics imports
    - usb_input: remove unused LobbyCmd/PlayerAction imports; restructure
    handle_meta_cmd as a match expression to remove unreachable None
    [oled.rs]
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2026-05-15 Replace battler engine with gen1_battle (40× less heap, no crashes)
    The battler crate's 13KB-per-Pokemon footprint exhausted the 128KB heap
    during 3v3 demo battles, crashing on the first SwitchIn's CBOR decode.
    This swaps in a new from-scratch Gen 1 cartridge-accurate engine:
    - 151 species + 167 moves as flash-resident const tables (~10KB flash,
    generated by build.rs from vendored JSON)
    - Per-mon runtime state ~64B; full 6v6 battle state ~1KB
    - Cartridge-accurate damage formula, crit/accuracy rolls, type chart,
    status (PSN/BRN/FRZ/PAR/SLP/BadPSN), volatiles, turn order, and
    ~30 MoveEffectKind variants with the famous special cases dispatched
    in dispatch.rs (Counter, M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
    [build.rs, data.rs, main.rs]
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2026-05-15 Add :team lobby command to upload test teams for p1/p2
    New USB lobby command lets you supply explicit teams for a real battle
    instead of the random draw, for testing specific matchups:
    :team p1 snorlax:bodyslam:earthquake:rest:hyperbeam
    :team p2 alakazam:psychic:recover:thunderwave:seismictoss
    :ready
    Syntax: `:team pN SPECIES[:MOVE…][,SPECIES…]` — up to 6 mons, up to 4
    moves each, level fixed at 100, defaults to `tackle` if no moves given.
    Species/move strings are canonicalized + validated by gen1_battle's
    update_team.
    Implementation:
    - core::parse_team_spec parses the line into (player, Vec<MonData>);
    LobbyCmd gains a payload-free UploadTeam variant (keeps PartialEq)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
    [main.rs]
2026-05-15 Add :oledlog runtime toggle to dump OLED framebuffers over RTT
    New `:oledlog on` / `:oledlog off` USB command (default OFF) that, when
    enabled, renders each OLED framebuffer over RTT every time it changes.
    Format matches the existing `:oled` one-shot dump (32 rows × 128
    half-block chars).
    - OLED_DUMP AtomicBool (init false) gates a dump_fb_rtt() call added
    to store_shadow() — the single chokepoint hit after every flush /
    screen render for either player
    - dump renders into a fixed stack buffer (no heap) and emits
    line-by-line via defmt::info!
    - toggle lives in handle_meta_cmd, which read_line() routes for both
    lobby and in-battle input, so it works at any time; the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
    [oled.rs]
2026-05-15 Rebalance RAM: heap 128->64 KB, RTT buffer 4->32 KB
    With battler replaced by gen1_battle, measured heap peak during a live
    battle is ~4 KB (vs battler's 115 KB that forced the old 128 KB heap).
    64 KB keeps ~16x headroom over peak.
    The freed 64 KB more than covers the RTT buffer growth (4 -> 32 KB),
    which the :oledlog dump and trace output need — a single full
    framebuffer dump is ~4 KB, so the old buffer overflowed on any burst
    and defmt silently dropped frames. 32 KB holds ~8 dumps of slack.
    Net effect (verified via nm + hardware):
    HEAP_MEM 128 KB -> 64 KB
    RTT buffer 4 KB -> 32 KB
    stack ~109 KB -> ~145 KB (net .bss shrank 36 KB)
    Hardware: boots clean, RTT block relocate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
    [main.rs]
2026-05-15 Add `oledlog` cargo feature to boot with OLED RTT dump enabled
    The OLED dump was runtime-only (default off, per-boot, opt-in via
    `:oledlog on`). Add a compile-time `oledlog` feature so a debug build
    boots with it already on:
    OLED_DUMP = AtomicBool::new(cfg!(feature = "oledlog"))
    - `cargo build` -> dump OFF at boot (unchanged)
    - `cargo build --features oledlog` -> dump ON at boot
    - `:oledlog on|off` still flips it at runtime either way
    Verified on hardware: feature build emits framebuffer dumps from boot
    with no command sent; default build stays at 4 boot lines until
    `:oledlog on`.
    [oled.rs]
2026-05-16 Surface battle events to board protocol; fix the two stalls it exposed
    gen1_battle now emits real board-protocol log lines (push_board:
    move|… damage|… switch|… faint|… etc.) instead of human-readable
    strings. Previously mega_blastoise_core's board parser silently
    ignored the human strings, so zero BoardEvents flowed — the battle
    ran but produced no OLED/LED/buzzer narration.
    Surfacing the events exposed two latent bugs that were never hit
    while events were being dropped:
    1. BattleEffects::on_event applies a per-event animation delay
    (Timer::after_millis: Move 2400ms, SwitchIn 2100ms, Faint 3600ms,
    Win 7500ms). With events finally flowing, every event slept and the
    demo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
    [oled.rs]
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
